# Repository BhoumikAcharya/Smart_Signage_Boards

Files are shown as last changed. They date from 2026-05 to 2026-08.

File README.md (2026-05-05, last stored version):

**Modbus-to-MQTT Bridge for Metro Emergency Signage**

1. Overview Of the Product - 

  This project is a smart EROS, designed for reliable operation in public transit environments like metros and railways. It implements a robust communication bridge on a Raspberry Pi, designed to integrate a central industrial control system (using Modbus) with a distributed network of wireless emergency signs (using MQTT), all through ethernet connectivity. Making the product implemented on a complete local network.
  
  This architecture allows a PLC or a central control room to instantly and reliably activate or change emergency signage across multiple locations in a station or tunnel, using a combination of industrial-grade protocols and modern IoT technology.

2. System Architecture

  The project is built on a decoupled, hub-and-spoke architecture, which is ideal for critical systems:

  Central Control (PLC/Modbus Master): The primary industrial controller, located in a central control room. It initiates commands by sending standard Modbus "Write Multiple Holding Registers (16(0x10))" requests to the Raspberry Pi.
    
  2.1. Raspberry Pi (The Bridge & Broker): This is the core of the system and performs three critical roles simultaneously.
    
  2.2. Modbus TCP Server: A Python script runs continuously, listening for commands from the central controller and updating an internal data model.
    
  2.3. MQTT Broker: The industry-standard Mosquitto broker runs as a service, managing all communication with the wireless signage units.
    
  2.4. Industrial HMI: A 7inch Capacitive touch HMI is connected to the RaspberryPi with manual override.
    
  2.5. Emergency Signs (ESP32 Clients): Each emergency light signage unit is powered by an ESP32.
    
  2.6. The ESP32s connect to the Raspberry Pi over Ethernet with a ETH PHY module called the LAN8720 with MQTT communication.
    
  2.7. They subscribe to specific MQTT topics and wait for commands.
    
  2.8. They are responsible for the final physical action—activating the LEDs via a relay.

3. Features - 
  
  3.1. Protocol Bridging: Seamlessly translates industrial-grade Modbus TCP commands into lightweight MQTT messages suitable for wireless IoT devices.
  
  3.2. Real-Time, Reliable Control: Uses a multi-threaded approach on the Raspberry Pi to ensure low latency between receiving a Modbus command and publishing the corresponding MQTT message.
  
  3.3. Scalable: Easily add or remove signage units across a station without any changes to the central controller or bridge logic. Each sign only needs to know the broker's address and its unique topic.
  
  3.4. Decoupled & Robust: The central controller does not need to know anything about the individual signs, and the signs do not need to know about the controller. This separation makes the system highly reliable and easy to maintain.
  
  3.5. Custom Logic: The bridge script contains specific control logic, allowing complex actions to be easily implemented.
  
  3.6. Diagnostics data: Diagnostics data of the LEDs, ESP32, PSU Failure and the Battery(battery diagnostics still in development) are communicated through MQTT to the RaspberryPi.

4. Hardware Components - 

  This is the list of components that i have used (feel free to experiment on your own as well)
  
    Raspberry Pi 5(8GB RAM with Ethernet)
    
    ESP32 Development Board (DevKit 1)
    
    LAN8720 ETH PHY Module for the ESP32
    
    2x ACS712 5A/20A Current Sensor
    
    5V Dual Channel Relay Modules (to switch power to the LED signage)
    
    2x 12V 12W LEDs
    
    PLC or Modbus Master Simulator (like OpenModscan) for testing
    
    14.5V PSU (Preferrably a battery charger w/o XT60 connectors)
    
    12.8V LFP Battery (For ample battery backup)
    
    7inch Capacitive Touch Display for HMI

5. Software & Libraries - 

  5.1. Raspberry Pi:
  
    Raspberry Pi OS
  
  Python 3
  
    Mosquitto (MQTT Broker)
    
    Pymodbus (Python Modbus Library)
    
    Paho-MQTT (Python MQTT Client Library)
  
  5.2. ESP32:
  
    Arduino IDE or PlatformIO
    
    PubSubClient (Arduino MQTT Library)
  
  5.3. Modbus Master: 
  
    OpenModscan (For testing the control values in the Holding Registers of the PLC)

6. How It Works
  The central control room's PLC sends a Modbus command (e.g., writing a value from 0-3 in a holding regiter(40001-40010)) to the Raspberry Pi's IP address on port 502.

  The Python Modbus server script running on the Pi receives the command and updates its internal datastore.

  A dedicated "bridge" thread in the script detects this state change.

  The script, acting as an MQTT client, connects to the local Mosquitto broker and publishes a message (e.g., payload ON) to a predefined topic (e.g., metro/station1/platformA/emergency_exit/set).

  The Mosquitto broker forwards this message to all signs subscribed to that topic.

  The target ESP32 receives the ON message, and its code executes the physical action—toggling a GPIO pin to activate its connected relay and light up the sign.

7. Setup & Usage (Needs to be updated)
7.1. Raspberry Pi Setup
  Install the necessary software on your Raspberry Pi:

  # Install MQTT Broker
    sudo apt-get update
    sudo apt-get install mosquitto mosquitto-clients -y
    sudo systemctl enable mosquitto.service

    sudo systemctl restart mosquitto.serivce (To restart the mosquitto service)

# Install Python libraries
    pip3 install pymodbus paho-mqtt

  Set the static IP of the RaspberryPi

7.2. ESP32 Setup
  Open the esp32_mqtt_client.ino sketch in the Arduino IDE.

Update the Wi-Fi credentials and the Raspberry Pi's IP address in the configuration section.

Upload the sketch to each of your ESP32 boards. Ensure each sign that needs to be controlled independently is configured to subscribe to a unique MQTT topic.

3. Running the Bridge
Execute the main bridge script on the Raspberry Pi. It requires root privileges to bind to the privileged Modbus port (502).

sudo python3 modbus_mqtt_bridge.py

The system is now live. Commands sent from the PLC will be wirelessly relayed to the emergency signs.

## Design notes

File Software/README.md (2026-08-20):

<div align="center">

# Node Calibration Utility

*Desktop commissioning tool for the I2ST smart-signage system*

**Configure, calibrate and deploy ESP32 edge controllers — over USB serial or the network — and record it only when the device confirms.**

**Version 2.0.0** &nbsp;·&nbsp; Windows Forms (.NET 10) &nbsp;·&nbsp; C# 12 &nbsp;·&nbsp; SQL Server LocalDB







</div>

---

## Table of Contents

1. [Overview](#1-overview)
2. [Architecture & Flow Charts](#2-architecture--flow-charts)
3. [Database Schema](#3-database-schema)
4. [Device Communication](#4-device-communication)
5. [How the Application Works — Module by Module](#5-how-the-application-works--module-by-module)
6. [Core Invariants](#6-core-invariants)
7. [Project Structure](#7-project-structure)
8. [Getting Started](#8-getting-started)
9. [Configuration Reference](#9-configuration-reference)
10. [Engineering Notes](#10-engineering-notes)
11. [Roadmap & Known Limitations](#11-roadmap--known-limitations)
12. [Version History](#12-version-history)

---

## 1. Overview

A metro station's smart-signage system runs on a network of **ESP32-based edge
controllers** — one per signage panel — distributed across **four routes of up to
100 panels each**. Each controller drives relays, monitors two current-sensing
channels and a battery, and publishes its state over MQTT to a Raspberry Pi that
bridges it into Modbus TCP for the station's SCADA system.

Before a controller can join that network it has to be told **who it is**: its
route, its panel location, its panel serial number, the Modbus holding register it
owns, and its static IP address. It also needs per-device **calibration
constants** that convert raw ADC counts into amps and volts.

**Node Calibration Utility** is the tool a technician carries to a panel with a
laptop and a USB cable. It provides:

- a managed record of every panel position and the controller installed at it,
- validated data entry with database-enforced uniqueness,
- configuration deployment over **USB serial** or **Ethernet (OTA)**, recorded as
  done **only after the device acknowledges**,
- administrator-gated calibration with physical range checking,
- role-based access control over a SQL Server database.

The application builds clean — **0 errors, 0 warnings** (down from 80 warnings) —
with nullable reference types enforced on every hand-written line.

---

## 2. Architecture & Flow Charts

### 2.1 High-Level Architecture

```mermaid
flowchart LR
    PRES[Presentation<br/>MainForm shell · 9 UserControl screens<br/>4 dialogs · UserDialog · BusyScope]
    APP[Application<br/>UserSession · AppConfig · AppLogger]
    DATA[Data<br/>Db · AuthRepository · NodeRepository<br/>AreaRepository · PasswordHasher]
    SVC[Services<br/>DeviceConfigurationService<br/>ModbusDiagnosticsService · SettingsService]
    DB[(SQL Server LocalDB<br/>NodeManagementDB)]
    SERIAL[ESP32 · USB serial]
    OTA[ESP32 · HTTP OTA]
    MODBUS[ESP32 · Modbus TCP<br/>via Raspberry Pi gateway]

    PRES --> APP
    APP --> DATA
    APP --> SVC
    DATA --> DB
    SVC --> SERIAL
    SVC --> OTA
    SVC --> MODBUS
```

- **Presentation** — the shell, screens and dialogs; no business logic.
- **Application** — identity and roles (`UserSession`), typed settings
  (`AppConfig`), diagnostic logging (`AppLogger`).
- **Data** — ADO.NET repositories over SQL Server LocalDB, with error
  translation and a start-up health check.
- **Services** — the three transports: serial/OTA deployment, Modbus TCP
  diagnostics, and atomic JSON settings persistence.

### 2.2 Deployment Flow — the path that matters most

```mermaid
flowchart TD
    A[Operator selects an uncalibrated node] --> B{Calibration values supplied?<br/>administrator only}
    B -->|yes| C[Range-checked: sensitivity 0.001–1.0 V/A<br/>battery calibration ±5 V]
    B -->|no| D[Payload carries no calibration keys<br/>device keeps its bench calibration]
    C --> D
    D --> E[Payload built<br/>NodeNumber excluded · calibration keys omitted when absent]
    E --> F[Operator confirms target, transport<br/>and calibration impact]
    F --> G{Transport}
    G -->|USB serial| H[Write JSON · wait for device reply · classify tokens]
    G -->|HTTP OTA| I[POST /config · HTTP status is the acknowledgement]
    H --> J{Device acknowledged<br/>within DeviceAckTimeoutMs?}
    I --> J
    J -->|no| K[Report unconfirmed · database unchanged<br/>device's raw reply echoed to the monitor]
    J -->|yes| L[Store calibration · set Calibration = 1<br/>node leaves the uncalibrated list]
```

### 2.3 Sign-in & Access Control

```mermaid
flowchart TD
    A[Launch] --> B[Database health check<br/>unreachable DB reported immediately]
    B --> C[MainForm shown · protected screens disabled]
    C --> D[Sign in with username and password]
    D --> E{Hash verified?<br/>PBKDF2 · fixed-time comparison}
    E -->|no| F[Rejected · failure logged]
    E -->|yes| G{Legacy SHA-256 hash?}
    G -->|yes| H[Transparently upgraded to PBKDF2<br/>in the same sign-in]
    G -->|no| I[Session established]
    H --> I
    I --> J[Screens unlocked per role<br/>calibration is administrator-only]
```

---

## 3. Database Schema

`NodeManagementDB` on SQL Server LocalDB. The application reads it as it stands —
the schema was not changed by this work.

### 3.1 `Users`

| Column | Type | Constraints |
|---|---|---|
| Id | INT | PK, IDENTITY |
| Username | NVARCHAR(50) | UNIQUE, NOT NULL |
| PasswordHash | NVARCHAR(255) | NOT NULL |
| FullName | NVARCHAR(100) | NOT NULL |
| CreatedAt | DATETIME | DEFAULT GETDATE() |

`PasswordHash` holds either a legacy 64-character SHA-256 hex string or a PBKDF2
record of the form `PBKDF2$<iterations>$<base64 salt>$<base64 hash>`. Both are
accepted; legacy rows are upgraded on their next successful sign-in. The column
is already wide enough for the PBKDF2 format, so **no migration is required**.

### 3.2 `Areas` — 400 pre-seeded rows (4 routes × 100 panels)

| Column | Type | Constraints |
|---|---|---|
| Id | INT | PK, IDENTITY |
| Route | INT | NOT NULL |
| PanelLocation | INT | NOT NULL |
| HoldingRegister | INT | UNIQUE, NOT NULL |
| PanelSerialNumber | INT | UNIQUE, NOT NULL |
| Description | NVARCHAR(255) | NULL |

Plus `UNIQUE(Route, PanelLocation)`.
`HoldingRegister = 40000 + (Route-1)×100 + PanelLocation`, assigned at seed time
and treated as immutable — the firmware and the Modbus bridge both key off it.

### 3.3 `Nodes`

| Column | Type | Default |
|---|---|---|
| Id | INT | PK, IDENTITY |
| NodeNumber | INT | UNIQUE, NOT NULL |
| PanelSerialNumber | INT | UNIQUE, NOT NULL, FK → `Areas` |
| LocalIPAddress | NVARCHAR(15) | UNIQUE, NOT NULL |
| Zerovolt_CS1 / _CS2 | FLOAT | 2.40 |
| Sensitivity_CS1 / _CS2 | FLOAT | 0.105 |
| Threshold_CS1 | FLOAT | 0.100 |
| Threshold_CS2 | FLOAT | 0.120 |
| BatteryCalibration | FLOAT | 0.0 |
| BatterySagCompensation | FLOAT | 0.0 |
| PSUThreshold | INT | 1800 |
| Calibration | BIT | 0 |

Database column names are retained; the C# model uses conventional casing
(`ZeroVoltCs1`, `IsCalibrated`) and maps explicitly in the repository.

`Calibration` is set to **1 only after a controller has confirmed** its
configuration — never on a successful write alone.

---

## 4. Device Communication

### 4.1 Configuration payload

The JSON sent to the ESP32. Two properties are load-bearing:

```json
{
  "Route": 2,
  "PanelLocation": 5,
  "PanelSerialNumber": 40005,
  "HoldingRegister": 40005,
  "Description": "Platform 3, Column B",
  "LocalIP": "192.168.1.105"
}
```

- **`NodeNumber` is deliberately absent.** The controller derives its node
  identity from the holding register; a second source of truth could disagree
  with the first.
- **Calibration keys are omitted entirely unless an administrator supplied
  them.** The firmware overwrites a stored constant only when its key is
  present, so an absent key preserves the bench calibration. Sending nulls or
  zeros would wipe it. This is enforced by
  `[JsonIgnore(JsonIgnoreCondition.WhenWritingNull)]`, not by convention. With
  calibration, three keys appear: `Sensitivity_CS1`, `Sensitivity_CS2`,
  `BatteryCalibration`.

Reset payload: `{"ResetConfig": true}` — clears stored preferences and restarts.

The controller restarts unconditionally after accepting configuration.

### 4.2 Transports

| Transport | Details |
|---|---|
| USB serial | 115200 8-N-1, newline-terminated JSON, configurable acknowledgement timeout |
| HTTP OTA | `POST http://<device-ip>/config`, 5-second timeout, response body reported on failure |
| Modbus TCP | via the Raspberry Pi gateway on port 502, explicit connect timeout |

### 4.3 Diagnostic register map

Zero-based addresses. Node *N* occupies six registers from `5000 + (N-1)×6`:

| Offset | Meaning |
|---|---|
| +0 | Status (1 = ONLINE) |
| +1 | Power (1 = OK) |
| +2 | Current channel 1 (1 = OK) |
| +3 | Current channel 2 (1 = OK) |
| +4 | Battery percentage (0 / 50 / 100) |
| +5 | Relay status (bit 0 = relay 1, bit 1 = relay 2) |

Control ranges: MUX at `3000` (Modbus 43001), manual relays from `1000`
(Modbus 41001), SCADA from `2000` (Modbus 42001).

---

## 5. How the Application Works — Module by Module

### 5.1 Node Management

- Route-filtered grid of every installed controller, joined to its panel
  position.
- Add, edit and delete with full validation: IPv4 format, positive node
  numbers, uniqueness on node number, IP address and panel serial number.
- **Uncalibrated nodes are highlighted** in the grid, so outstanding
  commissioning work is visible at a glance — exactly where the person who has
  to act on it is looking.
- Double-click a row to edit.
- Records are re-read before an edit opens, so a node changed or removed from
  another workstation is detected instead of silently overwritten.

### 5.2 Area (Panel Position) Management

- All 100 panel positions for a selected route, from a table pre-seeded with
  every route/panel combination.
- Panel serial number and description are editable; route, panel location and
  holding register are read-only, because the firmware and the Modbus bridge
  both key off the register mapping.
- Changing a serial number requires explicit confirmation — it re-points the
  node foreign key and must match the number physically stencilled on the panel.

### 5.3 Configuration Deployment

- **Two transports**: USB serial for bench and on-panel work, HTTP OTA for
  controllers already on the network.
- **Acknowledgement required.** A deployment is recorded as successful only
  once the controller confirms it. Writing bytes to a COM port proves nothing
  about the device having received or accepted them, so the tool waits for the
  reply and classifies it — confirmation tokens (`config saved`, `restarting`,
  …) succeed; rejection tokens (`error`, `invalid`, `bad json`, …) fail; no
  reply or an unrecognised reply is reported as **unconfirmed**. On any outcome
  other than success the node is explicitly *not* marked as calibrated and the
  device's raw reply is echoed to the serial monitor so the operator can see
  why.
- Live serial monitor with the device's own output.
- Pre-deployment confirmation stating the target, the transport, and whether
  calibration will be overwritten or preserved — the controller restarts on
  accepting a payload.
- Reset-to-defaults command that clears the controller's stored preferences.

### 5.4 Calibration Control

- **Administrator-only.** Calibration changes the meaning of every reading a
  node publishes, so it is deliberately restricted.
- Current values are pre-loaded from the database, so an operator adjusts from
  what the device is actually running rather than typing into empty boxes.
- **Range-checked before transmission**: sensitivity is bounded to 0.001–1.0
  V/A (the ACS712-class sensors on these panels sit in the tens-to-hundreds of
  mV/A) and battery calibration to ±5 V — so a typo or a wrong unit is caught
  before it silently corrupts every subsequent measurement.
- Calibration keys are **omitted** from the payload unless supplied, because
  the firmware preserves any constant whose key is absent.

### 5.5 Authentication & Access Control

- Sign-in against the SQL Server `Users` table.
- **PBKDF2-HMAC-SHA256** password hashing with a 16-byte random salt and
  600,000 iterations (OWASP's 2023 figure), verified in fixed time.
- **Backward compatible**: legacy unsalted SHA-256 rows still authenticate and
  are transparently upgraded to PBKDF2 on the next successful sign-in — the one
  moment the plaintext is available. No user has to reset anything, and a
  failed upgrade is logged without blocking the sign-in.
- Protected screens are genuinely gated. Access control lives in `UserSession`
  and is applied by `MainForm.ApplySessionState()`; `NavigateProtected()`
  refuses to open a protected screen and explains why. Home remains available
  so there is always somewhere to be.
- Admin status is decided in one place — `UserSession.CanCalibrate` — rather
  than by a string comparison inside a form.

### 5.6 Modbus Diagnostics

- Reads each node's 6-register diagnostic block — status, power, both current
  channels, battery percentage and relay state — through the Raspberry Pi
  gateway.
- Writes to the MUX, manual relay and SCADA register ranges.
- Connect timeout applied explicitly, because `TcpClient` has none of its own
  and an unreachable gateway would otherwise block for the OS default (~20 s).
- Connections are owned and disposed correctly; a reconnect is forced after any
  failure.

### 5.7 Settings & Network Configuration

- Technician contact details and maintenance-notification preferences.
- Ethernet and Wi-Fi parameters, with the Wi-Fi group shown only when enabled
  and the pre-shared key **masked** — a visible PSK on a shared commissioning
  workstation is a real exposure.
- Every populated address field is validated as a genuine dotted-quad IPv4 — a
  controller that comes up on the wrong subnet has to be recovered over USB on
  site.
- Persisted atomically to per-user application data (temp file then replace),
  so an interrupted save cannot leave a file that fails to parse on next
  launch.

### 5.8 Operational Robustness

- **Responsive UI.** Every database and device call is asynchronous with
  `CancellationToken` support; controls cancel in-flight work when torn down,
  so a query that returns after a screen closed cannot touch a disposed
  control. `BusyScope` restores busy state on dispose even if the operation
  throws.
- **Diagnostic logging.** A dated rolling file log under `%LOCALAPPDATA%`
  (pruned to 14 files) records every repository failure, deployment attempt,
  device reply and rejected sign-in.
- **Survivable errors.** `Program` installs handlers for thread, unhandled and
  unobserved-task exceptions — a UI-thread fault is reported and the operator
  keeps their other work.
- **Start-up health check.** An unreachable database or missing tables is
  reported immediately, not as a stack trace on first use.
- **Single instance.** A named mutex prevents two copies competing for the same
  COM port and sending conflicting configuration to one controller.
- **Externalised configuration.** Connection string, gateway address, baud
  rate, timeouts and route counts all live in `appsettings.json`; retargeting a
  deployment needs no rebuild.

---

## 6. Core Invariants

1. **`NodeNumber` is never sent to the controller.**
2. **Calibration keys are omitted unless explicitly supplied.** An absent key
   preserves the device's stored value.
3. **`Calibration = 1` is written only after the device acknowledges.** Never
   on a successful write alone.
4. **`HoldingRegister` is immutable** — the firmware and the Modbus bridge both
   key off it.
5. **`Areas` is update-only.** Never inserted into or deleted from at runtime.
6. **`Nodes.PanelSerialNumber` is not updatable.** Moving a controller is a
   delete-and-re-add.
7. **Node number, IP address and panel serial number are each unique**, enforced
   by the database — pre-checks exist for better error messages, but unique
   constraints are the actual guarantee, with constraint violations returned as
   a normal outcome naming the offending field.
8. **Machine-facing values use `InvariantCulture`.** Node numbers, IP addresses
   and register values must not vary with the operator's regional settings.
9. **Calibration is administrator-only.**
10. **Dialogs validate and collect; callers persist.** A dialog never writes to
    the database itself.

---

## 7. Project Structure

```
CompanyUtilityApp/
├─ CompanyUtilityApp.csproj      metadata, analyser policy, config copying
├─ appsettings.json              all externalised settings
├─ Program.cs                    entry point, global exception handling
│
├─ Configuration/
│  └─ AppConfig.cs               strongly typed settings loader
│
├─ Models/
│  ├─ User.cs · Area.cs · Node.cs
│  ├─ ViewModels.cs              grid projections
│  ├─ DeviceConfigurationPayload.cs   firmware contract + calibration validation
│  └─ Settings.cs                preferences + IPv4 validation
│
├─ Security/
│  └─ PasswordHasher.cs          PBKDF2 with legacy SHA-256 migration
│
├─ Data/
│  ├─ Db.cs                      connection factory, error translation, health check
│  ├─ AuthRepository.cs          authentication, transparent hash upgrade
│  ├─ AreaRepository.cs
│  └─ NodeRepository.cs          node CRUD, calibration status
│
├─ Services/
│  ├─ DeviceConfigurationService.cs   serial + OTA deployment (ack-gated)
│  ├─ ModbusDiagnosticsService.cs     Modbus TCP reads/writes (IDisposable)
│  └─ SettingsService.cs              atomic JSON persistence
│
├─ Infrastructure/
│  ├─ AppLogger.cs               rolling file logger
│  └─ UserSession.cs             session state + role gating
│
├─ UI/
│  └─ UserDialog.cs              dialog helpers + BusyScope
│
├─ Forms/                        MainForm · LoginForm · AddEditNodeForm · EditAreaForm
├─ UserControls/                 Home · Node · Area · PanelSettings · Settings
│                                Network · Tests · IOActivity · Transfer
├─ Properties/ · Resources/      icons and resources
└─ DocumentFiles/                user manual PDF
```

Around **5,400 lines of hand-written C# across 22 files**, plus
designer-generated layout. Namespaces match folders
(`CompanyUtilityApp.Forms`, `.UserControls`, `.Data`, …) — a resource-lookup
bug depended on this, see §10.

---

## 8. Getting Started

### 8.1 Prerequisites

- Windows 10 or 11
- [.NET 10 SDK](https://dotnet.microsoft.com/download)
- SQL Server LocalDB (ships with Visual Studio, or the standalone *SQL Server
  Express LocalDB* installer)
- A USB cable for serial deployment, or network reachability for OTA

### 8.2 Database setup

Create `NodeManagementDB` with the three tables in [§3](#3-database-schema),
then:

1. Seed `Areas` with all 400 route/panel rows.
   `HoldingRegister = 40000 + (Route-1)×100 + PanelLocation`.
2. Insert at least one row into `Users`. Both password formats are accepted, so
   existing credentials work unchanged and are upgraded to PBKDF2 on first
   sign-in.

### 8.3 Build and run

```powershell
git clone <repository-url>
cd CompanyUtilityApp\CompanyUtilityApp

dotnet build     # expect 0 errors, 0 warnings
dotnet run
```

If the database is unreachable or tables are missing, the application says so
at start-up rather than failing later.

### 8.4 Runtime paths

| What | Where |
|---|---|
| Configuration | `appsettings.json`, beside the executable |
| Logs | `%LOCALAPPDATA%\I2ST\NodeCalibration\logs` |
| Settings | `%LOCALAPPDATA%\I2ST\NodeCalibration\settings.json` |

---

## 9. Configuration Reference

All of `appsettings.json` is editable without a rebuild. A malformed file falls
back to built-in defaults and reports why, rather than refusing to start — a
site engineer should not be stranded by a stray comma.

```json
{
  "Database": {
    "ConnectionString": "Server=(localdb)\\MSSQLLocalDB;Database=NodeManagementDB;Integrated Security=true;TrustServerCertificate=true",
    "CommandTimeoutSeconds": 30
  },
  "Modbus": {
    "GatewayHost": "192.168.1.10",
    "Port": 502,
    "SlaveId": 1,
    "ConnectTimeoutMs": 3000,
    "ReadWriteTimeoutMs": 3000
  },
  "Serial": {
    "BaudRate": 115200,
    "DataBits": 8,
    "Parity": "None",
    "StopBits": "One",
    "ReadTimeoutMs": 2000,
    "WriteTimeoutMs": 2000,
    "DeviceAckTimeoutMs": 8000
  },
  "Ota": {
    "RequestTimeoutSeconds": 5,
    "ConfigEndpoint": "/config"
  },
  "Routes": {
    "Count": 4,
    "PanelsPerRoute": 100
  },
  "Logging": {
    "MinimumLevel": "Information",
    "RetainedFileCount": 14
  }
}
```

**`DeviceAckTimeoutMs`** is the one worth knowing about: it is how long the tool
waits for a controller to confirm a serial deployment before reporting it
unconfirmed.

---

## 10. Engineering Notes

A few decisions that are easy to misread as arbitrary:

**A serial write is not a deployment.** `SerialPort.Write` returning without
throwing only means the bytes reached the local UART buffer. An unplugged
cable, a device in bootloader mode, or a rejected payload all produce a
successful write. Since a node marked as calibrated disappears from the
deployment list, trusting the write would make a failed commissioning
invisible. The tool therefore waits for the controller's own reply — classified
against deliberately adjustable token sets — and only then records success.

**Uniqueness is enforced by the database, not by a pre-check.** A
check-then-write leaves a window in which another workstation can take the
value. The pre-checks are kept for their better error messages, but a
constraint violation (SQL 2627/2601) is caught and returned as a normal outcome
with a message naming the offending field, parsed from the index name.

**Settings live in `%LOCALAPPDATA%`, not beside the binary.** A Program Files
directory is not writable by a standard user; saving next to the executable
either fails or silently triggers UAC virtualisation.

**Namespaces must match folders — and a bug proved it.** `MainForm.Designer.cs`
resolved embedded resources with `ComponentResourceManager`, which looks up
`<class namespace>.MainForm.resources` while the embedded resource name is
derived from `RootNamespace` + folder path. The file lived in `WindowForms\`
under namespace `CompanyUtilityApp`, so the lookup silently failed and the
toolbar icon never loaded — except in the one control that happened to declare
the matching namespace. Renaming `WindowForms\` → `Forms\` and aligning
namespaces to folders throughout fixed it. This is why the namespace
normalisation was worth doing.

**Machine-facing values are formatted with `InvariantCulture`.** Node numbers,
IP addresses and register values must not vary with the operator's regional
settings.

**Nullable reference types are enforced, and generated files are excluded.**
Designer fields are assigned inside `InitializeComponent()`, where the analyser
cannot see them, so designer files carry `#nullable disable` — the approach the
WinForms templates themselves use. Hand-written code is fully checked, with the
CS86xx nullable set as `WarningsAsErrors`. The build went from 80 warnings to
clean.

---

## 11. Roadmap & Known Limitations

| Area | Status |
|---|---|
| Node management | Complete |
| Area management | Complete |
| Configuration deployment (serial + OTA) | Complete — **pending hardware validation** |
| Calibration control | Complete |
| Authentication and access control | Complete |
| Settings / network configuration | Complete |
| Modbus transport | Complete — untested against a live gateway |
| Operation and endurance tests | Planned — transport in place, UI outstanding |
| Live I/O activity view | Planned |
| CSV import / export | Planned — export first; import awaits per-row validation and rollback |

**The single most important thing to test before trusting the tool on site** is
the deployment acknowledgement against a real controller: the reply
classification is written against the documented firmware behaviour and has not
been observed against live hardware. If the firmware's actual output does not
contain the expected tokens, deployments will be reported as unconfirmed even
when they succeeded. The token lists are near the top of
`DeviceConfigurationService` and are deliberately easy to adjust.

Other known follow-ups:

- **Migrate from `NModbus4` to `NModbus`.** The former ships .NET Framework
  binaries only and runs on `net10.0` through the compatibility shim (NU1701,
  suppressed with justification in the csproj). The change is contained to
  `ModbusDiagnosticsService` but needs gateway testing.
- **Add a role column to `Users`.** Administrator status is currently inferred
  from the username (documented in `Models\User.cs`).
- **Add a test project.** There is none; two methods containing SQL that
  referenced non-existent columns survived in the codebase precisely because
  nothing exercised them.
- **Consider an audit trail.** Node changes and deployments are logged to file,
  but nothing records who changed what in the database.

---

## 12. Version History

| Version | Date | Highlights |
|---|---|---|
| **2.0.0** | 2026-08-20 | Security and reliability overhaul: PBKDF2 password hashing with legacy migration · acknowledgement-gated deployment (serial write alone no longer marks a node calibrated) · session-based access control (previously commented out) · fully asynchronous data layer · rolling diagnostics log and survivable crash handling · two inert settings screens wired to real persistence · config externalised to `appsettings.json` · 80 warnings eliminated |

This repository begins at **v2.0.0**; the pre-refactor version is not part of
this history.

---

<div align="center">
  <strong>Node Calibration Utility</strong> · I2ST Technologies Pvt. Ltd. © 2026
</div>

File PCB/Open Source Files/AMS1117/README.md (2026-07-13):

📦 Repository Contents
Regulator.kicad_sch – KiCad schematic
Regulator.kicad_pcb – KiCad PCB layout
<br>

## Sponsored by PCBWay
This project sponsored by [PCBWay](https://www.pcbway.com), who supported the prototyping of this board.  
Special thanks to Liam from PCBWay’s marketing team for facilitating the collaboration.

## 🖼️ Previews

### Schematic
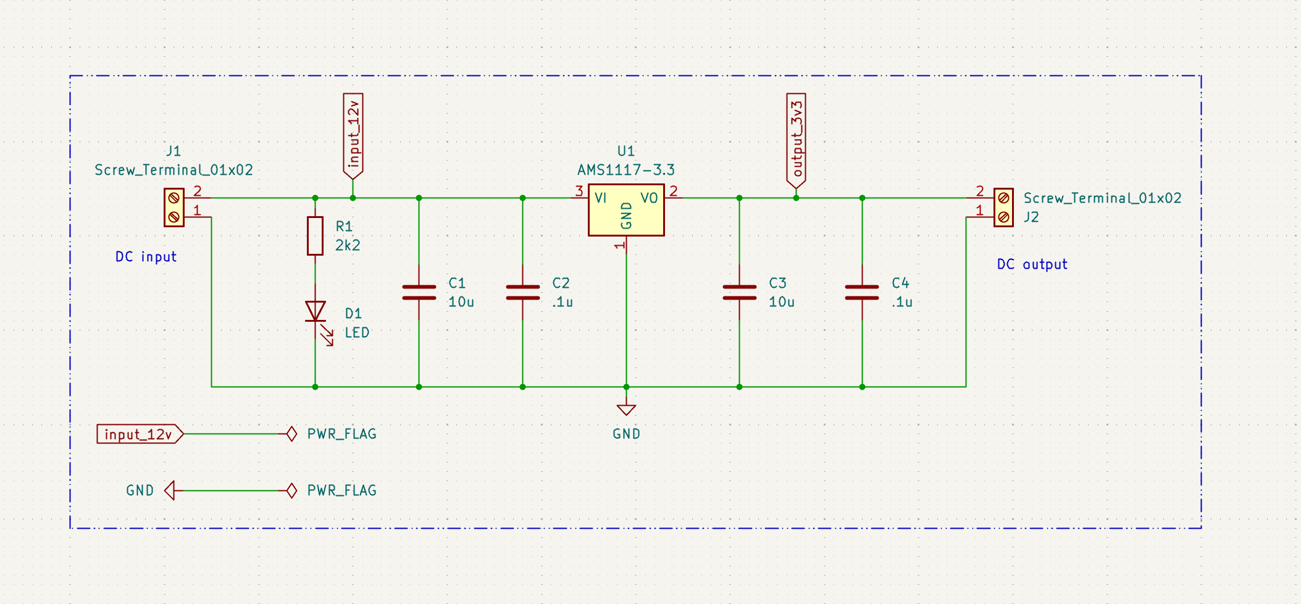
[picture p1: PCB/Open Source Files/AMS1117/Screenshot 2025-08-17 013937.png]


### PCB
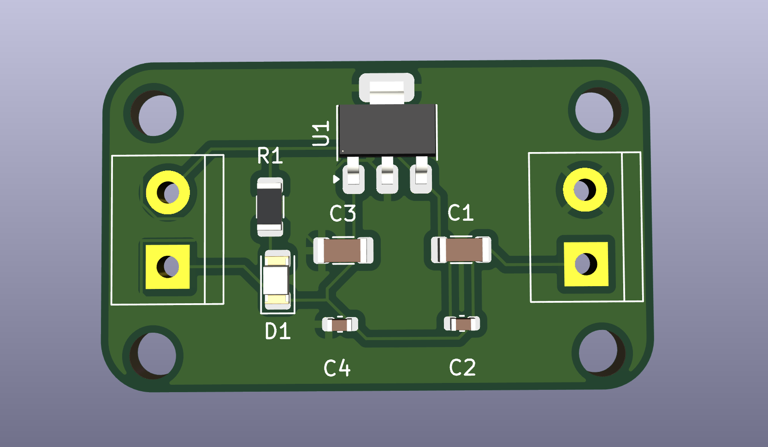
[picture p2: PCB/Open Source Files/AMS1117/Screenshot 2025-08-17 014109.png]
Top
  
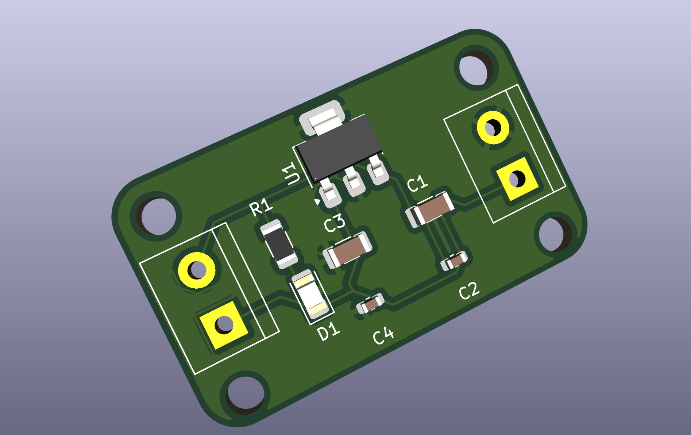
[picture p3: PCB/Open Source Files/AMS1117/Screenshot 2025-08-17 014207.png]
Bottom
  
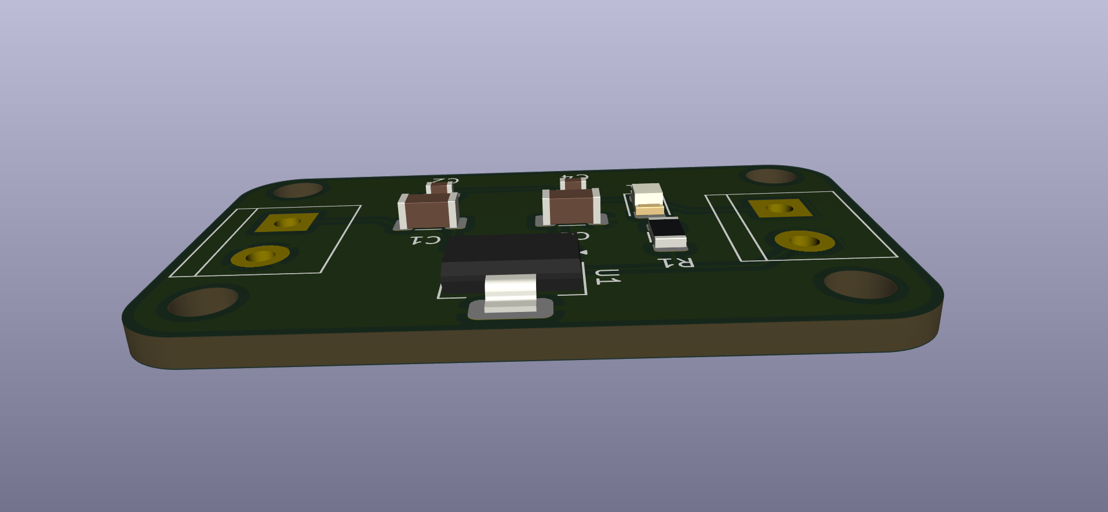
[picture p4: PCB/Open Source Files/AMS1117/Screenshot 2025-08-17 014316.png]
3D View 1
  
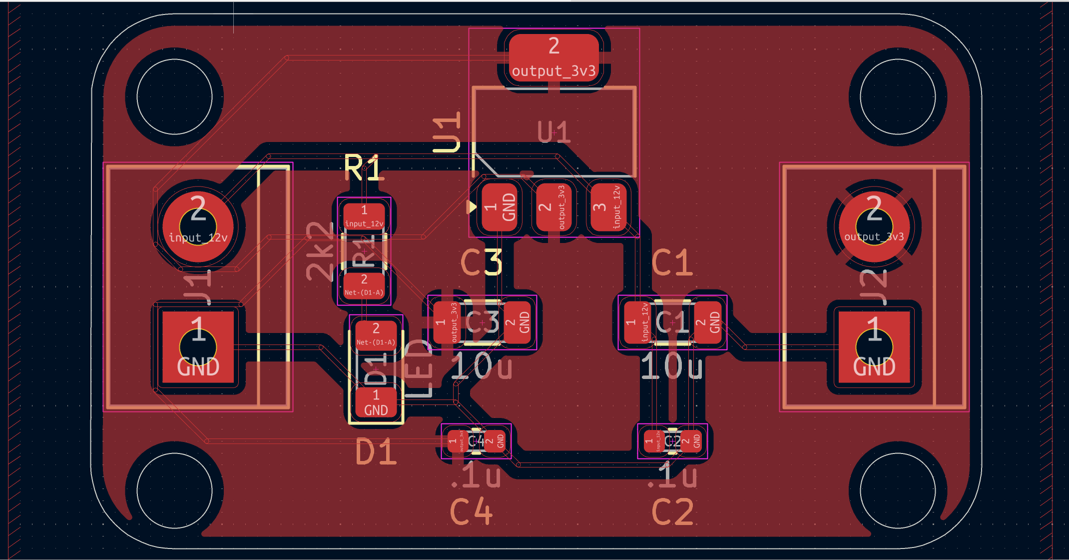
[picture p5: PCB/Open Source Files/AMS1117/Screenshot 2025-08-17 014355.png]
3D View 2


### photos of the bare PCBs
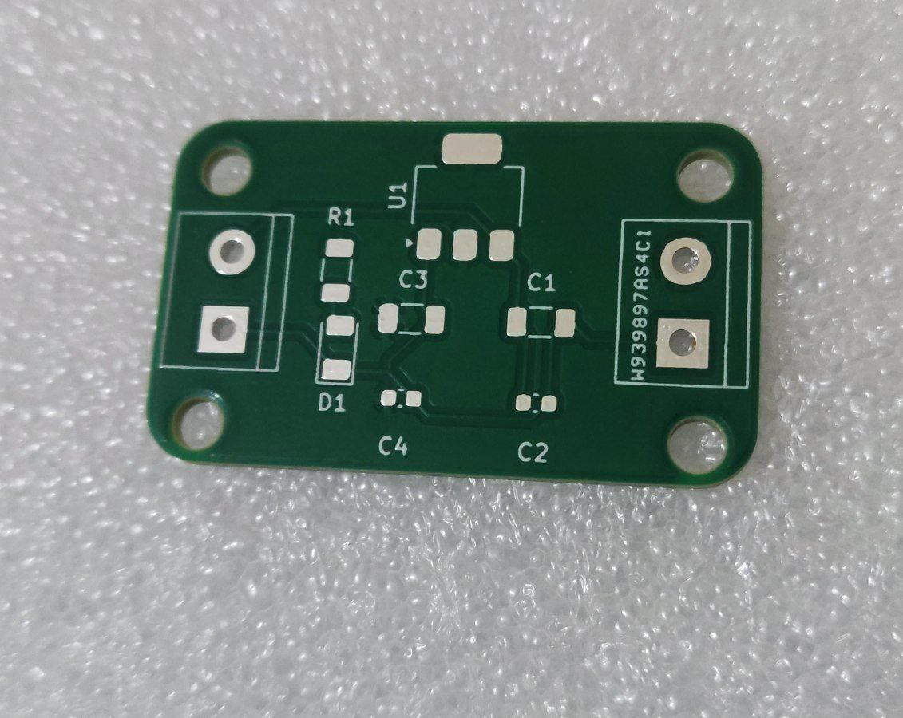
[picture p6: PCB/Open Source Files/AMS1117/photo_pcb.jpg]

### PCBWay Sponsorship & Quality Review

These boards were kindly sponsored by PCBWay

🟢 Quality: The PCBs arrived with sharp silkscreen, smooth edges, and consistent solder mask — even for the fine-pitch pads.

🟢 Service: Communication with the PCBWay team (special thanks to Liam 🙏) was very fast and helpful at every step.

🟢 Delivery: The shipping was reliable and the boards were safely packed.

I haven’t soldered components yet (waiting for my kit to arrive), but I’m already impressed with the build quality. Once assembly and testing are complete, I’ll share performance measurements and final photos.
**⚙️ Typical Specs (AMS1117-3.3 based) :**

Output: 3.3 V fixed

Input: (commonly) ≥ 4.5 V up to around 12 V (observe power dissipation!)

Dropout: ~1.1–1.3 V (load-dependent)

Max current: up to 1 A electrically, but thermally limited by SOT-223 and copper area

Thermal tip: Keep large copper under/around the tab (pin 2) for heat spreading; derate current for higher VIN–VOUT.

<br>
<br>

**🧠 How the Circuit Works :**

Input (J1) receives unregulated DC.

C1/C2 provide input bulk and high-frequency decoupling close to U1.IN.

U1 (AMS1117-3.3) regulates to 3.3 V at U1.OUT.

C3/C4 provide output bulk and HF bypass close to U1.OUT for stability and transient response.

LED D1 + R1 connect to the 3.3 V output as a power-good indicator.

Output (J2) provides the regulated 3.3 V and GND to your load.

<br>
<br>

**✨ Author:**

Awab — @AWABEEE

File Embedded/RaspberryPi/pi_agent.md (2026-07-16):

# Raspberry Pi Gateway Platform — Verified Contract

**Status:** Base platform commissioned and verified 2026-07-14.
**Scope:** Raspberry Pi 5 host running the headless Gateway daemon (`Pi.py`) and the Tkinter HMI (`HMI.py`).
**Audience:** Firmware/coding agent. Everything below is either *verified on the target hardware* or *explicitly flagged as open*. Do not assume anything not stated here.

---

## 1. Platform Baseline (verified)

| Item | Value | How verified |
| --- | --- | --- |
| Board | Raspberry Pi 5 Model B Rev 1.1 | `/proc/device-tree/model` |
| OS | Debian GNU/Linux 13 (trixie) | `/etc/os-release` |
| Python | 3.13.5 | `python3 --version` |
| Network stack | NetworkManager (dhcpcd + systemd-networkd both inactive) | `systemctl is-active` |
| MQTT broker | Mosquitto 2.0.21 | `apt` |
| Venv path | `~/metro-gw/venv` | — |

**PEP 668 is enforced.** The system Python refuses `pip install`. All Python work happens in the venv, which was created with `--system-site-packages` so it can see the apt-installed `python3-tk` (Tkinter cannot be pip-installed; the HMI dies at import without it).

---

## 2. Pinned Dependencies — DO NOT UPGRADE BLINDLY

```
paho-mqtt==2.1.0
pymodbus==3.11.3
```

### Why pymodbus is pinned to 3.11.3 (not latest)

The Gateway's MUX loop reads and writes the Modbus server's datastore from a worker thread:

```python
mux_flag = modbus_context[0].getValues(3, 3000, count=1)[0]
modbus_context[0].setValues(3, 0, hmi_values)
```

This pattern was tested against every 3.x major:

| pymodbus | `ModbusSlaveContext` | `context[0]` | `getValues`/`setValues` | Verdict |
| --- | --- | --- | --- | --- |
| 3.6.9 – 3.9.2 | present | works | works | runs unmodified |
| **3.11.3** | renamed `ModbusDeviceContext` | works | works | **PINNED — 2-line change** |
| 3.14.0 | **gone** | **raises** | **does not exist** | **hard fail** |

In 3.14.0 `ModbusServerContext` is not subscriptable and `ModbusDeviceContext` has **no** `getValues`/`setValues` methods at all. The replacements (`ServerContext.async_getValues/async_setValues`) return `DEVICE_BUSY` for anything that is not a simulator context. The entire datastore-poking design has no supported API path in 3.14.

**Future work (not now):** 3.11.3 emits deprecation warnings — `ModbusDeviceContext`, `ModbusServerContext`, and the data blocks are all removed in pymodbus v4, replaced by `SimData`/`SimDevice`. Migrating is a rewrite of the bridge core, deliberately deferred.

Freeze with `pip freeze > ~/metro-gw/requirements.txt`. A silent `pip install --upgrade` is how a working installation stops working.

---

## 3. VERIFIED: There is no Modbus off-by-one

Tested with a real pymodbus 3.11.3 server and a real client over TCP:

```
setValues(3, 0,    [0xBEEF])  ->  wire address 0     reads 0xBEEF
setValues(3, 3000, [0xCAFE])  ->  wire address 3000  reads 0xCAFE
```

> **Datastore index == Modbus wire address == PLC register number − 40001.**

No `+1` adjustment anywhere, in any direction. `Pi.py`'s existing address arithmetic is correct. Do not "fix" it.

---

## 4. Modbus Register Map (authoritative)

Single Modbus device, `single=True` — one device context answers on **every** unit ID. The Pi is *one* Modbus device presenting 100 nodes as register offsets, **not** 100 Modbus units. The PLC's unit-ID setting is irrelevant.

Node index `i` is 0-based (`i = 0` is node 1 / register 40001).

| Block | PLC registers | Datastore index | Written by | Read by |
| --- | --- | --- | --- | --- |
| Active Execution Zone | `40001–40100` | `0 + i` | Gateway (MUX output) | Gateway → MQTT |
| HMI Manual Buffer | `41001–41100` | `1000 + i` | HMI | Gateway (MUX) |
| **SCADA Auto Buffer** | `42001–42100` | `2000 + i` | **PLC** | Gateway (MUX) |
| MUX Control Flag | `43001` | `3000` | HMI / PLC | Gateway |
| Diagnostic Block | `45001–45700` | `5000 + (i * 7)` | Gateway | PLC / HMI |

`HR_SIZE = 6000` (indices 0–5999). Covers the diag block end at index 5699. Sequential block; the gaps are intentionally unused.

Only `hr` (holding registers) is populated. `di`/`co`/`ir` are left `None`, so a PLC attempting to read coils or input registers gets a Modbus exception rather than a silent zero. This is deliberate — it fails loudly on a misconfigured PLC.

### MUX semantics (register 43001)

| Value | Mode | Gateway behaviour |
| --- | --- | --- |
| `0` | SCADA / Auto | copies `42001+` → `40001+` |
| `1` | HMI / Manual | copies `41001+` → `40001+` |

### Command value encoding (40001/41001/42001 zones)

Per-node relay state, 2 bits:

| Value | Relay 1 (LHS) | Relay 2 (RHS) |
| --- | --- | --- |
| `0` | OFF | OFF |
| `1` | ON | OFF |
| `2` | OFF | ON |
| `3` | ON | ON |

### Diagnostic Block layout — 7 registers per node

Base index for node `i` = `5000 + (i * 7)`.

| Offset | Register (node 1) | Content | Encoding |
| --- | --- | --- | --- |
| +0 | 45001 | Network Status | `1` = Online, `0` = Offline |
| +1 | 45002 | Main Power | `1` = OK, `0` = PSU Fail |
| +2 | 45003 | LHS LED Health | 4-state (below) |
| +3 | 45004 | RHS LED Health | 4-state |
| +4 | 45005 | Battery Percentage | `0`–`100` |
| +5 | 45006 | **Static Zone 1** Health | 4-state |
| +6 | 45007 | **Static Zone 2** Health | 4-state |

Node 1 → `45001–45007`. Node 2 → `45008–45014`. Node 100 → `45694–45700`.

**4-state discrepancy encoding:**

| String (MQTT) | Int (Modbus) | Meaning |
| --- | --- | --- |
| `OFF` | `0` | Intended OFF, no current |
| `ON` | `1` | Intended ON, current flowing |
| `FAIL_OPEN` | `2` | Intended ON, 0 A — broken wire / burnt LED / blown MOSFET |
| `FAIL_SHORT` | `3` | Intended OFF, current flowing — welded MOSFET / short to power |
| *(unknown / `---`)* | `99` | Unparseable or node offline |

---

## 5. MQTT Topic Contract (authoritative)

Broker: Mosquitto 2.0.21. Gateway and HMI connect to `127.0.0.1:1883`. ESP32 nodes connect to `192.168.1.10:1883`.

### Address format — CRITICAL

> `<address>` in every topic is the **holding-register number** (`40001 + i`), **NOT** the node index.

Node 1 is `metro/signage/register/40001/power`. It is **not** `register/1/power`.

If firmware and gateway disagree on this, **nothing matches, every node reads OFFLINE, and no error is logged anywhere in the system.** It simply, silently, does not work. This is the single most dangerous mismatch in the project.

### Telemetry — ESP32 publishes, Gateway + HMI subscribe

`metro/signage/register/<40001+i>/<metric>`

| Metric | Payload | Notes |
| --- | --- | --- |
| `status` | `ONLINE:<ip>` or `OFFLINE` | Gateway parses the IP out of the `ONLINE:` prefix |
| `power` | `OK` \| `FAIL` | |
| `current1` | 4-state string | LHS arrows (ACS712 on GPIO 34) |
| `current2` | 4-state string | RHS arrows (ACS712 on GPIO 35) |
| `current3` | 4-state string | **Static Zone 1** (ACS712 on GPIO 32) |
| `current4` | 4-state string | **Static Zone 2** (ACS712 on GPIO 33) — **NEW** |
| `battery_pct` | integer `0`–`100` | |

**Naming rationale:** wire-level metric names stay *sensor-indexed* (`current1`…`current4`) because `current1/2/3` are already deployed — `current4` is an addition, not a rename. `Static Zone 1 / 2` are the *display* labels used in the HMI and documentation only.

### Commands — Gateway publishes, ESP32 subscribes

| Topic | Payload | Retain | Notes |
| --- | --- | --- | --- |
| `metro/signage/register/<40001+i>/value` | integer `0`–`3` | **`retain=True`** | Node's target relay state |
| `metro/signage/scan` | `PING` | `retain=False` | Broadcast, every 60 s |

`retain=True` on commands is **required**: it is what lets an ESP32 receive its target state immediately on boot/reconnect instead of coming up blank.

### Retained-message deletion

An empty payload with the retain flag deletes a retained message. `perform_startup_cleanup()` depends on retained-message semantics heavily — understand this before touching it.

---

## 6. pymodbus 3.11.3 API Contract

```python
from pymodbus.datastore import (
    ModbusSequentialDataBlock,
    ModbusDeviceContext,      # was ModbusSlaveContext  (renamed)
    ModbusServerContext,
)
from pymodbus.server import StartTcpServer

HR_SIZE = 6000

store   = ModbusDeviceContext(hr=ModbusSequentialDataBlock(0, [0] * HR_SIZE))
context = ModbusServerContext(devices=store, single=True)   # was slaves=

# Bind wildcard, NOT a specific IP. See note below.
StartTcpServer(context, address=("0.0.0.0", 502))           # blocking; run in a thread
```

- `ModbusDeviceContext` takes keyword-only block args — `hr=` must be a keyword.
- Datastore access from a worker thread: `context[0].getValues(3, addr, count=n)` / `context[0].setValues(3, addr, values)`. Function code `3` = holding registers.

**Bind `0.0.0.0`, not `10.45.2.50`.** The listener then does not care what the interface address is, so changing the SCADA-side IP requires no daemon restart and drops no PLC session. Binding to a specific address forces a restart on every IP change.

---

## 7. paho-mqtt 2.1.0 API Contract — VERSION2

The project targets **`CallbackAPIVersion.VERSION2`**. Gateway and HMI must both use it. Do not mix conventions.

```python
import paho.mqtt.client as mqtt
from paho.mqtt.client import CallbackAPIVersion

def on_connect(client, userdata, flags, reason_code, properties):
    if reason_code == 0:
        client.subscribe("metro/signage/register/+/+")
    else:
        log.error("MQTT connect failed: %s", reason_code)

def on_disconnect(client, userdata, flags, reason_code, properties):
    log.warning("MQTT disconnected: %s", reason_code)

def on_message(client, userdata, msg):      # unchanged from v1
    ...

client = mqtt.Client(CallbackAPIVersion.VERSION2)
client.on_connect    = on_connect
client.on_disconnect = on_disconnect
client.on_message    = on_message
client.connect("127.0.0.1", 1883, 60)
client.loop_start()
```

Three traps:

1. **`mqtt.Client("SomeClientId")` no longer works.** The first positional arg is now `CallbackAPIVersion`. Passing a client-ID string there fails immediately. Use `client_id=` as a keyword if you need one.
2. **`reason_code` is a `ReasonCode` object, not an int.** `reason_code == 0` works, but `if reason_code:` is *inverted* from intuition — success is `0`, which is falsy. Compare explicitly.
3. **`on_disconnect` gained BOTH `flags` and `properties`.** A v1-style 3-arg handler throws *at disconnect time* — i.e. only when the network drops, which is exactly when you need it.

---

## 8. Known Bugs in `Pi.py` v1.0.1 — fix before deployment

### CRITICAL — the SCADA diagnostic block is never written under systemd

`Pi.py` line 148 opens `if sys.stdout.isatty():`. Line 203 — the `setValues` that populates the **entire** `45001+` diagnostic block — sits inside it:

```python
if sys.stdout.isatty():                                    # line 148
    ...
    for i in range(REGISTERS_TO_BRIDGE):
        ...
        modbus_context[0].setValues(3, diag_base, [...])   # line 203  <-- SIDE EFFECT
```

Run by hand in a terminal: works perfectly. Run headless under systemd: `isatty()` is `False`, the branch is skipped, and **the PLC reads zeros from every diagnostic register, forever.** No error, no log line. The 4-state discrepancy translation — the system's entire reason for existing — silently does nothing in production.

**Fix:** hoist the Modbus translation and `setValues` out of the rendering branch. Compute and write unconditionally; only the `frame +=` string-building belongs under `isatty()`.

> **Standing rule for this codebase: no side effect may live inside a presentation conditional.**

### Also fix

| Bug | Location | Impact |
| --- | --- | --- |
| `mqtt.Client("ModbusBridgeClient")` | `__main__` | Fails on paho 2.x. First positional is now `CallbackAPIVersion`. |
| `on_connect(client, userdata, flags, rc)` | callback | Needs 5 params in VERSION2. |
| No `on_disconnect` handler | — | Broker drops are invisible. |
| `ModbusSlaveContext` / `slaves=` | `__main__` | Renamed in 3.11.3 → `ModbusDeviceContext` / `devices=`. |
| `except Exception: break` | bridge loop, ~line 243 | **One transient error kills the bridge permanently.** Log and continue instead. |
| `except Exception: pass` | `on_message` | Silently swallows real bugs alongside malformed packets. Log at minimum. |
| `int("---") → ValueError → 0` | battery translation | An **offline** node reports **0 % battery** to SCADA — indistinguishable from a genuinely flat battery. Use a sentinel (e.g. `65535`). |
| `MQTT_BROKER_HOST = "0.0.0.0"` used as the **Modbus** bind address | config | Misnomer. Functionally correct, but rename it (`MODBUS_BIND_HOST`) before it misleads someone. |
| Diagnostic block hardcoded to 6 regs/node (`i * 6`) | ~line 202 | **Now 7.** Must become `5000 + (i * 7)` with the `current4` value appended. |

---

## 9. Network Configuration (committed)

Single `eth0` NIC carrying two addresses — the "air gap" is **logical**, not physical.

| Link | Initiator | Target | Port |
| --- | --- | --- | --- |
| SCADA → Gateway | PLC (Modbus **master**) | `10.45.2.50` | 502 |
| ESP32 → Gateway | ESP32 (MQTT client) | `192.168.1.10` | 1883 |
| HMI → Gateway | HMI (both clients) | `127.0.0.1` | 502 + 1883 |

NetworkManager profile `metro-gw`:

```
ipv4.method:        manual
ipv4.addresses:     10.45.2.50/24, 192.168.1.10/24
ipv4.gateway:       -- (none)
ipv4.never-default: yes
ipv6.method:        disabled
```

`ipv4.never-default yes` is load-bearing: without it, `eth0` fights `wlan0` for the default route and internet access dies the moment the field switch is plugged in.

**The air gap is enforced by `net.ipv4.ip_forward = 0`** (Debian default). If it is ever `1`, a packet arriving on `10.45.2.50` can be relayed to `192.168.1.10` and the isolation is fiction. Assert this in the deployment checklist.

Both PLC and ESP32s must be **inside their respective /24s** — there is no gateway on either side, so anything off-subnet is unreachable.

---

## 10. Mosquitto Configuration

Config lives in `/etc/mosquitto/conf.d/metro.conf` (a drop-in — never edit `mosquitto.conf`, apt upgrades will clobber it).

```
listener 1883 127.0.0.1
listener 1883 192.168.1.10     # ESP32 segment — bind fails if eth0 has no carrier
allow_anonymous true
persistence true
persistence_location /var/lib/mosquitto/
```

**The broker is deliberately NOT bound to `0.0.0.0`.** Explicit per-address listeners mean the broker is *never* reachable from `10.45.2.50` — the SCADA side. Even if someone later bridges the two switches, the PLC network cannot reach MQTT. Defence in depth, enforced at the socket rather than by trusting the topology.

Verify with `ss -tlnp | grep 1883` — you must **not** see `0.0.0.0:1883`.

**Startup-order hazard:** the `192.168.1.10` listener cannot bind before `eth0` has carrier and an address. Mosquitto will fail to start. The service needs an ordering dependency on the network being online, or the daemon must be resilient to the broker being briefly absent.

`allow_anonymous true` is acceptable on an air-gapped segment but is a **decision, not a default**. Per-node credentials are the eventual target for a public-transit deployment.

---

## 11. Deployment Notes

**Port 502 is privileged.** A pymodbus server run as user `pi` gets `PermissionError` on bind. Preferred fix — keep the daemon unprivileged and grant only the one capability:

```
# in the systemd unit
AmbientCapabilities=CAP_NET_BIND_SERVICE
```

(The alternative — bind high and NAT-redirect 502 → 5020 — works but leaks a port change into the SCADA integrator's config. Avoid.)

**Restart policy:** `Restart=always`. But note this masks the `except: break` bug above — the bridge would crash-loop rather than handle errors. Fix the error handling; do not rely on the restart.

**HMI:** separate systemd unit. The decoupled architecture exists so that an HMI crash cannot take down the SCADA-facing Modbus server. Keep them as two units; never merge them.

---

## 12. Open Items / Required Knowledge-Base Updates

These are **conflicts between the shipped code and the project docs**. Left unresolved, they will cause silent field failures.

| # | Item | Doc(s) affected |
| --- | --- | --- |
| 1 | **Register `42001` (SCADA Auto Buffer) is entirely missing from `hmi-specification.md` §4.2.** This is the block the PLC actually writes to. It is documented in `Gateway_doc.md` and used in `Pi.py`, but absent from the project's source of truth. | `hmi-specification.md` |
| 2 | **Diagnostic block is now 7 registers/node (`45001–45700`), not 6.** All docs still say 6 / `45001–45600`. | `hmi-specification.md`, `architecture-overview.md`, `Gateway_doc.md` |
| 3 | **HMI ingests only `current1`/`current2`.** It is blind to Static Zone 1 and 2. Node Detail telemetry needs two more rows. | `hmi-specification.md` §3.2, §4.1 |
| 4 | **`pin-map.md` nomenclature:** Load 3 → **Static Zone 1**, Load 4 → **Static Zone 2**. | `pin-map.md` |
| 5 | **The BROADCAST PING's documented purpose is stale.** `Gateway_doc.md`, `HMI_doc.md` ("5-minute hardware fail-safes") and `hmi-specification.md` §3.3 all claim the ping resets ESP32 fail-safe/dead-man timers. The firmware decision on record is that **animation holds last command on network loss, with no fail-safe timer.** Either the timer exists or it doesn't — three documents currently assert a mechanism that may not. **Resolve with the firmware chat.** | all three |
| 6 | **Library versions are unpinned in the spec.** Must state `paho-mqtt 2.1.0`, `pymodbus 3.11.3`, `mosquitto 2.0.21`, and that the codebase targets paho `CallbackAPIVersion.VERSION2`. | `hmi-specification.md` §1 |
| 7 | **The IPs in `architecture-overview.md` are prefixed "e.g."** — they are now committed values (`10.45.2.50`, `192.168.1.10`). Drop the hedge, or the PLC integrator is working from a suggestion rather than a spec. | `architecture-overview.md` §2 |
| 8 | **Display is 7" (1024x600) in the spec, but a Waveshare 10.1" DSI LCD is being brought up.** Pagination/coordinate math is marked TBD for 10.1". | `hmi-specification.md` §1, §5 |
| 9 | **HMI-configurable SCADA IP** (discussed, not built). Would be the first HMI action reaching the **OS** rather than the gateway's register space — a genuinely new class of action, absent from the §4.3 action-mapping table. Requires a root-owned, zero-argument helper script behind a narrow sudoers rule; the HMI must never get blanket `sudo`. | `hmi-specification.md` §3.3, §4.3 |

---

## 13. Bench Testing Without Hardware

MQTT round-trip is proven on loopback. You can exercise the full gateway and HMI with **zero ESP32 hardware** by faking a node:

```bash
mosquitto_pub -h 127.0.0.1 -t 'metro/signage/register/40001/status'      -m 'ONLINE:192.168.1.101' -r
mosquitto_pub -h 127.0.0.1 -t 'metro/signage/register/40001/power'       -m 'OK'         -r
mosquitto_pub -h 127.0.0.1 -t 'metro/signage/register/40001/current1'    -m 'ON'         -r
mosquitto_pub -h 127.0.0.1 -t 'metro/signage/register/40001/current2'    -m 'FAIL_OPEN'  -r
mosquitto_pub -h 127.0.0.1 -t 'metro/signage/register/40001/current3'    -m 'ON'         -r
mosquitto_pub -h 127.0.0.1 -t 'metro/signage/register/40001/current4'    -m 'FAIL_SHORT' -r
mosquitto_pub -h 127.0.0.1 -t 'metro/signage/register/40001/battery_pct' -m '87'         -r

# watch everything
mosquitto_sub -h 127.0.0.1 -t 'metro/#' -v
```

Clear a retained message with an empty payload:

```bash
mosquitto_pub -h 127.0.0.1 -t 'metro/signage/register/40001/power' -n -r
```

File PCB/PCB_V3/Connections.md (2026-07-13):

### 1. Power Tree Connections
* **Main Input:** 14.5V DC entering via terminal block. Connect the positive terminal to the anode of a reverse-polarity protection/isolation diode.
* **Battery:** Connect the backup battery positive terminal in parallel to the cathode of the isolation diode (the 14.5V system bus).
* **Buck Converters (5x MP1584):**
    * **IN (All 5 units):** Connect to the 14.5V system bus.
    * **Buck 1 OUT (12V):** Connect to the positive terminals for the LHS and RHS LEDs.
    * **Buck 2 OUT (12V):** Connect to the positive terminals for the Static LEDs (Zone A).
    * **Buck 3 OUT (12V):** Connect to the positive terminals for the Static LEDs (Zone B).
    * **Buck 4 OUT (12V):** Float/No Connection (Expansion buffer).
    * **Buck 5 OUT (5.0V):** Connect to the VCC pins of the 4x ACS712 sensors and the IN pin of the AMS1117-3.3 linear regulator.
* **Linear Regulator (AMS1117-3.3):**
    * **OUT (3.3V Rail):** Connect to the ESP32 (3V3 pin), LAN8720 VCC, MCP23017 VCC, and the I2C Pull-up resistors.

### 2. Common Ground Net
* **GND:** Tie the ground of the 14.5V input, the battery, all 5x MP1584 converters, the AMS1117, the ESP32, the LAN8720, the MCP23017, all ACS712 sensors, and all MOSFET Sources to a single continuous Common GND net.

### 3. ESP32 & Ethernet Connections
* **Power:** 3V3 pin to 3.3V Rail. GND to Common GND.
* **Ethernet PHY (LAN8720):**
    * GPIO 17 ➔ ETH_CLK
    * GPIO 18 ➔ ETH_MDIO
    * GPIO 23 ➔ ETH_MDC
    * GPIO 0, 19, 21, 22, 25, 26, 27 ➔ Ethernet MAC Pins

### 4. Sensor Connections (ADC1)
* **Power Supply Monitor (GPIO 36 / VP):** Connect to the center point of a voltage divider stepping down the 14.5V system bus to a maximum of 3.0V.
* **Battery Monitor (GPIO 39 / VN):** Connect to the center point of a voltage divider stepping down the Battery positive terminal to a maximum of 3.0V.
* **Current Sensors (ACS712):**
    * GPIO 34 ➔ ACS712 VOUT (LHS Load)
    * GPIO 35 ➔ ACS712 VOUT (RHS Load)
    * GPIO 32 ➔ ACS712 VOUT (Static Load)

### 5. I2C Expansion Connections (MCP23017)
* **VCC:** Connect to 3.3V Rail.
* **A0, A1, A2:** Connect all three directly to Common GND.
* **RESET:** Connect directly to 3.3V Rail.
* **SDA:** Connect to ESP32 GPIO 4. Connect a 4.7kΩ pull-up resistor from this net to the 3.3V Rail.
* **SCL:** Connect to ESP32 GPIO 13. Connect a 4.7kΩ pull-up resistor from this net to the 3.3V Rail.

### 6. MOSFET Output Connections (10x Logic-Level N-Channel)
* **LHS LEDs (5x MOSFETs):**
    * **Gate:** Connect to MCP23017 pins A0 through A4. Insert a 100Ω series resistor between the MCP23017 pin and the Gate. Connect a 10kΩ pull-down resistor from the Gate to Common GND.
* **RHS LEDs (5x MOSFETs):**
    * **Gate:** Connect to MCP23017 pins B0 through B4. Insert a 100Ω series resistor between the MCP23017 pin and the Gate. Connect a 10kΩ pull-down resistor from the Gate to Common GND.
* **Sources (All 10x MOSFETs):** Connect directly to Common GND.
* **Drains (All 10x MOSFETs):** Connect to the respective Negative (-) output terminals for the LED strips.

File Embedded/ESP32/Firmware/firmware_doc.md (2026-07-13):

# ESP32 Enterprise Signage Controller (Firmware v2.0)

**Architecture:** Dual-Core FreeRTOS, MCP23017 I2C Expander, 4x ACS712  
**Role:** Hardware Edge Controller & Network Node

---

## 1. Architectural Overview

This firmware utilizes FreeRTOS to strictly decouple network operations from high-speed hardware control via a Dual-Core architecture.

* **Core 1 (Application & Networking):** Handles the main `loop()`, Ethernet events, MQTT payload parsing, and executes the high-speed, non-blocking LED animation state machine.
* **Core 0 (Hardware DSP):** Runs a dedicated `SensorTask`. It obsessively handles ADC reads, applies median filtering to ignore EMI noise, and calculates the 4-State discrepancy logic.
* **Inter-Process Communication (IPC):** The cores share data seamlessly using a FreeRTOS `QueueHandle_t` (Mailbox pattern), eliminating race conditions between the network and the sensors.

---

## 2. Hardware Pin Mapping

### Ethernet PHY (LAN8720) - Hardwired
* **GPIO 0, 18, 19, 21, 22, 23, 25, 26, 27** 
### I2C Bus (MCP23017 Expander)
* **GPIO 16:** I2C SDA
* **GPIO 17:** I2C SCL

### Analog Sensors (ADC1 Only)
* **GPIO 36:** PSU Voltage Monitor
* **GPIO 39:** Battery Voltage Monitor
* **GPIO 34:** ACS712 #1 (Left Arrows Current)
* **GPIO 35:** ACS712 #2 (Right Arrows Current)
* **GPIO 32:** ACS712 #3 (Always ON Current)

---

## 3. MQTT Topic Structure

The firmware subscribes and publishes to the following topics, uniquely identified by its `ASSIGNED_REGISTER` (e.g., `40001`):

* **RX (Receive):**
  * `metro/signage/register/[ID]/value`: Accepts integer commands for animations.
  * `metro/signage/scan`: Accepts `PING` to reset fail-safe watchdog.

* **TX (Publish):**
  * `metro/signage/register/[ID]/status`: Network status (`ONLINE:<IP>` or `OFFLINE`).
  * `metro/signage/register/[ID]/power`: PSU health (`OK` or `FAIL`).
  * `metro/signage/register/[ID]/current1`: Left Load State (4-State String).
  * `metro/signage/register/[ID]/current2`: Right Load State (4-State String).
  * `metro/signage/register/[ID]/current3`: Always ON Load State (4-State String).
  * `metro/signage/register/[ID]/battery_pct`: Battery percentage (0-100).

---

## 4. Control Logic & Animation Modes

The system controls 10 MOSFETs via the MCP23017. The commands received via MQTT are split into two distinct operational modes using a "Modbus Offset" strategy:

### Mode A: Macro Animations (Payloads `0` to `4`)
Standard commands trigger pre-programmed bitmask animation sequences that update every 300ms using a non-blocking `millis()` state machine.
* `0`: All OFF
* `1`: Left Chase (3-LED sequential movement)
* `2`: Right Chase
* `3`: Both Chase
* `4`: Solid ON (Fail-Safe State)

### Mode B: Raw Bitmask Override (Payloads `10000` to `11023`)
Advanced control mode. The firmware subtracts the `10000` offset, leaving a 10-bit integer (0-1023). It slices this integer into two 5-bit chunks and pushes them directly to Port A (Left) and Port B (Right) of the MCP23017, allowing exact control of individual LED strips.

---

## 5. Hardware DSP & 4-State Discrepancy Logic

Instead of a binary `OK/FAIL`, Core 0 compares the **Intended State** (set by Core 1's animations) against the **Actual Current** (measured by the ACS712s) to produce 4 highly accurate diagnostic strings:

1. **`ON`**: Microcontroller intended for the LED to be ON, and current is successfully flowing.
2. **`OFF`**: Microcontroller intended for the LED to be OFF, and no current is flowing.
3. **`FAIL_OPEN`**: Intended ON, but 0 Amps flowing (Broken wiring, burnt LED, or blown MOSFET).
4. **`FAIL_SHORT`**: Intended OFF, but current is still flowing (Welded MOSFET or short to main power).

### Dynamic Thresholding
To prevent false `FAIL_OPEN` alarms during Mode B (where a user might only turn on 1 LED strip instead of 3), Core 1 mathematically counts the number of active `1`s in the bitmask (`countActiveStrips()`). It dynamically scales the expected amperage threshold so Core 0 knows exactly how much current to expect for that specific frame of animation.

---

## 🚨 HIGHLIGHT: Changes from Previous Version (v1 -> v2)

If you are migrating from the old relay-based architecture, here are the major changes implemented in this version:

1. **Relays Removed, I2C Added:** Dropped physical relays on GPIO 4/13. Integrated the `Adafruit_MCP23X17` library to drive 10 independent solid-state MOSFET channels over I2C (GPIO 16/17).
2. **Non-Blocking Animations:** Added `runAnimationStateMachine()` on Core 1 to create visual "Chase" effects using bitmask arrays without using `delay()`, keeping the network fully responsive.
3. **Modbus Offset Feature:** Added the 10,000+ integer block logic to allow granular, individual control of all 10 MOSFETs alongside the standard macro animations.
4. **Added 3rd Load Tracking:** Integrated `PIN_CURR_ALWY` (GPIO 32) and `current3` MQTT topic to track the "Always ON" LED strips.
5. **4-State Discrepancy Logic:** Completely replaced the old binary `OK/FAIL` current monitoring. The system now cross-references expected software states with physical hardware reality to output `ON`, `OFF`, `FAIL_OPEN`, or `FAIL_SHORT`.
6. **Dynamic Thresholds:** Fixed a bug where turning on a single LED strip triggered a failure. Thresholds now scale dynamically (`dynamicThreshLeft`, `dynamicThreshRight`) based on the exact number of active pins.
7. **Individual Sensor Calibration:** Replaced global `SENSITIVITY` and `ZERO_VOLT` variables with dedicated baseline variables for all three ACS712 sensors to account for manufacturing tolerances.

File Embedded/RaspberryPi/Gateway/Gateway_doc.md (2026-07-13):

# Metro Signage IoT: Raspberry Pi Bridge

**Version:** 1.0.1

**Role:** Master Translation Gateway (Modbus TCP ↔ MQTT)

## 📌 Overview

This Python application is the central nervous system of the Metro Signage IoT network. It serves as an industrial protocol bridge, translating commands from a legacy SCADA/PLC system (via Modbus TCP) into lightweight IoT messages (via MQTT) for up to 100 ESP32 edge nodes.

It runs a fully local Modbus TCP server, maintains thread-safe state dictionaries, handles Hand/Off/Auto (MUX) switching, and presents a flicker-free CLI dashboard for real-time monitoring.

## 🏗️ System Architecture

The application utilizes a robust multi-threaded design to prevent network blocking and ensure zero-latency translation:

1. **Main Thread (Logic & UI):** Handles the Modbus memory translation, MUX routing, array comparisons, and renders the ANSI-escaped terminal UI.

2. **Modbus Thread (SCADA Facing):** A daemon thread running `pymodbus.server` listening on port `502`.

3. **MQTT Thread (Edge Facing):** A background thread managed by Paho-MQTT's `loop_start()` handling asynchronous inbound telemetry from the ESP32 nodes.

## ✨ Key Features

### 1. Air-Gapped Network Support

The Modbus server binds to `0.0.0.0`, allowing the Raspberry Pi to operate with dual IP addresses. The internal `eth0` interface can host the isolated ESP32 MQTT network, while an alias IP or USB-Ethernet adapter handles the external Modbus SCADA traffic.

### 2. Thread-Safe State Management

To prevent data tearing when the background MQTT thread receives data at the exact microsecond the Main thread is reading it, a `threading.Lock()` (`data_lock`) isolates all global telemetry dictionaries.

### 3. HMI / SCADA MUX Logic (Hand/Off/Auto)

The bridge supports seamless switching between Automated SCADA control and Manual HMI control without losing state tracking:

* Modbus Register `43001` acts as the MUX flag.

* If `0` (Auto): The bridge copies commands from the SCADA buffer (`42001+`) to the active execution zone (`40001+`).

* If `1` (Manual): The bridge locks out SCADA and copies commands from the HMI buffer (`41001+`) to the execution zone.

### 4. 4-State Discrepancy Translation

The ESP32 nodes send intelligent diagnostic strings instead of binary OK/FAIL states. The bridge intercepts these strings and translates them into integers for SCADA diagnostics:

* `"OFF"` ➔ `0` (Intended OFF, no current)

* `"ON"` ➔ `1` (Intended ON, current flowing)

* `"FAIL_OPEN"` ➔ `2` (Intended ON, but 0 Amps flowing — e.g., burnt LED)

* `"FAIL_SHORT"` ➔ `3` (Intended OFF, but current flowing — e.g., welded relay)

### 5. Ghost Message Purging & Retained States

On startup, the bridge executes `perform_startup_cleanup()`. It publishes `"OFFLINE"` and `"---"` to all 100 nodes with `retain=True`. This purges the Mosquitto broker's database of any stale data from previous unexpected shutdowns, ensuring the UI and SCADA always start with a clean slate.

### 6. Hardware Watchdog Pinging

The Main thread broadcasts a `"PING"` payload to the `metro/signage/scan` topic every 60 seconds. This resets the hardware fail-safe timers (Dead-Man Switch) programmed into the ESP32 microcontrollers.

## 🗺️ Modbus Memory Map

The system uses a highly structured memory map allowing the PLC to control and diagnose 100 unique nodes seamlessly.

| Memory Block | Range | Description | 
| ----- | ----- | ----- |
| **Active Execution Zone** | `40001 - 40100` | The actual commands (0-3 or 10000+ Modbus offset) sent to the ESP32s. | 
| **HMI Manual Buffer** | `41001 - 41100` | Commands queued by the local Graphical HMI. | 
| **SCADA Auto Buffer** | `42001 - 42100` | Commands queued by the central PLC. | 
| **MUX Control Flag** | `43001` | `0` = Read from SCADA Buffer, `1` = Read from HMI Buffer. | 
| **Diagnostic Block** | `45001 - 45600` | 6 continuous telemetry registers per node (See below). | 

### Diagnostic Register Layout (Per Node)

Each node occupies exactly 6 registers in the `45001+` diagnostic block. For example, Node 1 (40001) occupies `45001 - 45006`. Node 2 (40002) occupies `45007 - 45012`.

1. **Network Status:** `1` = Online, `0` = Offline

2. **Main Power:** `1` = OK, `0` = PSU Failure

3. **LHS LED Health:** `0`, `1`, `2`, or `3` (via 4-State logic)

4. **RHS LED Health:** `0`, `1`, `2`, or `3` (via 4-State logic)

5. **Battery Percentage:** `0` to `100` (%)

6. **Static LED Health:** `0`, `1`, `2`, or `3` (via 4-State logic)

## 🚀 Installation & Usage

### 1. Prerequisites

Ensure you have Python 3 installed along with a running instance of Eclipse Mosquitto on the Raspberry Pi.

```bash
sudo apt update
sudo apt install mosquitto mosquitto-clients python3-venv
```

### 2. Install Dependencies

It is highly recommended to use a virtual environment to satisfy PEP-668 requirements.

```bash
python3 -m venv bridge_env
source bridge_env/bin/activate
pip install paho-mqtt pymodbus
```

### 3. Run the Bridge

```bash
python3 rpi_v1.py
```

You will see the screen clear, the startup cleanup execute, and the double-buffered terminal dashboard appear tracking all nodes in real-time.

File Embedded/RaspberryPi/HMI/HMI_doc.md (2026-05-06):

## Metro Signage SCADA HMI - Technical & Design Specifications

Document Version: 1.0 (Baseline)
Project Phase: V1 Decoupled Architecture

| Version | Date | Author | Description |
| --- | ---- | --- | --- |
| 1.0 | May 2026 | Core Engineering | Initial V1 Baseline creation. |

### Revision History:
#### Name: Bhoumik Acharya

#### Version: 1.0

#### Last Edited Date: 05/05/2026

#### Description: This is the baseline, created the UI, interlinked pages and cimmunication with the nodes and the gateway

### 1. System Overview & Architectural Paradigm

#### 1.1 Objective

    The Metro Signage HMI is a Python/Tkinter-based graphical interface designed to run on a Raspberry Pi with a 1024x600 Waveshare capacitive touch display. It provides real-time monitoring and manual override capabilities for up to 100 ESP32-based edge nodes.

#### 1.2 The "Decoupled Viewer" Architecture (The Why)

    Initially, the HMI was conceptualized as a monolith (hosting the UI, Modbus Server, and MQTT Logic in one script). However, for V1, a strict Decoupled Architecture was adopted.

    The Reason: If the HMI UI crashes, freezes, or is restarted by an operator, the physical SCADA network must not go down.

    The Implementation: The Modbus Server and MUX bridging logic run in a separate, headless, 24/7 background service. The Tkinter HMI script acts purely as a "Dumb Terminal/Client." It connects to 127.0.0.1:502 (Modbus) and 127.0.0.1:1883 (MQTT) simply to view and push commands to the true master service.

### 2. Design System & UI/UX Constraints

#### 2.1 The "Industrial Precision" Theme

    The UI was built to be highly visible in varying, potentially low-light industrial environments.

    Backgrounds: Deep charcoal and obsidian (#131313, #1c1b1b) to reduce eye strain.

    Active States: High-luminance Cyan (#00daf3) for immediate recognition of active relays/selected elements.

    Status Colors: Standardized semantic colors: Lime Green (#6cec00) for OK, Safety Orange (#ff8a00) for degraded/overrides, Red (#ffb4ab) for critical faults.

#### 2.2 Touch Ergonomics (The Why)

    Operating on a 7-inch touchscreen, often with gloved hands, necessitates specific UI choices:

    No OS Keyboards: Standard Linux virtual keyboards break fullscreen Kiosk applications. A custom VirtualKeyboard class was built from scratch directly into Tkinter to ensure modal, safe data entry.

    Large Touch Targets: Buttons do not use internal padding (ipadx). Instead, they use explicit character width/height definitions (e.g., width=14, height=2) to guarantee a massive bounding box that will not clip text on Linux window managers.

### 3. State Management & Threading Model

    Tkinter is strictly single-threaded. If it waits for a network packet, the screen freezes. To solve this, V1 uses a three-pillar asynchronous approach.

#### 3.1 The NODE_DATA Dictionary

    A global dictionary acts as the central source of truth. It is guarded by a threading.Lock() to prevent race conditions between reading and writing.

#### 3.2 The MQTT Background Thread (The Writer)

    The paho-mqtt library runs a background loop_start(). When it receives a payload from an ESP32 (e.g., a battery update), it briefly grabs the thread lock, updates the specific node in the NODE_DATA dictionary, and releases the lock.

#### 3.3 The sync_loop Heartbeat (The Reader)

    The Tkinter main thread runs a .after(500, self.sync_loop) function. Twice a second, the UI grabs the thread lock, takes a snapshot of NODE_DATA, and updates text labels/canvas colors on the currently active screen.

    The Reason: This guarantees a buttery-smooth 60FPS user interface, as the UI never waits on a network socket; it only ever reads from local memory.

### 4. Protocol & Register Mapping

#### 4.1 MQTT Integration (ESP32 to HMI)

    The HMI subscribes to metro/signage/register/+/+.

    Incoming: Parses status, power, current1, current2, and battery_pct to update telemetry.

    Outgoing: The BROADCAST PING button publishes "PING" to metro/signage/scan to reset the 5-minute hardware fail-safes on all ESP32s.

#### 4.2 Modbus TCP Integration (HMI to SCADA/Gateway)

    The HMI acts as a Modbus Client to the local Gateway daemon.

    MUX Toggle (Register 43001 / Address 3000): Writing 1 engages HMI Manual Mode. Writing 0 reverts to SCADA Auto Mode.

    Relay Overrides (Registers 41001+ / Address 1000+): When in Manual mode, the HMI calculates a binary state (0 to 3) based on the Relay 1 and Relay 2 buttons and writes it to the specific node's offset in the 41000 memory block.

    Live Polling: The UI actively polls the Modbus registers every 500ms to visually reflect the physical state of the relays, ensuring the UI accurately represents what the PLC is doing even when the HMI is locked in SCADA mode.

### 5. Deployment Considerations (Kiosk Mode)

    For physical deployment, the V1 application is designed to be hardened:

    self.attributes('-fullscreen', True) must be enabled in production to hide the Linux taskbar.

    The Raspberry Pi OS must have screen-blanking (xset s noblank) disabled.

    The hmi_app.py script should be triggered via a systemd service upon boot to guarantee auto-recovery in the event of a station power loss.

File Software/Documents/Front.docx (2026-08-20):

NODE CALIBRATION

SMART SIGNAGE SYSTEM

Department of Software Development, I2ST.

Abstract

The management of distributed hardware nodes in modern smart signage systems demands a unified, efficient, and secure configuration platform. This project presents a comprehensive Windows Desktop Application, developed in C# using the .NET framework, designed to centrally manage and calibrate ESP32-based controller units deployed across multiple signage panels. The application integrates a local SQL Server database for persistent storage of node records, user credentials, and panel location descriptions, combined with a JSON-based settings file for application-level preferences.

The system provides a role-based authentication mechanism, ensuring that only authorized personnel can access critical functions. A dynamic user interface allows operators to define network nodes with unique parameters including IP addresses, panel serial numbers, and physical locations. Two distinct communication channels—direct USB serial and Over-the-Air HTTP—enable the deployment of configuration payloads to remote devices without the need for physical access. The application enforces data integrity through strict validation rules, preventing duplicate IP assignments and ensuring each hardware unit is calibrated only once. An integrated serial monitor and OTA management panel offer real-time feedback on device status and configuration success.

The ESP32 firmware, implemented in the Arduino framework, incorporates Ethernet connectivity, an HTTP server, MQTT telemetry, and persistent storage via the Preferences library. On receipt of a configuration, the device dynamically updates its network settings, sensor calibration constants, and operational parameters, then automatically restarts to apply changes. A factory reset capability allows remote recovery of misconfigured devices.

This solution significantly reduces the time and complexity involved in provisioning and maintaining a large network of signage controllers. It eliminates manual data entry through planned Excel import/export functionality and lays the groundwork for future integration of Modbus TCP-based diagnostic testing. The project demonstrates a robust, scalable, and practical approach to industrial device management, blending desktop application engineering with embedded systems communication.

CONTENTS

Chapter No. | Title | Page No.
Chapter 1 | Introduction.
1.1 | Background.
1.2 | Proposed System.
1.3 | Scope and Objectives.
Chapter 2 | Requirement specification.
Chapter 3 | System Design.
3.1 | System Architecture.
3.2 | Flow Diagrams.
3.3 | Database Schema.
Chapter 4 | System Implementation.
4.1 | Main Window Interface.
4.1.1 | Menu Strip (Top Navigation Bar).
4.1.2 | Left Navigation Panel.
4.2 | Authentication Module.
4.3 | Node Management Module.
4.4 | Area Management Module.
4.5 | Panel Settings Module.
4.6 | Settings Module.
4.7 | Network Configuration Module.
4.8 | I/O Activity Module.
4.9 | Upload/Download Module.
4.10 | Tests Module.

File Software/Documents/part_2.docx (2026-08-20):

Chapter 1

INTRODUCTION

  1.1 BACKGROUND

Modern metro rail networks rely heavily on digital signage systems to convey real-time passenger information, safety instructions, and operational status across platforms and concourses. These signage systems are typically driven by embedded controllers installed at numerous physical locations, often numbering in the hundreds across a single line. Each controller must be individually configured with network parameters, calibrated to its specific sensors and power supply, and continuously monitored for faults. Traditionally, this provisioning and maintenance work has been carried out manually by field engineers who connect a laptop directly to each device via USB, a process that is time-consuming, error-prone, and difficult to audit.

As metro systems expand and demand higher reliability, there is a clear need for a centralized tool that can manage these edge nodes remotely, enforce consistent configuration, and integrate seamlessly with existing industrial control infrastructure. The project described in this document addresses that need by providing a Windows Desktop Application purpose-built for the calibration and management of smart signage controllers in an operational metro environment.

  1.2 PROPOSED SYSTEM

The proposed system is a full‑featured Windows Forms application that consolidates all node management functions into a single interface. It provides role‑based authentication, ensuring that only authorised personnel can modify safety‑critical parameters. The left panel of the main window contains navigation buttons for dedicated modules: Home, Node, Area, Tests, Settings, Network, I/O Activity, Upload/Download, and Panel Settings. Each module is implemented as a self‑contained User Control that is dynamically loaded into the central content area, preserving a clean separation of concerns.

The application stores user credentials, node definitions, and panel location descriptions in a Microsoft SQL Server Local DB database. A JSON file retains technician contact details and maintenance preferences. Communication with the ESP32‑based edge nodes occurs over two channels managed by the Panel Settings module: a USB serial interface for bench provisioning and an Over‑the‑Air HTTP endpoint for remote configuration. A consistent JSON payload carries the node's route, panel location, IP address, description, panel serial number, and optional calibration constants. If calibration fields are not supplied, they are omitted from the payload, preserving the existing device calibration. A factory‑reset function, triggered by a dedicated JSON flag, clears all stored settings and returns the device to its default state.

By abstracting the hardware complexity behind a straightforward user interface, the system reduces commissioning time, eliminates transcription errors, and provides an auditable workflow suitable for twenty‑four‑hour, seven‑day‑a‑week metro operations.

  1.3 SCOPE AND OBJECTIVES

The scope of this project is to design, implement, and document a Windows Desktop Application that accomplishes the following objectives:

- Provide a secure, role-based authentication mechanism that distinguishes between administrators and standard operators.
- Enable full Create, Read, Update, and Delete operations on node records, where each node is uniquely identified by a panel serial number and assigned to a specific route and panel location.
- Allow field engineers to attach human-readable physical descriptions to each of the four hundred possible panel slots (four routes of one hundred panels each).
- Deploy configuration payloads to ESP32 controllers over USB serial or over-the-Air HTTP, with an integrated serial monitor for real-time feedback and a factory-reset capability.
- Enforce data integrity through validation rules that prevent duplicate IP addresses, duplicate panel serial numbers, and conflicting panel location assignments within a route.
- Restrict the deployment of sensor calibration values to administrative users, protecting operational safety.
- Document the hardware communication protocol in a clear, reusable appendix.
- Lay the groundwork for future expansion, including a Modbus TCP test module and an Excel-based bulk data import/export facility.

The successful completion of these objectives yields a centralised, maintainable, and scalable configuration platform that bridges the gap between field hardware and SCADA-level management, ultimately contributing to the reliable operation of passenger information systems in metro rail networks.

Chapter 2

REQUIREMENT SPECIFICATION

  2.1 SOFTWARE REQUIREMENTS
- Operating System – Windows 10 version 1809 or later (64-bit).
- Runtime – .NET 10.0 Desktop Runtime.
- Database – SQL Server Local DB 2022 (or SQL Server Express).
- Development Tools – Visual Studio 2022, NuGet package manager.
- Libraries – Microsoft.Data.SqlClient, System.IO.Ports, System.Net.Http, System.Text.Json, System.Security. Cryptography.
- Arduino Environment – Arduino IDE with ESP32 board package, Arduino Json, Preferences, and Webserver libraries for firmware development.
- Network – Ping and HTTP connectivity to the target ESP32 devices on port 80.
  2.2 FUNTIONAL REQUIREMENTS

Main Window Interface

- MenuStrip control for the top navigation bar
- Panel controls with Dock and Anchor properties for left navigation and central content areas
- Dynamic UserControl loading into the central Panel

Authentication Module

- Modal Login Form with TextBox controls (password masked)
- SHA‑256 hashing via System.Security.Cryptography
- AuthRepository class with parameterised SQL queries (Microsoft.Data.SqlClient)

Node Management Module

- ComboBox for route selection
- Button controls for Add, Edit, and Delete actions
- DataGridView for tabular node display
- Modal AddEditNodeForm with TextBox and ComboBox controls
- NodeRepository class for CRUD operations (Microsoft.Data.SqlClient)

Area Management Module

- ComboBox for route selection
- DataGridView populated via LEFT JOIN query (Microsoft.Data.SqlClient)
- Modal EditAreaForm with read‑only and editable TextBox controls
- AreaRepository class for description updates

Panel Settings Module

- Synchronised ComboBox controls for panel location and IP address selection (mutual update guard)
- TextBox controls for read‑only description and panel serial number
- CheckBox for OTA mode toggle
- SerialPort class (System.IO.Ports) for USB communication
- HttpClient class (System.Net.Http) for OTA communication
- Manual Calibrate Panel (hidden, admin‑only) with three TextBox controls
- JSON serialisation via System.Text.Json

Settings Module

- TextBox controls for technician details
- CheckBox and ComboBox for maintenance notification
- JSON file storage via System.Text.Json

Network Configuration Module

- TextBox controls for Ethernet and Wi‑Fi parameters
- CheckBox to toggle Wi‑Fi fields
- JSON file storage via System.Text.Json

Placeholder Modules (I/O Activity, Upload/Download, Tests)

- Empty UserControl design with label text for future development

Chapter 3

SYSTEM DESIGN

  3.1 System Architecture

The User Interface is a Windows Forms application with one main window. The window contains a menu bar at the top, a panel of buttons on the left, and a central area where the current module is shown. Every feature – logging in, managing nodes, describing areas, deploying settings, changing application preferences – is kept in its own separate UserControl. This keeps the main form clean and each module focused on its task. When a user clicks a button in the left panel, the corresponding UserControl is loaded into the central area, replacing the previous one

Behind the user interface, the Application Logic enforces the rules of the system. A set of repository classes (NodeRepository, AreaRepository, AuthRepository) handle all database operations and data validation. They check that IP addresses are unique, that panel serial numbers are not duplicated, and that a panel location is only used once on a given route. The authentication logic hashes passwords with SHA‑256 and compares them against stored hashes. The logic also manages the Calibration flag – a node’s status changes from “not calibrated” to “calibrated” only after a successful deployment. The Panel Settings module uses the application logic to synchronize two dropdown lists and to enable the manual calibration panel only for administrators

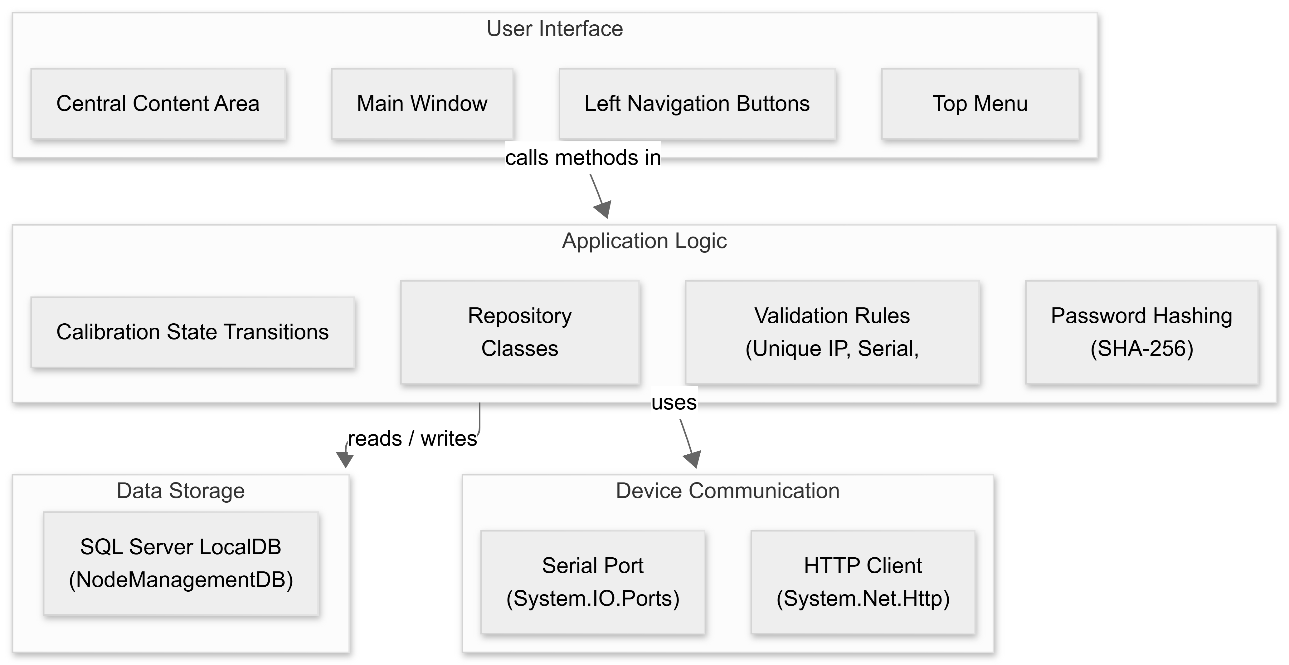
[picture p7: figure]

Figure 3.1: System Architecture

The Data Storage part uses SQL Server LocalDB for structured data and a JSON file for simple settings. All database queries use parameterised SQL to prevent injection attacks. A single DatabaseHelper class provides the connection string, making it easy to change the database location later if needed. The JSON file (settings.json) stores technician contact details and maintenance reminders, using the .NET System.Text.Json library for fast, clean serialization.

Finally, the Device Communication part handles talking to external hardware. This is kept entirely inside the Panel Settings module. Two communication methods are available: serial over USB and HTTP over the network. For serial, the .NET System.IO.Ports library opens a COM port, sends a JSON string, and listens for incoming text, which is shown in a live monitor box. For network communication, System.Net.Http.HttpClient sends the same JSON to the device’s IP address. Both methods share the same logic for building the JSON payload, and the rest of the application doesn’t need to know which method is being used.

  3.2 FLOW DIAGRAMS

Application Startup and Login Flow

When the program starts, it shows the main window with almost everything greyed out. The only things a user can click are the Login menu, the Help menu, and the About box. Choosing Login opens a small window asking for a username and password. The program checks these against the database. If they match, the main window comes alive – the buttons on the left side work, the File and Data Transfer menus appear, and the user’s name is shown at the top right. If the login fails, an error message appears and the user can try again. Later, clicking Logout will return the window to its locked state after a confirmation.

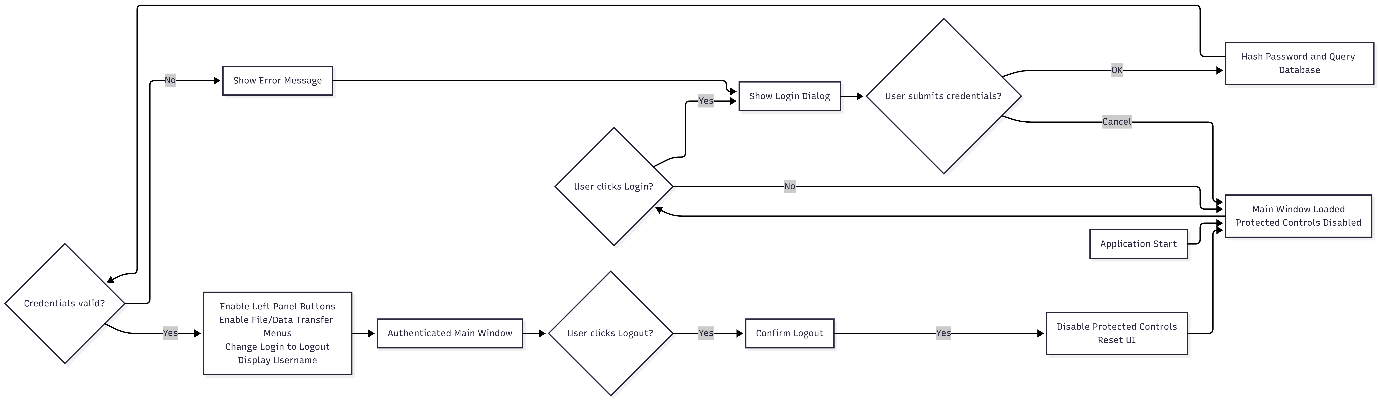
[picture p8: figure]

Figure 3.2: Application Startup and Login Flow

Node Configuration and Deployment Flow

This diagram follows the life of a node record from creation to final configuration. It starts in the Node Management module, where a user adds a new node with a unique serial number, IP address, route, panel location, and an optional description. The program checks that all the information is valid and doesn’t conflict with existing records. Once saved, the node appears in a grid with a “not calibrated” flag. The user then moves to the Panel Settings module, where only uncalibrated nodes are shown. After selecting a node, an administrator can optionally enter calibration values (like sensitivity and battery settings). The user then picks how to send the configuration – either by USB serial or over the network – and clicks Deploy. The application builds a JSON message, leaving out any calibration fields that were left empty. If the deployment succeeds, the node is marked as calibrated and disappears from the deployment list, though it still lives in the Node Management grid.

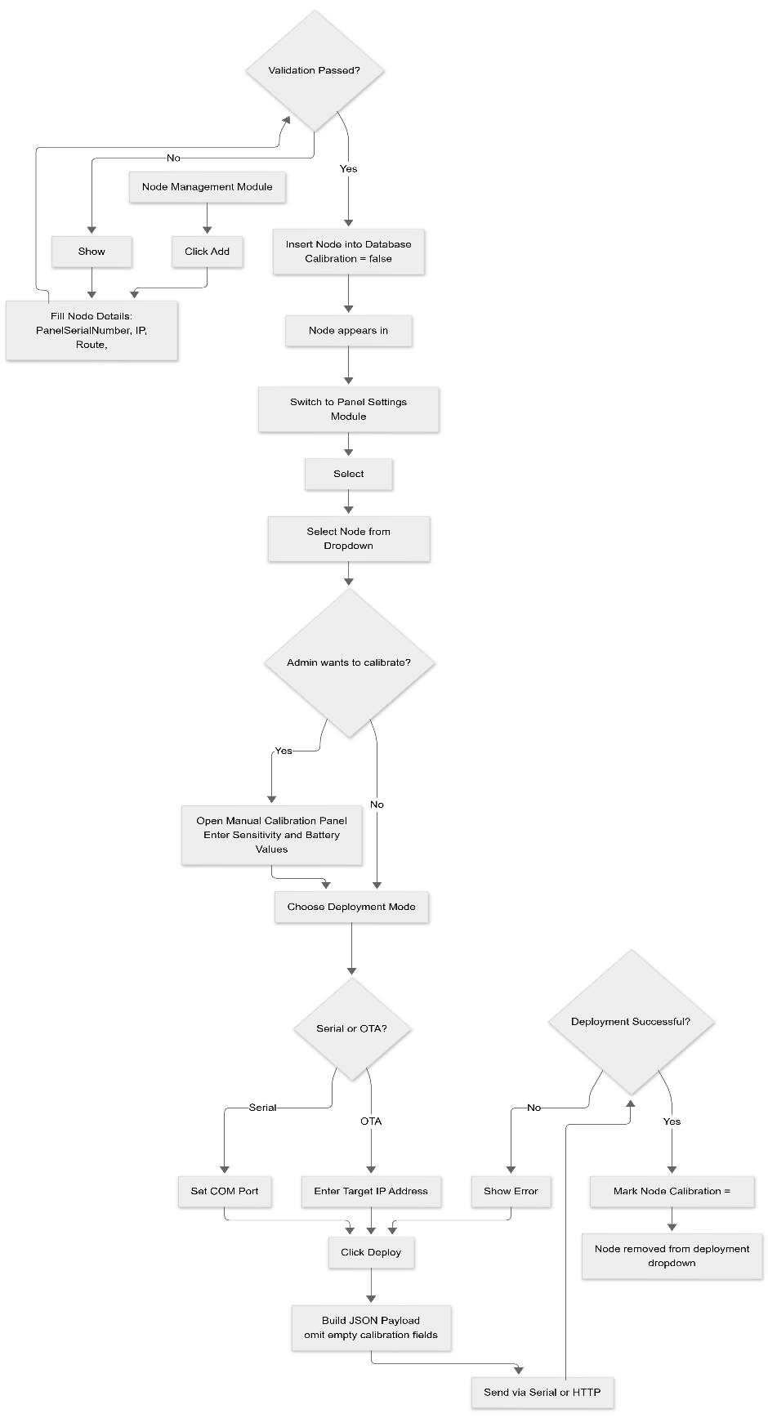
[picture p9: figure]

Figure 3.3: Node Configuration and Deployment Flow

Device Communication Sequence

This diagram zooms in on the actual data exchange during a deployment. In serial mode, the application opens a COM port, sends the JSON text, and waits for a reply, which is then shown in the built-in serial monitor. In network (OTA) mode, the application does an HTTP POST to the device’s address and waits for a success or error response. In both cases, the device receives the JSON, updates its internal values, saves them permanently, and may restart if the IP address was changed. The same pattern is used for a factory reset, except the JSON contains only a single flag telling the device to clear everything and restart.

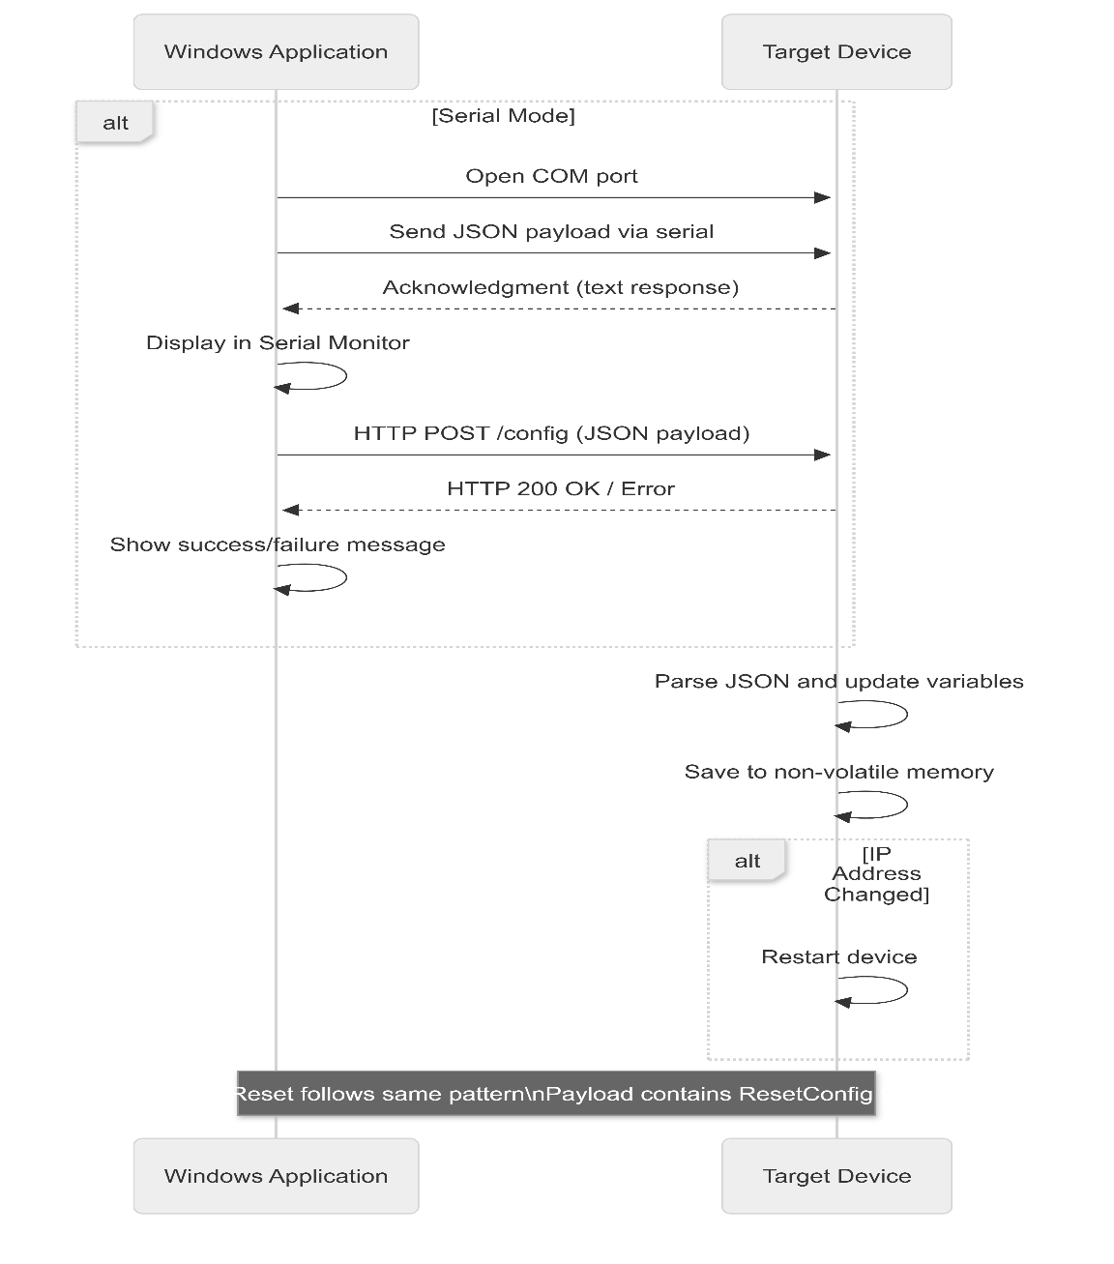
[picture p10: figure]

Figure 3.4: Device Communication Sequence

  3.3 DATABASE SCHEMA

The application stores its data in a local SQL Server database named NodeManagementDB. Inside this database there are three tables: Users, Areas, and Nodes.

The Users table contains the login information for the people who can open the application. It stores a unique username, a full name that is displayed after login, and a password that has been scrambled using a one‑way mathematical function so the original password is never saved. Two accounts are created automatically when the database is first set up: one for an administrator and one for a regular operator.

The Areas table describes every physical panel slot in the system. There are four routes, and each route has one hundred panel locations, making four hundred slots in total. The table is filled with these four hundred rows right from the start. Each row contains a route number, a panel location number, a holding register number that follows the pattern 40001, 40002 and so on, and a unique panel serial number that matches the number engraved on the hardware. A description field is also available, initially empty, where a technician can write the actual location of the panel, such as “Platform 3, Column B”. The serial number and the holding register are guaranteed to be unique across the whole table, and the combination of route and panel location is also guaranteed to be unique.

The Nodes table holds all the detailed settings for a device that has been installed at a particular panel slot. Each row in Nodes is linked to a row in Areas by the panel serial number. Besides the serial number, the table stores a user‑friendly node number, the IP address assigned to the device, and many calibration values. These calibration values include the zero‑voltage offsets for two current sensors, the sensitivity of each sensor, the current thresholds that decide whether a sensor reading is good or bad, the battery calibration factor, a compensation value for battery voltage drops, and the power supply threshold. All these calibration numbers start with sensible default values, so a node can be added without entering everything straight away.

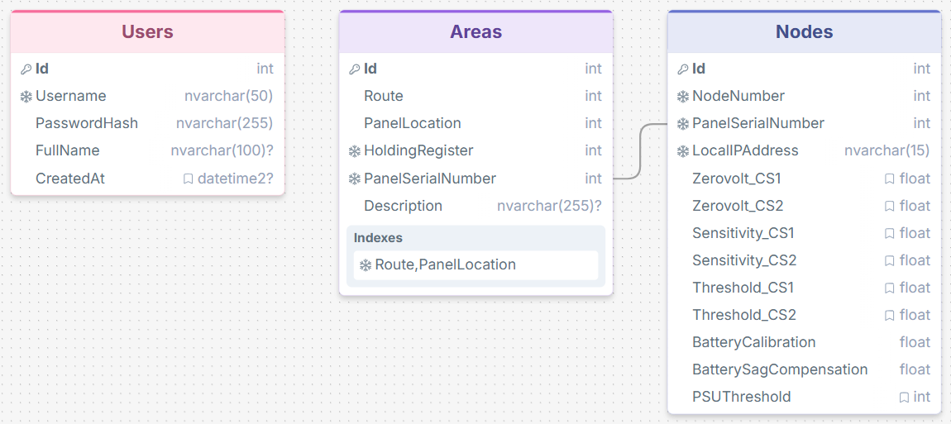
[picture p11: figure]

Figure 3.5: Database Schema

Chapter 4

SYSTEM IMPLEMENTATION

  4.1 MAIN WINDOW INTERFACE

The main application window uses a familiar three-area layout. At the top sits a menu strip, on the left a vertical stack of buttons, and the centre is a large panel where the active module appears. When the program starts, the central area shows the company logo. All navigation buttons are greyed out until the user logs in, keeping the protected features inaccessible to unauthorised persons. The window can be resized, and the layout adapts because the panels use docking and anchoring properties.

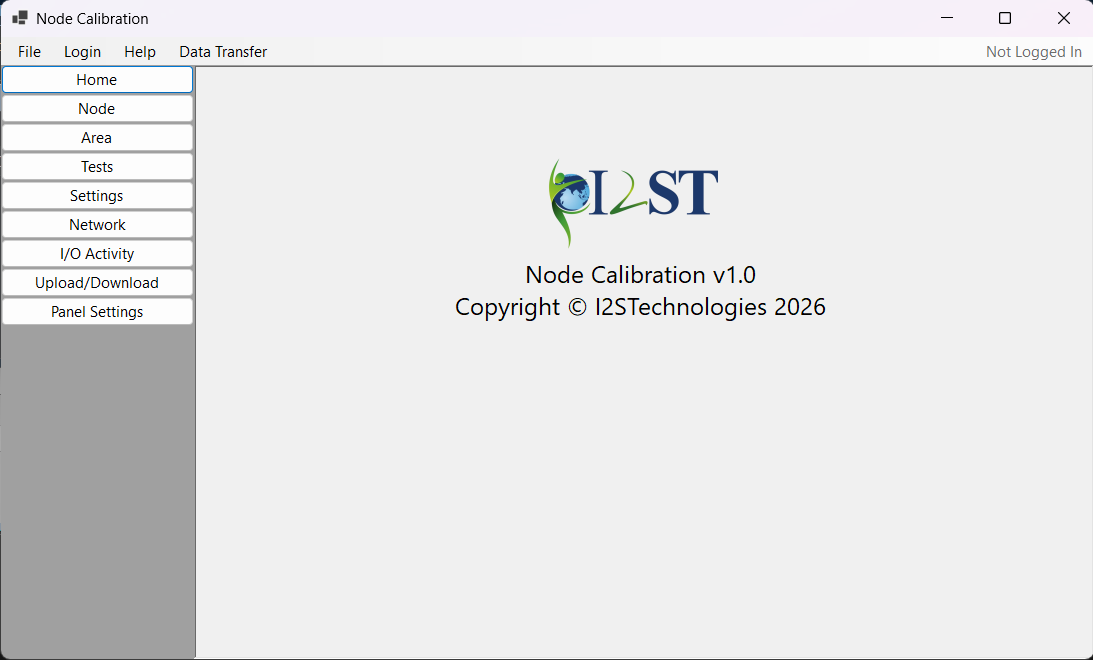
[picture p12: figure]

Figure 4.1: Main Windows Form.

    4.1.1 Menu Strip (Top Navigation Bar)

The menu strip at the top provides quick access to global commands. It contains four main menus: File, Login, Help, and Data Transfer. The File menu lets the user create a new specification file, open an existing PDF, save, or print. The Login menu changes its text depending on the login state – it reads “Login” when nobody is signed in, and “Logout” when a user is already authenticated. The Help menu offers a User Manual that opens a PDF file and an About box that shows the program’s version. The Data Transfer menu is reserved for future upload and download features. At the far right of the menu strip, a small icon and a label display the current user’s name once logged in, otherwise it shows “Not Logged In”.

    4.1.2 Left Navigation Panel

The left panel is a vertical strip of buttons, each labelled after a main function. The buttons are: Home, Node, Area, Tests, Settings, Network, I/O Activity, Upload/Download, and Panel Settings. Clicking a button changes the centre panel to the matching module. The Home button returns the central area to the company logo. All buttons are disabled until a successful login, ensuring that nobody can access the modules without permission. This panel remains visible at all times, giving constant quick access to every part of the program.

  4.2 AUTHENTICATION MODULE

The login dialog appears when the user clicks the Login menu item. It is a small, fixed-size window with two text fields (username and password), a Login button, and a Cancel button. The password is hidden as asterisks while typing. When the user presses Login, the program scrambles the password with a one-way hash and compares it against the database. If the credentials match, the dialog closes, the main window becomes fully active, the left panel buttons light up, the Login menu changes to Logout, and the user’s full name appears at the top right. If the login fails, an error message is shown and the dialog stays open. Two accounts exist by default: an administrator (“admin”) and a standard operator (“Rakesh S”). The administrator can access extra features, such as calibration controls, that remain hidden from other users.

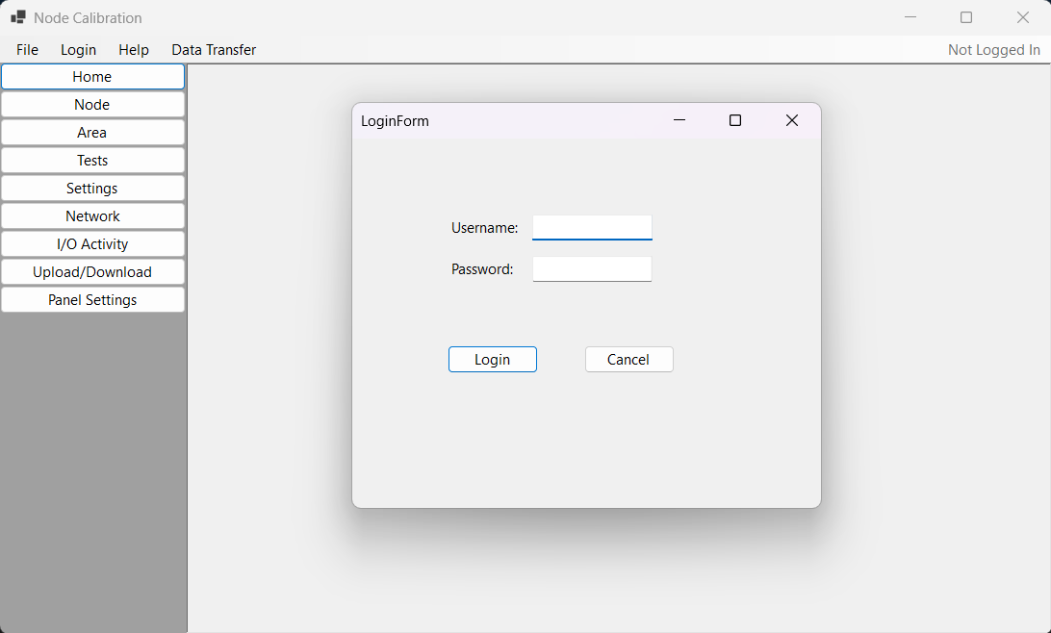
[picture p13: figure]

Figure 4.2: Login Form.

  4.3 NODE MANAGEMENT MODULE

The Node module is the place for managing device records. It contains a dropdown at the top for selecting a route (1 to 4), three buttons (Add, Edit, Delete), and a data grid that fills the rest of the area. The grid displays every node belonging to the selected route, showing the route number, IP address, panel location, description, a checkbox for calibration status, and the panel serial number. Clicking Add opens a new dialog where the user must enter a unique panel serial number, an IP address, and a panel location number, plus an optional description and calibration flag. The program checks that the IP address is valid, that it is not already used, that the panel location is free on the same route, and that the serial number is unique. If any check fails, an error message appears and the dialog remains open. Edit works the same way but pre-fills the fields with the selected node’s current data. Delete asks for a confirmation before permanently removing the selected record. All data operations use safe, parameterised database queries.

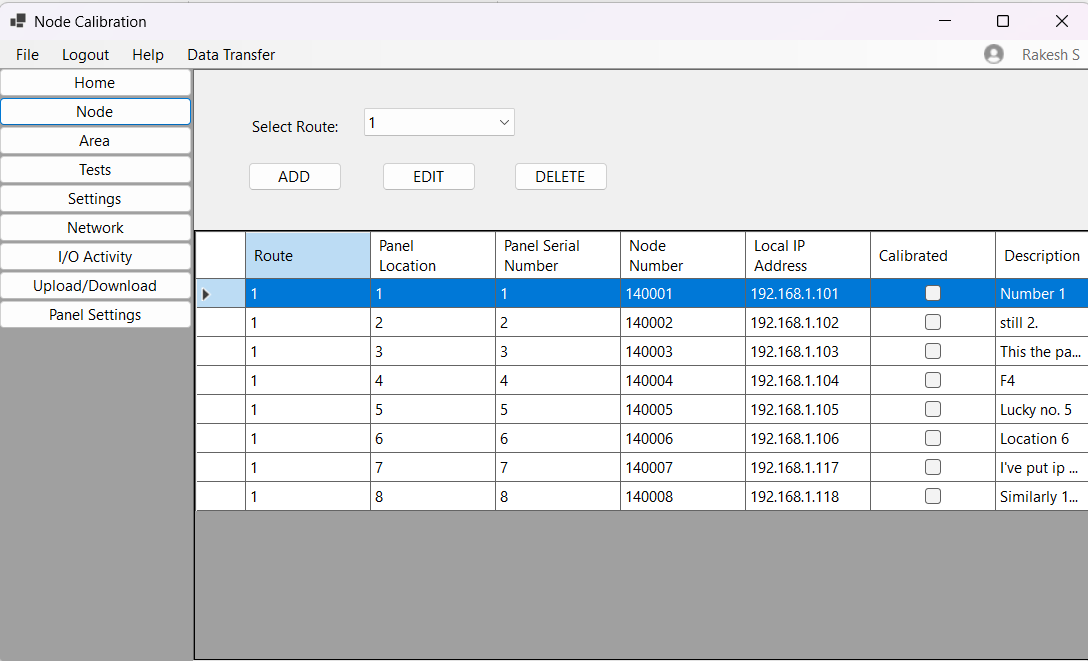
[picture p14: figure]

Figure 4.3: Node User Control.

  4.4 AREA MANAGEMENT MODULE

The Area module helps technicians label the physical location of every panel slot. It displays a route dropdown and a data grid. When a route is picked, the grid shows all one hundred panel locations for that route, each with its panel number, the IP address of any node assigned there (or “Not Assigned” if vacant), and a description field. The description is initially empty. To add or change a description, the user selects a row and clicks the Edit button. A small dialog opens showing the panel location number (which cannot be changed) and a text box for the description. Saving updates the database. The grid itself cannot be directly edited; all changes go through the Edit dialog. The data is retrieved by combining the Areas table (which holds the descriptions) with the Nodes table (which holds the IP addresses) through a left-join query.

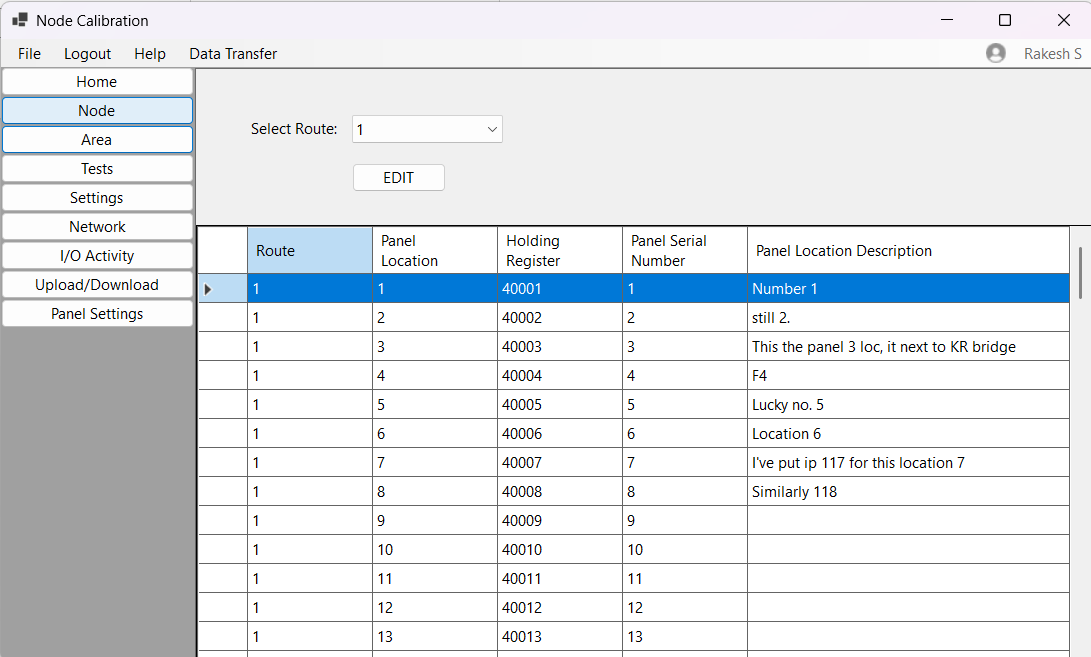
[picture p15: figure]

Figure 4.4: Area User Control.

  4.5 PANEL SETTINGS MODULE

This module is used to send configuration to a hardware device. It only shows nodes that have not yet been calibrated. The top part has a route selector, a panel location dropdown, and an IP address dropdown that stay linked together. Two read-only fields show the panel description and the panel serial number. There is a checkbox labelled “OTA Deployment” that switches between two modes: USB serial and over-the-air via HTTP. In serial mode, the user sees a COM port selector, Connect/Disconnect buttons, and a large serial monitor area that shows live text from the device. The Deploy button is disabled while the serial port is open; the user must disconnect before deploying. In OTA mode, the serial controls are replaced with a text field for the device’s IP address, and Deploy sends an HTTP request instead. A Manual Calibrate button, visible only to the administrator, opens a hidden panel with three calibration fields: ACS Sensitivity 1, ACS Sensitivity 2, and Battery Calibration. If these fields are filled, the values are included in the JSON payload; if left empty, they are omitted. After a successful deploy, the node is marked as calibrated and disappears from the dropdown. A Reset Config button sends a special JSON command that wipes all stored settings on the device and restarts it to factory defaults.

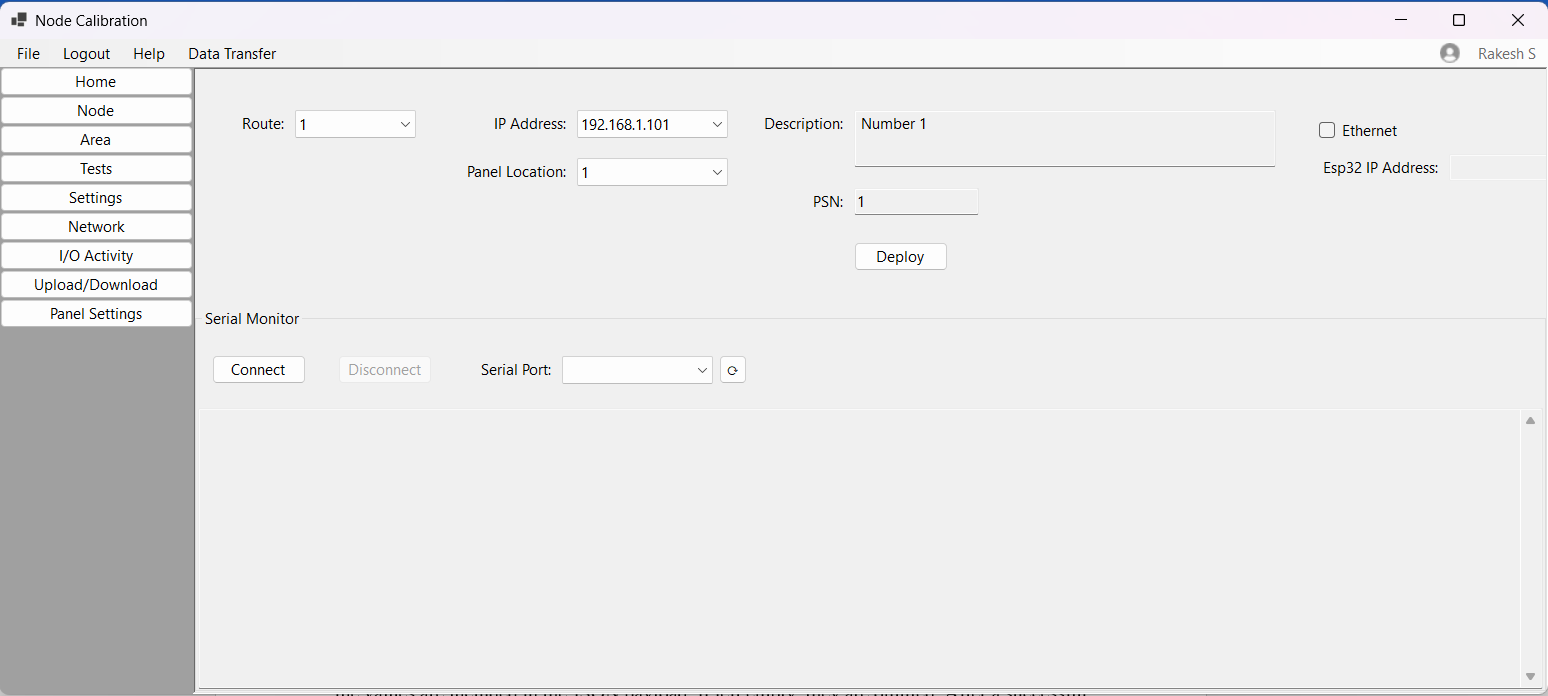
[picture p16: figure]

Figure 4.5: Panel Settings User Control.

  4.6 SETTINGS MODULE

The Settings module stores general application preferences. It shows four text boxes for the technician’s name, phone number, email, and address. Below these, a checkbox enables maintenance notifications. When the checkbox is ticked, a dropdown becomes available that lets the user pick a reminder frequency: one month, three months, six months, or twelve months. All values are saved to a JSON file on the computer, and they are loaded again each time the module is opened. This module does not use the database; it works entirely with the local file.

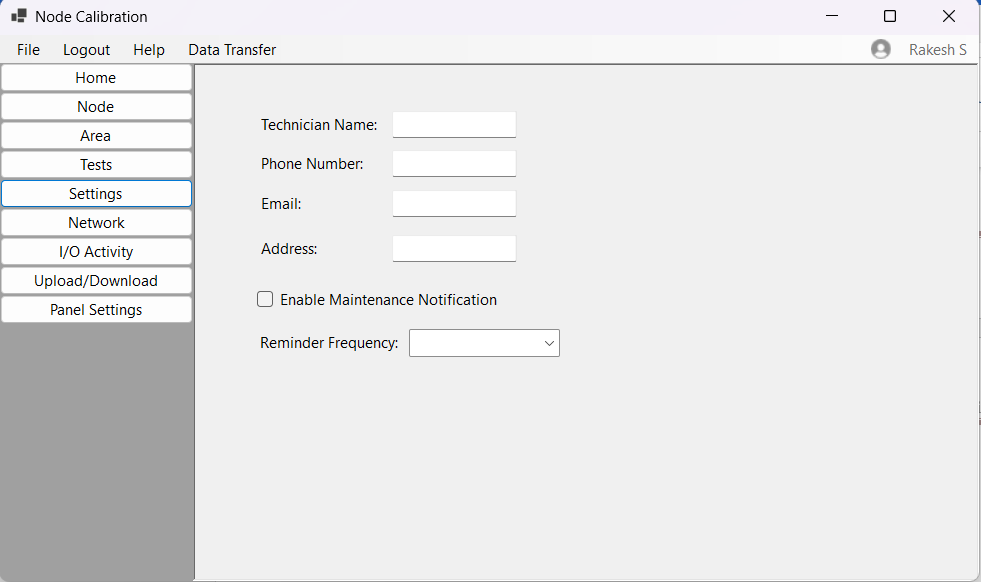
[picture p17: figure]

Figure 4.6: Settings User Control.

  4.7 NETWORK CONFIGURATION MODULE

The Network module displays and allows editing of the host computer’s network settings. It shows Ethernet parameters (IP address, subnet mask, and default gateway) as three labelled text boxes. A checkbox labelled “Wi-Fi Enabled” opens an extra panel with fields for the Wi-Fi SSID, password (masked), IP address, subnet mask, and default gateway. All these values are saved to the same JSON file used by the Settings module. The information is for reference and documentation; it does not automatically change the computer’s real network configuration.

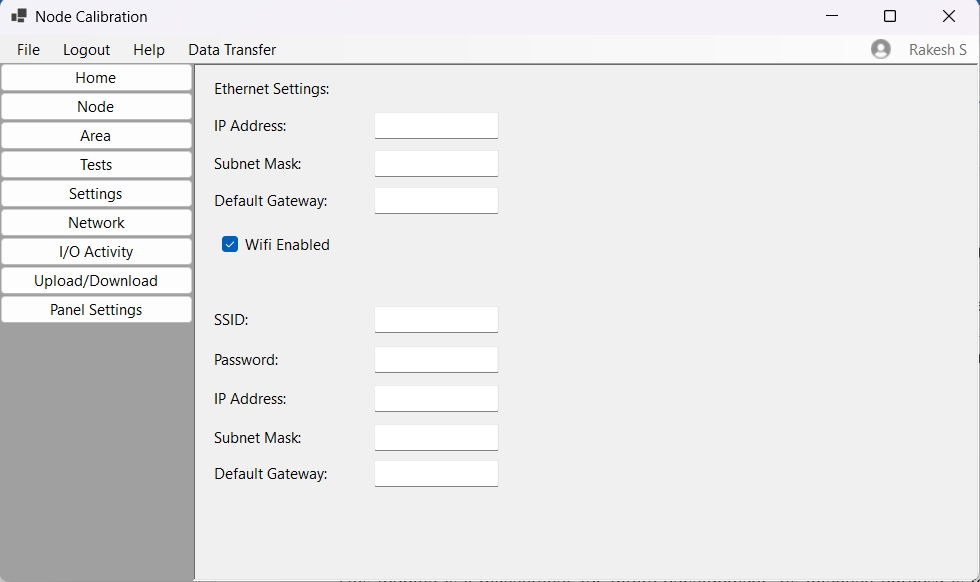
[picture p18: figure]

Figure 4.7: Network Settings User Control.

  4.8 I/O ACTIVITY MODULE

This module is a placeholder for future development. Its intended purpose is to display live input/output data, such as sensor readings and relay states, from connected devices. In the current version of the application, it loads a blank page with its name displayed, ready for later implementation when the monitoring feature is added.

  4.9 UPLOAD/DOWNLOAD MODULE

The Upload/Download module is also a placeholder. It will eventually allow users to import node and area data from an Excel spreadsheet, which is useful when setting up a large number of devices at once. It will also provide an export function to download the current database contents into an Excel template for offline editing. For now, the module shows only a label indicating that the feature is under development.

  4.10 TESTS MODULE

The Tests module is planned for performing diagnostic checks on devices using the Modbus TCP protocol. It will let an operator select one or more nodes and run test sequences, such as toggling relays or reading sensor values, and see the results in real time. Like the I/O Activity and Upload/Download modules, it currently appears as a placeholder with its name, waiting for future coding.

I2ST, Dept. of Software Development Page 3

Node Calibration Smart Signage System

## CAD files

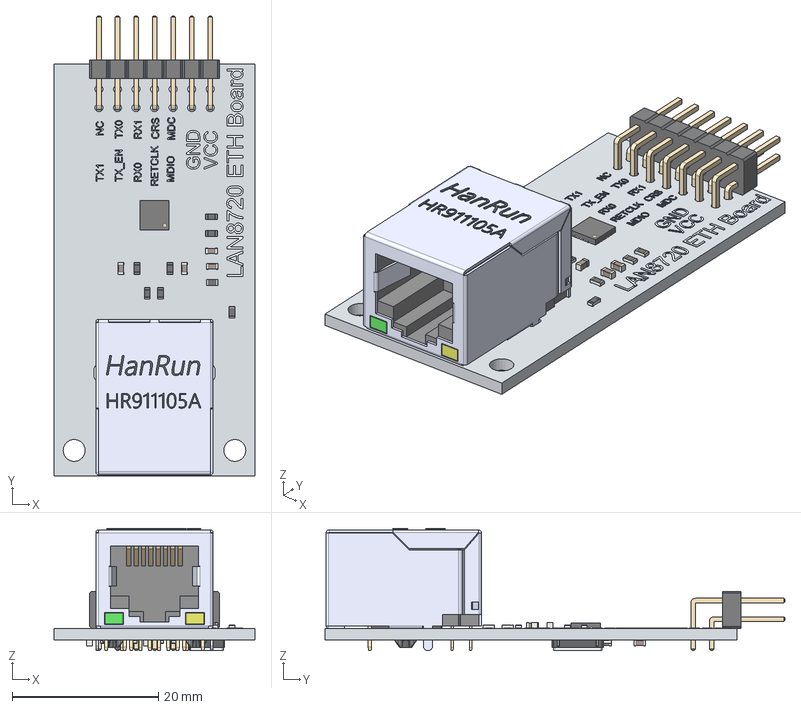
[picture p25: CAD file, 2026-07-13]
PCB/PCB_V1_Plug_and_Play_Board/GPB2/3D_Models/LAN8720_Eth_Board.step
27.5 x 63.0 x 16.8 mm
PCB
HR911105A_yellow_led
HR911105A_pin_001
HR911105A_pin_002
HR911105A_pin_003
HR911105A_pin_004
HR911105A_pin_005
HR911105A_pin_006
HR911105A_pin_007
HR911105A_pin_008
HR911105A_pin_009
HR911105A_pin_010
HR911105A_contact_004
HR911105A_contact_003
HR911105A_contact_002
HR911105A_contact_001
HR911105A_red_led
HR911105A_pin_011
HR911105A_pin_012
HR911105A_contact_005
HR911105A_contact_006
HR911105A_contact_007
HR911105A_contact_008
HR911105A_outer_shield
HR911105A_inner_023
Text_HR911105A
Text_HR911105A001
Text_HR911105A002
Text_HR911105A003
Text_HR911105A004
Text_HR911105A005
Text_HR911105A006
Text_HR911105A007
Text_HR911105A008
Text_HanRun
Text_HanRun001
Text_HanRun002
Text_HanRun003
Text_HanRun004
Text_HanRun005
PinHeader_2x07_P254mm_Horizontal
QFN-24_4x4mm_Pitch0.5mm
R_0603_1608Metric007
Text_LAN8720
R_0603_1608Metric
R_0603_1608Metric001
R_0603_1608Metric002
R_0603_1608Metric003
C_0603_1608Metric
C_0603_1608Metric001
R_0603_1608Metric004
C_0603_1608Metric002
C_0603_1608Metric003
R_0603_1608Metric005
R_0603_1608Metric006
R_0603_1608Metric008
C_0603_1608Metric004
R_0603_1608Metric009
R_0603_1608Metric010
R_0603_1608Metric011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

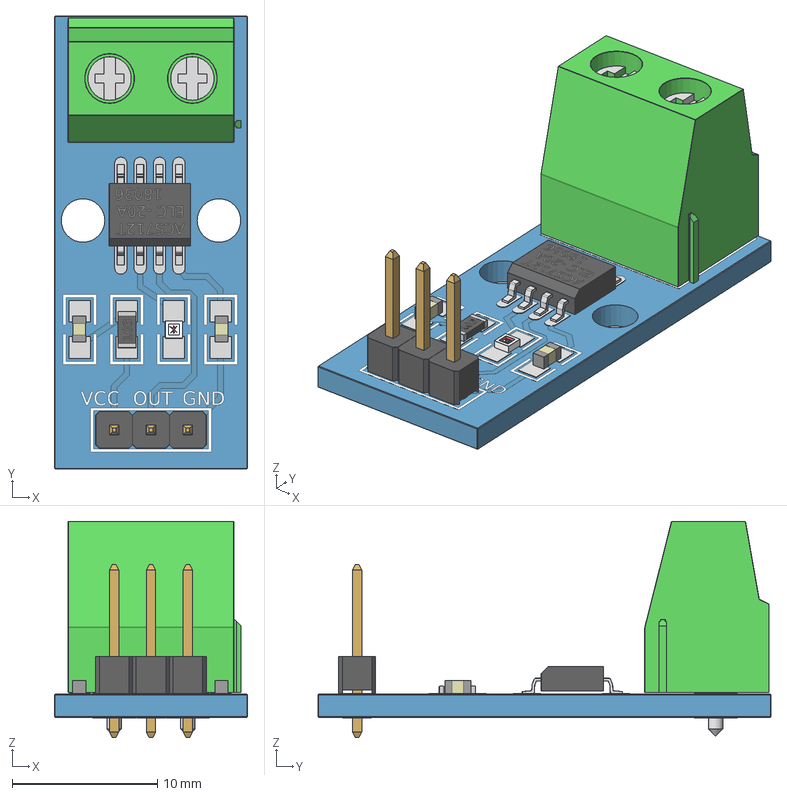
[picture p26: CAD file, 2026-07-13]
PCB/PCB_V3/3D Models/acs712-arduino-shield-1.snapshot.3/acs712.STEP
13.3 x 31.2 x 14.9 mm
ACS712_platine_001
IC_ACS712_001
SMD_LED_rot_001
SMD_R_001
SMD_DIODE_0.9mm_002
Pins_3fach_001
SMD_DIODE_0.9mm_001
Velleman_145848_001

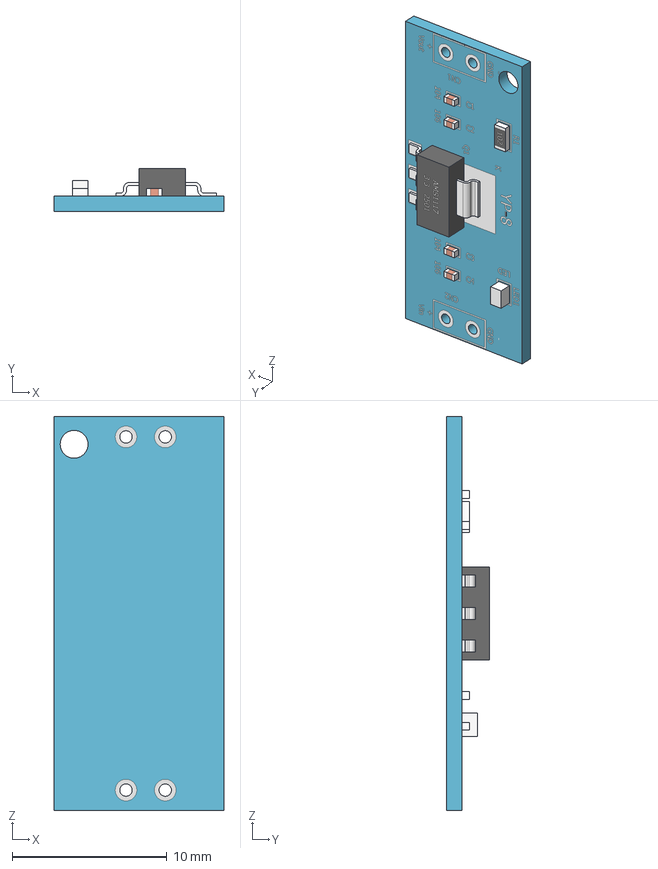
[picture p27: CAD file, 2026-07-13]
PCB/PCB_V3/3D Models/ams1117-3-3v-2.snapshot.1/AMS1117.stp
11.0 x 2.80 x 25.5 mm

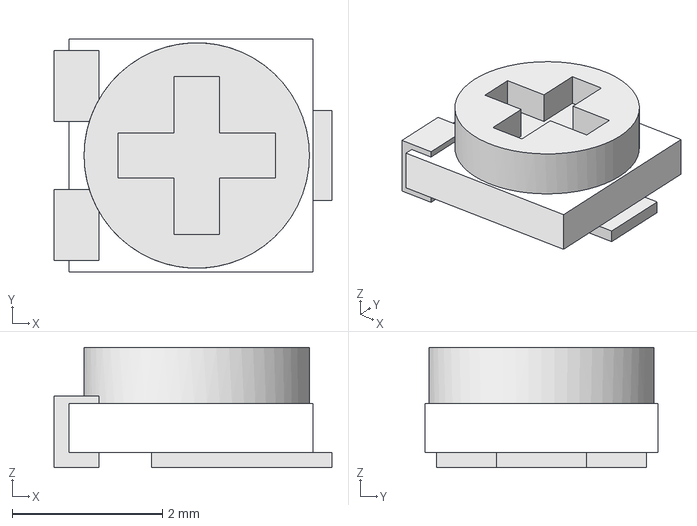
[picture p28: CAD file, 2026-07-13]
PCB/PCB_V3/3D Models/d-sun-dc-dc-step-down-voltage-regulator-simple-version-1.snapshot.4/components/EVM-3E_simple.step
3.70 x 3.10 x 1.60 mm

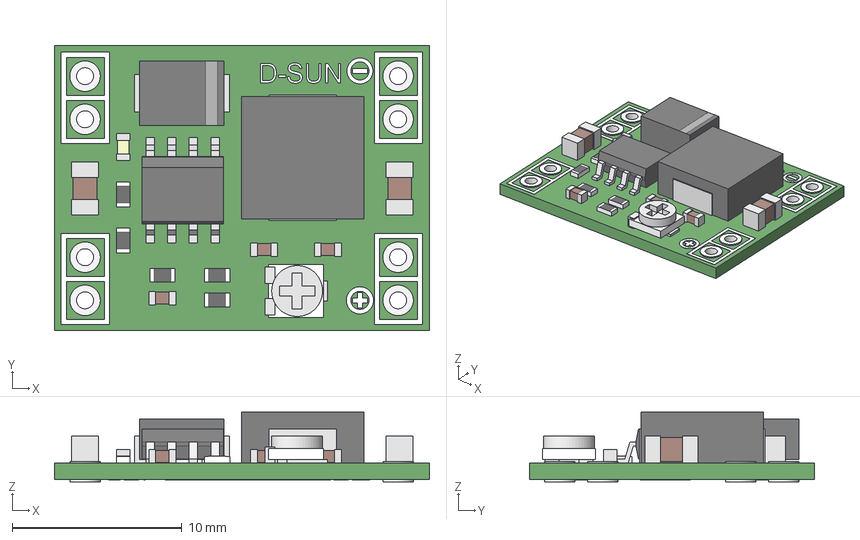
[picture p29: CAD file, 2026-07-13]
PCB/PCB_V3/3D Models/d-sun-dc-dc-step-down-voltage-regulator-simple-version-1.snapshot.4/D-SUN_dcdc_step_down_SIMPLE.step
22.1 x 16.8 x 4.10 mm
main001
silk-TOP
pins
silk-bot
comp-top

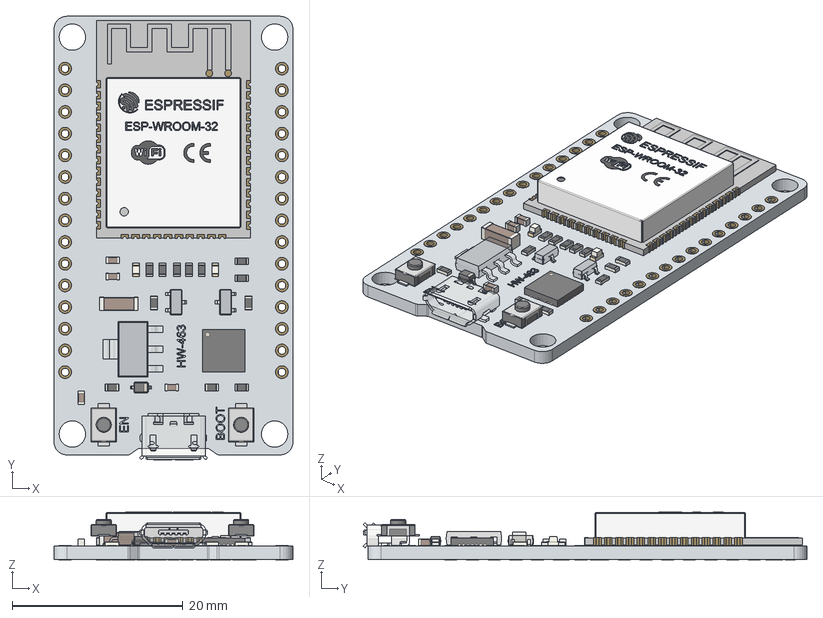
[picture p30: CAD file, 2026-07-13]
PCB/PCB_V3/3D Models/esp32-wroom-cp2102-30pins-1.snapshot.3/esp32_Wroom_CP2102_USMmicro.step
28.0 x 52.0 x 5.60 mm
PCB
PCB_mince
Text_ESP32
Text_ESP033
Text_ESP034
Text_ESP035
Text_ESP036
Text_ESP037
Text_ESP038
Text_ESP039
Text_ESP040
Text_ESP041
Text_ESP042
Text_ESP043
Text_Espressif
Text_Espressif001
Text_Espressif002
Text_Espressif003
Text_Espressif004
Text_Espressif005
Text_Espressif006
Text_Espressif007
Text_Espressif008
pin_001
pin_002
pin_003
pin_004
pin_005
pin_006
pin_007
pin_008
pin_009
pin_010
pin_011
pin_012
pin_013
pin_014
pin_015
pin_016
pin_017
pin_018
pin_019
pin_020
pin_021
pin_022
pin_023
pin_024
pin_025
pin_026
pin_027
pin_028
pin_029
pin_030
pin_031
pin_032
pin_033
pin_034
pin_035
pin_036
pin_037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

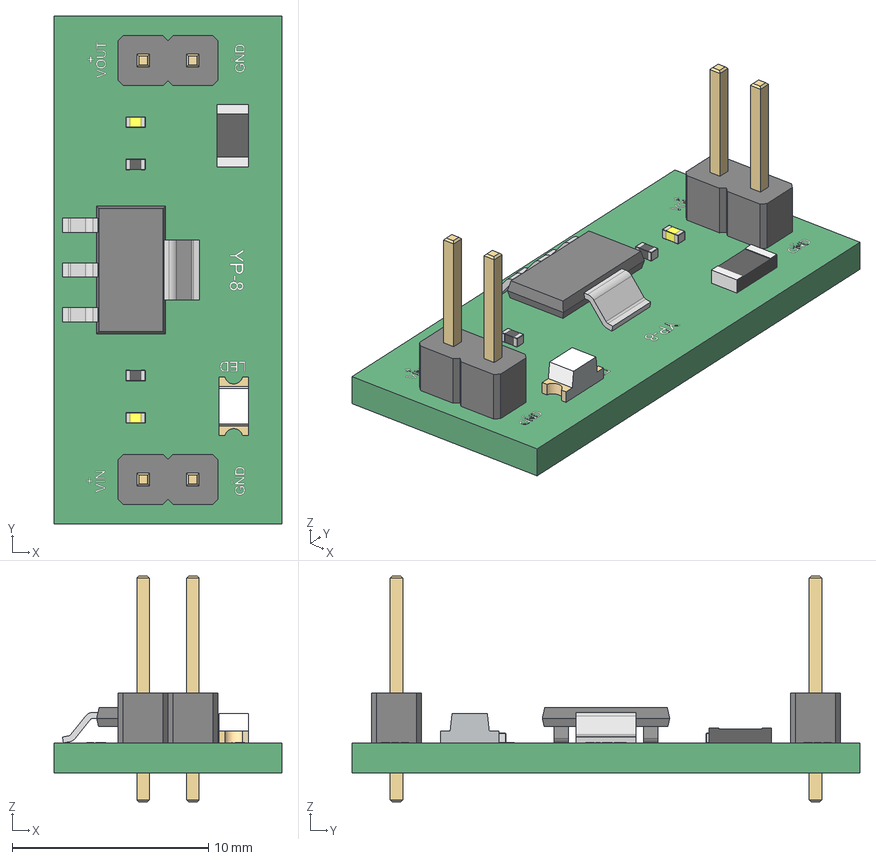
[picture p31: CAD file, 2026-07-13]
PCB/PCB_V1_Plug_and_Play_Board/GPB2/3D_Models/YP-8_L9110S_Module.stp
11.6 x 25.9 x 11.5 mm
YP-8_PCB
1X2_Pin_Holder x 2
Straight_Pin_M x 4
LED_Package_3216
Resistor_Package_3216
Package_1005_Capacitor
Package_1005_Resistor
Package_1005_Resistor_mir
Package_1005_Capacitor_mir
SOT-223 CAD

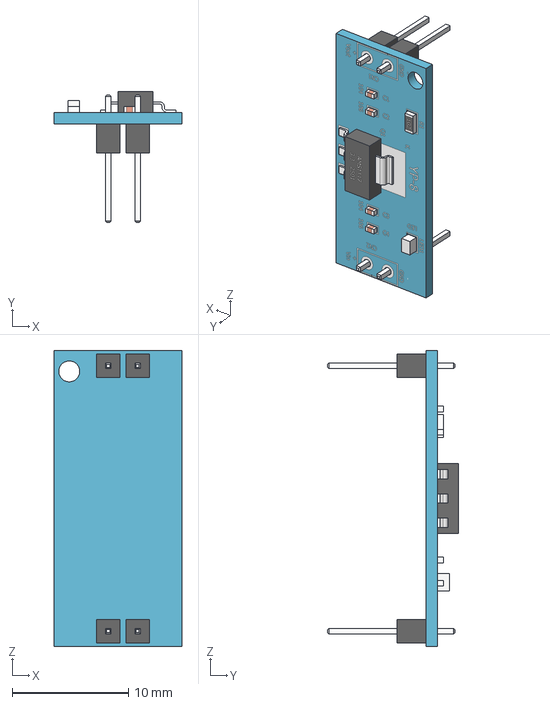
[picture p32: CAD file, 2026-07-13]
PCB/PCB_V3/3D Models/ams1117-3-3v-2.snapshot.1/AMS1117_pin.stp
11.0 x 11.3 x 25.5 mm

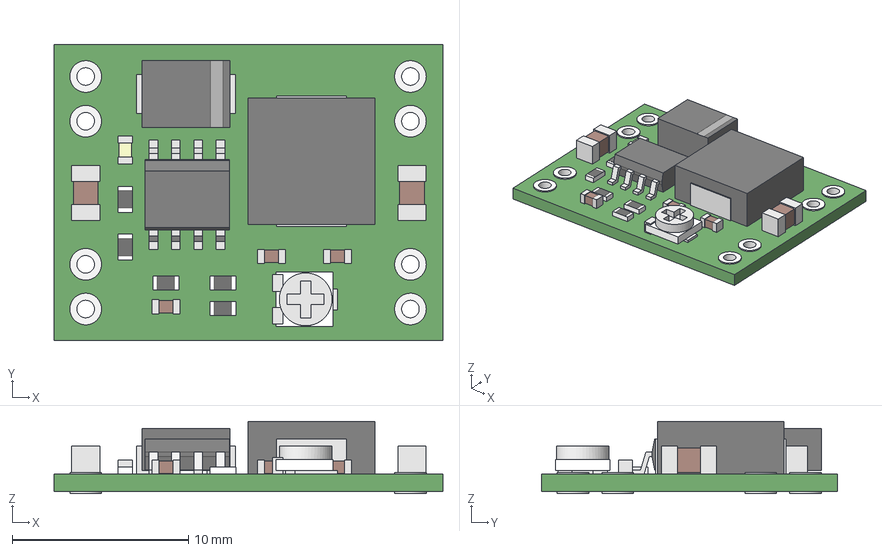
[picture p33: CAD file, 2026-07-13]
PCB/PCB_V3/3D Models/d-sun-dc-dc-step-down-voltage-regulator-simple-version-1.snapshot.4/D-SUN_dcdc_step_down_Simple_NoSilk_.step
22.1 x 16.8 x 4.10 mm
main001
pins
comp-top

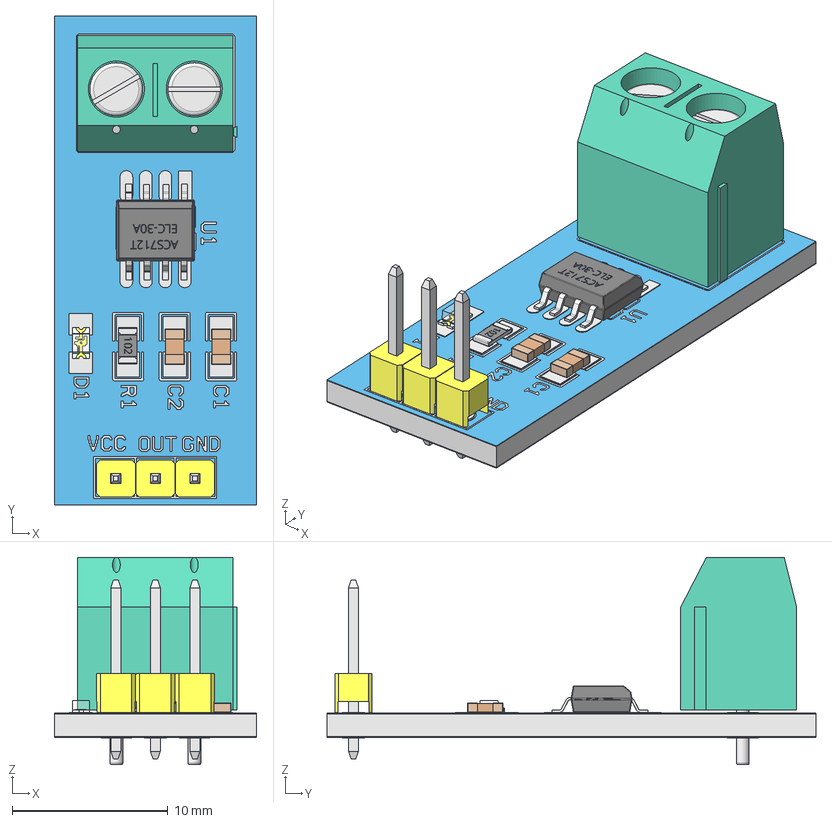
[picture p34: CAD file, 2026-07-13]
PCB/PCB_V1_Plug_and_Play_Board/GPB2/3D_Models/ACS712_module.step
13.0 x 31.4 x 13.3 mm
Case
Pin001
Pin002
Pin003
Pin004
Pin005
Pin006
Pin007
Pin008
ASC712T
ELC-30A
Frame
Screw001
Screw002
Plate001
Plate002
Contact001
Contact002
Frame001
Pin01
Pin009
Pin010
contact003
contact007
contact006
label001
contact010
contact008
contact009
Glass
Cathode
Anode
AlGa
Wire
Line
Board_padstack
Mask_upper
Mask_bottom
border002
cap_silk_up
cap_silk_up007
OUT
VCC
GND
C1
C2
R1
D1
U1
cap_silk_up008
cap_silk_up009
cap_silk_up010
cap_silk_up011
clamp_silk006
u1_silk
ACS713
LC Electronics

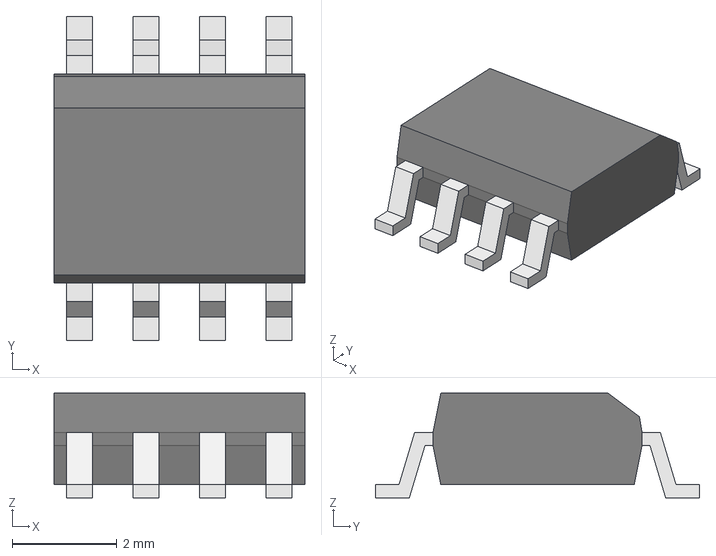
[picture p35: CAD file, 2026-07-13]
PCB/PCB_V3/3D Models/d-sun-dc-dc-step-down-voltage-regulator-simple-version-1.snapshot.4/components/SO-8_narrow_simple.step
4.80 x 6.20 x 2.00 mm

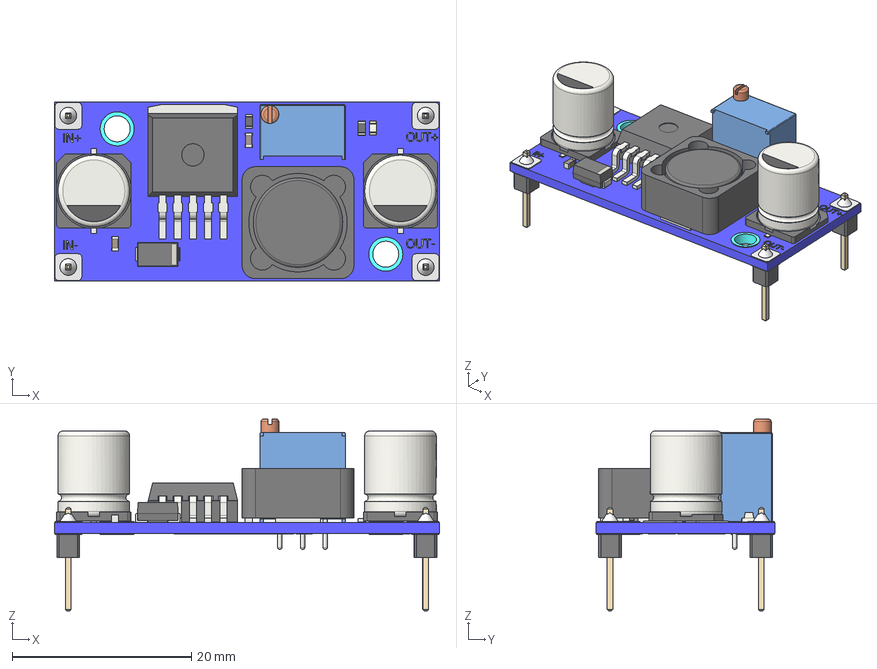
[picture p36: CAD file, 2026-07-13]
PCB/PCB_V1_Plug_and_Play_Board/GPB2/3D_Models/LM2596.step
43.0 x 20.0 x 21.4 mm
C_Elec_8x102
C_Elec_8x103
C_Elec_8x106
C_Elec_8x107
C_0603_1608Metric
C_0603_1608Metric001
D_SMA
a648ce37-9c39-11ed-93f0-dde97e994e83_part
a648ce38-9c39-11ed-93f0-dde97e994e83_part
a648ce39-9c39-11ed-93f0-dde97e994e83_part
a648ce39-9c39-11ed-93f0-dde97e994e83_part001
a648ce39-9c39-11ed-93f0-dde97e994e83_part002
a648ce39-9c39-11ed-93f0-dde97e994e83_part003
a648ce39-9c39-11ed-93f0-dde97e994e83_part004
R_0603_1608Metric
SRR1260
Bourns_3299W
R_0603_1608Metric001
LED_0603_1608Metric
PinHeader_1x01_P254mm_Vertical
PinHeader_1x01_P254mm_Vertical001
PinHeader_1x01_P254mm_Vertical002
PinHeader_1x01_P254mm_Vertical003

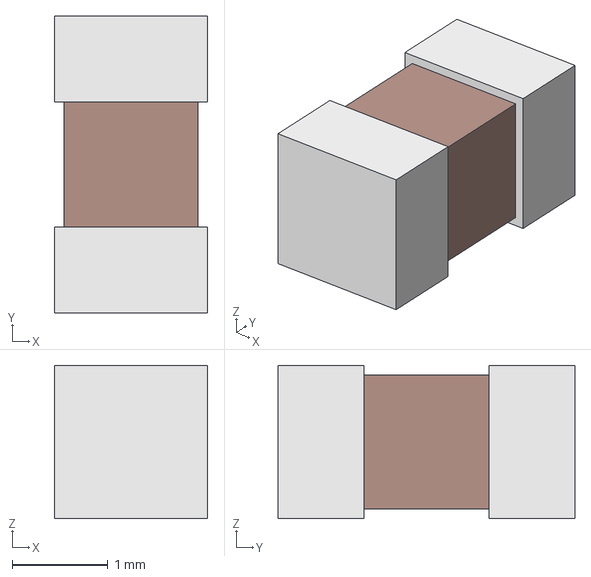
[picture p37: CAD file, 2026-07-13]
PCB/PCB_V3/3D Models/d-sun-dc-dc-step-down-voltage-regulator-simple-version-1.snapshot.4/components/C0805_H1.6_simple.step
1.60 x 3.10 x 1.60 mm

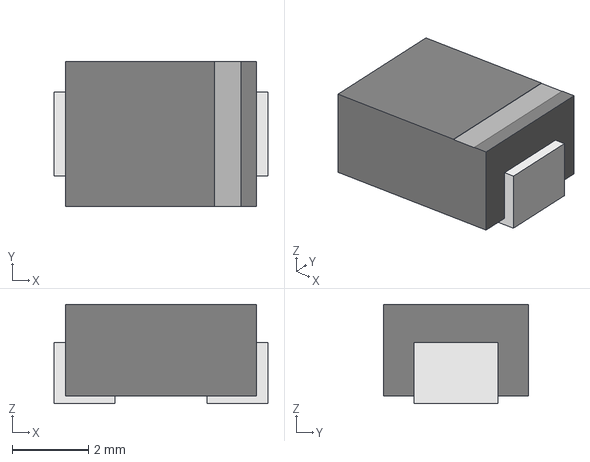
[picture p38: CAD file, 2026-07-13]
PCB/PCB_V3/3D Models/d-sun-dc-dc-step-down-voltage-regulator-simple-version-1.snapshot.4/components/DO-214AA_simple.step
5.60 x 3.80 x 2.60 mm

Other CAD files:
PCB/PCB_V3/3D Models/d-sun-dc-dc-step-down-voltage-regulator-simple-version-1.snapshot.4/components/R_EVM-3E_simple.FCStd
PCB/PCB_V3/3D Models/d-sun-dc-dc-step-down-voltage-regulator-simple-version-1.snapshot.4/components/Induct_7.2x7.2x3.0mm_simple.step
PCB/PCB_V3/3D Models/d-sun-dc-dc-step-down-voltage-regulator-simple-version-1.snapshot.4/components/C0603_simple.step
PCB/PCB_V3/3D Models/acs712-arduino-shield-1.snapshot.3/ACS712.FCStd
PCB/PCB_V3/3D Models/acs712-arduino-shield-1.snapshot.3/acs712.obj
PCB/PCB_V3/3D Models/acs712-arduino-shield-1.snapshot.3/acs712.stl
PCB/PCB_V3/3D Models/d-sun-dc-dc-step-down-voltage-regulator-simple-version-1.snapshot.4/D-SUN_dcdc_step_down_SIMPLE.FCStd
PCB/PCB_V3/3D Models/d-sun-dc-dc-step-down-voltage-regulator-simple-version-1.snapshot.4/components/C0603_simple.FCStd
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

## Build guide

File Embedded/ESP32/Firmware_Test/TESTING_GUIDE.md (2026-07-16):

# Hardware Bring-Up Testing Guide — `Firmware_Test.ino`

> **Read this first.** This guide explains *what* the testing sketch does, *why*, and gives a
> *step-by-step* procedure to validate a freshly assembled V3 board. For the full system/hardware
> reference see [`README.md`](./README.md).

---

## 1. What is this and what are we testing?

`Firmware_Test.ino` is a **standalone bench tool**. It is **not** the real product firmware — it
does **no networking at all** (no Ethernet, no MQTT, no Modbus, no Raspberry Pi). It talks to you
only over the **USB serial monitor**.

Its single job: **prove the physical hardware works before we trust it with the network stack.**
We are isolating and confirming, one subsystem at a time:

| # | Subsystem | What we confirm |
|---|---|---|
| 1 | **I2C bus + MCP23017** | The expander is found at `0x20` on the **finalized pins SDA=GPIO4 / SCL=GPIO13**. If this fails, nothing else can be driven. |
| 2 | **10x MOSFET channels** | Each Port A0–A4 (LHS) and B0–B4 (RHS) gate switches its LED strip on/off individually. Catches dead MOSFETs, swapped wiring, cold solder joints. |
| 3 | **4x ACS712 current sensors** | LHS, RHS, Static 1, Static 2 each report sane current when their load is on, ~0 A when off. Catches miswired/backwards sensors and validates calibration. |
| 4 | **PSU + Battery voltage dividers** | GPIO36 (PSU) and GPIO39 (Battery) read voltages in the expected range. Catches wrong divider ratios or open dividers. |

> **Why no network here?** If we test everything at once and something is wrong, we can't tell if
> it's the LED wiring, the sensor, or the MQTT config. This sketch removes every variable except the
> board itself. Once the hardware passes here, we move to the production firmware in `../Firmware/`.

**What this sketch does NOT test:** Ethernet/LAN8720, MQTT to the Pi, Modbus, the 4-state
discrepancy logic, the watchdog, and the hold-last-state failsafe. All of that lives in the
production firmware and is validated separately.

---

## 2. What you need

- Assembled V3 board (or breadboard equivalent) powered per `README.md` §1.
- USB connection from your PC to the ESP32 (for flashing + serial monitor).
- **Arduino IDE / arduino-cli** with the **ESP32 board core** installed.
- Library: **Adafruit MCP23017** (`Adafruit_MCP23X17`) — install via Library Manager.
- A **multimeter** (to verify divider voltages and, ideally, cross-check ACS712 current).
- The LED strips + loads connected (so currents are real).

---

## 3. Serial command reference

Open the Serial Monitor at **115200 baud**. The menu prints on boot (press `h` to reprint).

| Key | Action |
|-----|---|
| `0`–`4` | Toggle one **LHS** MOSFET (Port A0–A4) |
| `5`–`9` | Toggle one **RHS** MOSFET (Port B0–B4) |
| `a` | Turn **all** MOSFETs ON |
| `x` | Turn **all** MOSFETs OFF |
| `c` | Run the **chase** animation self-test (5 cycles), then restore previous state |
| `r` | Read **all 4 current sensors** once |
| `s` | Toggle **continuous 1 Hz current stream** on/off |
| `v` | Read **PSU + Battery** divider voltages once |
| `h` | Reprint the menu |

After each MOSFET toggle it prints the live port bitmask, e.g. `Port A[00100] Port B[00000]`.

---

## 4. Step-by-step test procedure

Do these **in order**. Do not proceed past a failing step — fix it first.

### Step 0 — Flash and connect
1. Open `Firmware_Test.ino` in the Arduino IDE, select your ESP32 board + port.
2. Upload.
3. Open Serial Monitor @ **115200 baud**.

### Step 1 — I2C / MCP23017 detection (gate to everything)
1. On boot, watch for:
   `Probing MCP23017 @0x20 on SDA=4/SCL=13 ... OK`
2. **If it says `NOT FOUND!`** the sketch halts. Check, in order:
   - SDA on **GPIO4**, SCL on **GPIO13** (not the old 16/17).
   - **4.7 kΩ pull-ups** on both SDA and SCL to the 3.3 V rail.
   - MCP23017 **RESET → 3.3 V** and **A0/A1/A2 → GND** (address `0x20`).
   - 3.3 V present on the MCP23017 VCC.
3. Only continue once you see `OK` and the menu.

### Step 2 — MOSFET channels (one at a time)
1. Press `x` to ensure all off.
2. Press `0`. The **first LHS strip (A0)** should light. Confirm the bitmask shows `Port A[00001]`.
3. Press `0` again to turn it off. Repeat for keys `1`,`2`,`3`,`4` (LHS A1–A4).
4. Repeat for keys `5`–`9` (RHS B0–B4).
5. **Record any channel that does not light** (dead MOSFET, wiring, or solder). A strip lighting on
   the *wrong* key = swapped gate wiring.
6. Press `a` (all on) then `x` (all off) to confirm bulk control.
7. Press `c` to watch the chase animation sweep across both sides smoothly.

### Step 3 — Current sensors (correlate with MOSFETs)
1. Press `x` (all off), then `r`. All four currents should read **≈ 0 A** for the switched loads.
   - **Static1 / Static2 are always-on**, so they should already show a **non-zero** current here
     (their zones are permanently powered). That's expected, not a fault.
2. Press `s` to start the 1 Hz stream.
3. Turn on the **LHS** strips (`0`–`4`). **LHS current should rise**; RHS should stay ~0.
4. Turn on the **RHS** strips (`5`–`9`). **RHS current should rise**.
5. Confirm **Static1** and **Static2** hold steady non-zero readings throughout.
6. Press `s` again to stop the stream.
7. **Sanity vs multimeter:** if a sensor reads negative-looking or wildly off values, it may be
   wired backwards or be the wrong ACS712 variant — note it for calibration (see §5).

### Step 4 — Voltage dividers
1. Press `v`. You'll see raw ADC + estimated volts for **PSU** and **Battery**.
2. Compare the estimated volts against a **multimeter** on the 14.5 V bus and the battery.
3. If the numbers are off, the `PSU_DIV_RATIO` / `BATT_DIV_RATIO` placeholders need correcting
   (see §5). The raw ADC should be **stable** and **below 4095** (never railing).

### Step 5 — Record results
Note, for the next phase:
- Any dead/miswired MOSFET channels.
- Any misbehaving current sensor.
- The **ACS712 variant** you actually fitted (5 A / 20 A / 30 A).
- The **measured divider ratios** from the multimeter.

---

## 5. Calibration notes (expected during testing)

The sketch ships with **placeholder** calibration that WILL need correcting on the bench:

- **ACS712 `SENS` / `ZERO`** (currently `0.146` / `2.400`): `SENS` is Volts-per-Amp for your
  sensor. Standard parts are ~`0.185` (5 A), `0.100` (20 A), `0.066` (30 A) — `0.146` matches none,
  so confirm the variant and update `SENS_LEFT/RGHT/STA1/STA2`. `ZERO` is the sensor's output
  voltage at 0 A (nominally VCC/2 ≈ 2.5 V) — read it with all loads off and set it.
- **Divider ratios** `PSU_DIV_RATIO` / `BATT_DIV_RATIO` (currently `5.30`): set these to
  `(measured bus voltage) / (voltage at the ADC pin)` from your multimeter.

These placeholders don't block the pass/fail checks above — they only affect the *accuracy* of the
numbers. Get the wiring proven first, then dial in calibration.

---

## 6. Pass criteria

The board passes hardware bring-up when:

- [ ] MCP23017 detected `OK` on SDA=4 / SCL=13.
- [ ] All 10 MOSFET channels switch their correct strip individually (`0`–`9`), plus `a`/`x`/`c`.
- [ ] Switched-load currents track their MOSFETs (LHS/RHS rise when on, ~0 when off).
- [ ] Static1 + Static2 show steady non-zero current.
- [ ] PSU + Battery dividers read plausible, stable, non-railing values.

Once all boxes are ticked, we proceed to the **production firmware** (`../Firmware/`) to add
Ethernet, MQTT to the Pi, the 4-state discrepancy logic, the watchdog, and the hold-last-state
failsafe.

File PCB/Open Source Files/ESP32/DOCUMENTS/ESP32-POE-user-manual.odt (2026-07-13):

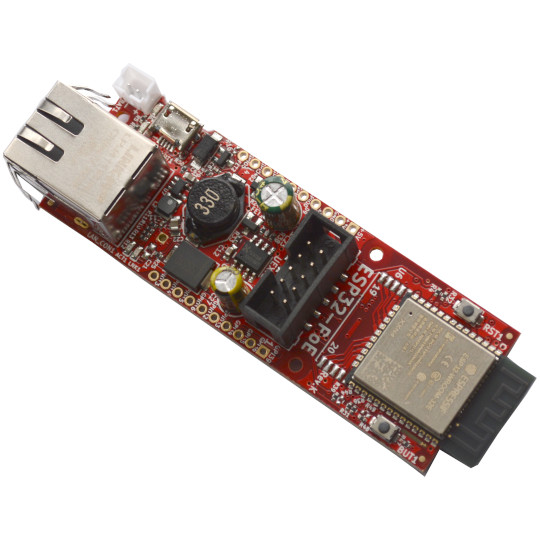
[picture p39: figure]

ES32-POE

ESP32-POE-ISO

User Manual

Document revision 2.6.

September 2025

www.olimex.com

# 1. Introduction to ESP32-POE and ESP32-POE-ISO

ESP32-PoE (https://www.olimex.com/Products/IoT/ESP32/ESP32-POE/open-source-hardware) and ESP32-PoE-ISO (https://www.olimex.com/Products/IoT/ESP32/ESP32-POE-ISO/open-source-hardware) are ESP32-powered Wi-Fi/Bluetooth/Ethernet development boards with Power-Over-Ethernet feature. The boards are the perfect addition to any project that requires extra connectivity.

The PoE is currently handled by TPS2375/6 chip (Si3402-B in older revisions) that is IEEE 802.3af-compliant, including pre-standard (legacy) PoE support.

The PoE powering requires at least 37V DC to operate successfully. The board can takes power from the Ethernet cable and can be expanded with sensors and more. Perfect solution for Internet-of-Things projects.

Both ESP32-POE and ESP32-POE-ISO are mature, popular, and well-known products, with wide software support.

+ Important notice: ESP32-PoE (https://www.olimex.com/Products/IoT/ESP32/ESP32-POE/open-source-hardware) has no galvano isolation of Ethernet's power supply, when you program the board via the micro USB connector the Ethernet cable should be disconnected (if you have power over the Ethernet enabled)! Consider using Olimex USB-ISO (https://www.olimex.com/Products/USB-Modules/USB-ISO/) to protect your computer and board from accidental short circuits. Also consider using Olimex ESP32-PoE-ISO (https://www.olimex.com/Products/IoT/ESP32/ESP32-POE-ISO/open-source-hardware) board instead since it is insulated.

## 1.1. ESP32-POE features

- ESP32-WROOM-32E module WiFi + Bluetooth ® + Bluetooth LE module from Espressif Inc (ESP32-WROOM-32UE or ESP32-WROVER-E/IE depending on variant)
- ESP32-WROOM-32E/UE have 4MB flash and 520 KB SRAM
- ESP32-WROVER-E/IE have 4MB Flash 520KB SRAM and 8MB PSRAM
- High reliable industrial grade (-40+85C) variant available (-IND)
- CE-RED and LVD certification
- Original design by OLIMEX Ltd
- Power Over Ethernet negotiation circuit, 802.3-compliant, with minimum operating voltage of 37VDC
- DC-DC converter with 3A at 5V output
- Li-Po battery charger and connector
- Battery level monitor pin on ADC
- External power supply detection pin on ADC
- UEXT connector (https://www.olimex.com/Products/Modules/UEXT/)
- User button
- Reset button
- Micro USB with programmer for ESP32 programming
- MicroSD card
- Two extension connectors 0.1" step spaced at 1"
- PCB dimensions: (80 x 28)mm ~ (3.15 x 1.1)"

## 1.2. ESP32-POE-ISO features

- ESP32-WROOM-32E (https://www.espressif.com/sites/default/files/documentation/esp32-wroom-32e_esp32-wroom-32ue_datasheet_en.pdf) WiFi + Bluetooth ® + Bluetooth LE module by Espressif Inc (ESP32-WROOM-32UE or ESP32-WROVER-E/IE depending on variant)
- ESP32-WROOM-32E and ESP32-WROOM-32UE have 4MB/16MB flash and 520 KB SRAM
- ESP32-WROVER-E/IE (https://www.espressif.com/sites/default/files/documentation/esp32-wrover-e_esp32-wrover-ie_datasheet_en.pdf) have 4MB Flash 520KB SRAM and 8MB PSRAM
- Power Over Ethernet negotiation circuit 802.3 compliant, with minimum operating voltage of 35VDC
- High reliable industrial grade -40+85C available (-IND)
- CE-RED and LVD certification
- Original design by OLIMEX Ltd
- Low power design – 200uA consumption in deep sleep
- Ethernet 100Mb interface with IEEE 802.3 PoE support
- 3000VDC galvanic insulation between the PoE Ethernet part and board's power supply circuit Micro USB connector for ESP32 programming
- MicroSD card working in 1 bit mode
- LiPo battery charger with LiPo battery connector
- Battery level monitor pin on ADC
- External power supply detection pin on ADC
- DC-DC 2W 5V/400mA
- UEXT connector (https://www.olimex.com/Products/Modules/UEXT/)
- User button
- Reset button
- Two extension connectors, 0.1" step spaced at 1"
- PCB dimensions: (98x28)mm ~ (3.8x1)"

## 1.3. PoE standard

ESP32-POE and ESP32-POE-ISO are compliant with the IEEE 802.3af PoE standard and provide up to 15.4 W of DC power (minimum 37V DC and 350 mA). Only 12.95 W are assured to be available at the powered device as some power dissipates in the cable. The PoE boards have LAN connectors suitable for both modes of PoE operation (mode A and mode B) – the LAN connector is visible in the schematic.

ESP32-POE-ISO has 2W DC-DC 5V-5V insulation converter which prevents electrical influence between different sources of power but limits the power usage to 2W only!

## 1.4. The difference between ESP32-POE and ESP32-POE-ISO

ESP32-POE is not galvanically isolated which means that it’s not safe to connect it to other devices which use non isolated power supply while it is powered. It should have only one power supply and one ground attached to it at a time.

+ This means YOU SHOULD NOT CONNECT ESP32-POE to computer’s USB port while it is powered by Ethernet POE!!! If you connect USB while ESP32-POE is powered by Ethernet you will damage the board or your computer or both. This will also void the warranty!

ESP32-POE-ISO, on the other hand comes with 3000VDC galvanic insulation between the Ethernet POE part and ESP32 power supply, so there is no problem to connect to USB and program or debug while the board is also powered from a PoE source.

## 1.5. The differences between different variants of ESP32-POE and ESP32-POE-ISO

ESP32-POE (https://www.olimex.com/Products/IoT/ESP32/ESP32-POE/open-source-hardware) and ESP32-POE-ISO (https://www.olimex.com/Products/IoT/ESP32/ESP32-POE-ISO/open-source-hardware) are the base versions with ESP32-WROOM module with 4MB flash memory and nothing extra.

ESP32-POE-EA (https://www.olimex.com/Products/IoT/ESP32/ESP32-POE-EA/open-source-hardware) and ESP32-POE-ISO-EA (https://www.olimex.com/Products/IoT/ESP32/ESP32-POE-ISO-EA/open-source-hardware) have ESP32-WROOM-32UE module with U.FL connector and external antenna attached.

ESP32-POE-IND (https://www.olimex.com/Products/IoT/ESP32/ESP32-POE-IND/open-source-hardware) and ESP32-POE-EA-IND (https://www.olimex.com/Products/IoT/ESP32/ESP32-POE-EA-IND/open-source-hardware) and ESP32-POE-ISO-IND (https://www.olimex.com/Products/IoT/ESP32/ESP32-POE-ISO-IND) and ESP32-POE-ISO-EA-IND (https://www.olimex.com/Products/IoT/ESP32/ESP32-POE-ISO-EA-IND) use industrial grade components suitable for -40+85C operating temperature.

ESP32-POE-WROVER (https://www.olimex.com/Products/IoT/ESP32/ESP32-POE-WROVER/open-source-hardware) and ESP32-POE-ISO-WROVER (https://www.olimex.com/Products/IoT/ESP32/ESP32-POE-ISO-WROVER) comes with ESP32-WROVER-E chip with 4MB flash and 8MB PSRAM, while ESP32-POE-WROVER-EA (https://www.olimex.com/Products/IoT/ESP32/ESP32-POE-WROVER-EA/open-source-hardware) and ESP32-POE-ISO-WROVER-EA (https://www.olimex.com/Products/IoT/ESP32/ESP32-POE-ISO-WROVER-EA) have a WROVER module with extra U.FL connector and external antenna attached.

ESP32-POE-16MB (https://www.olimex.com/Products/IoT/ESP32/ESP32-POE-16MB/open-source-hardware), ESP32-POE-EA-16MB (https://www.olimex.com/Products/IoT/ESP32/ESP32-POE-EA-16MB/open-source-hardware), ESP32-POE-ISO-16MB (https://www.olimex.com/Products/IoT/ESP32/ESP32-POE-ISO-16MB/open-source-hardware) and ESP32-POE-ISO-EA-16MB (https://www.olimex.com/Products/IoT/ESP32/ESP32-POE-ISO-EA-16MB/open-source-hardware) feature ESP32-WROOM with 16MB flash memory (as opposed to 4MB).

Features table:

Name/Features | ESP32 module | Flash size, MB | External antenna | Industrial range | PSRAM, MB | Isolated POE
ESP32-POE | ESP32-WROOM-32E-N4 | 4 | - | - | - | -
ESP32-POE-16MB | ESP32-WROOM-32E-N16 | 16 | - | - | - | -
ESP32-POE-EA | ESP32-WROOM-32UE | 4 | Y | - | - | -
ESP32-POE-EA-16MB | ESP32-WROOM-32E-N16 | 16 | Y | - | - | -
ESP32-POE-EA-IND | ESP32-WROOM-32UE | 4 | Y | Y | - | -
ESP32-POE-IND | ESP32-WROOM-32E-N4 | 4 | - | Y | - | -
ESP32-POE-WROVER | ESP32-WROVER-E | 4 | - | - | 8 | -
ESP32-POE-WROVER-EA | ESP32-WROVER-IE | 4 | Y | - | 8 | -
ESP32-POE-ISO | ESP32-WROOM-32E-N4 | 4 | - | - | - | Y
ESP32-POE-ISO-16MB | ESP32-WROOM-32E-N16 | 16 | - | - | - | Y
ESP32-POE-ISO-16MB-IND | ESP32-WROOM-32E-N16 | 16 | - | Y | - | Y
ESP32-POE-ISO-EA | ESP32-WROOM-32UE | 4 | Y | - | - | Y
ESP32-POE-ISO-EA-16MB | ESP32-WROOM-32UE-N16 | 16 | Y | - | - | Y
ESP32-POE-ISO-EA-IND | ESP32-WROOM-32UE | 4 | Y | Y | - | Y
ESP32-POE-ISO-IND | ESP32-WROOM-32E-N4 | 4 | - | Y | - | Y
ESP32-POE-ISO-WROVER | ESP32-WROVER-E | 4 | - | - | 8 | Y
ESP32-POE-ISO-WROVER-EA | ESP32-WROVER-IE | 4 | Y | - | 8 | Y

+ WROVER module uses two extra ESP32 pins for the PSRAM and these pins can’t be used for other purposes. This is important especially if you switch from regular version to WROVER version. This is easily noticeable in the middle of the schematic. GPIO16 and GPIO17 are used by the PSRAM, so GPIO17 that was used for Ethernet clock was replaced by GPIO0 and GPIO16 was replaced by GPIO33. You should do the requires software changes in your code if you switch from ESP32-POE to WROVER version.

## 1.6. Order codes for ESP32-POE and accessories

ESP32-POE (https://www.olimex.com/Products/IoT/ESP32/ESP32-POE/open-source-hardware) commercial grade 0-70C board with internal antenna

ESP32-POE-16MB (https://www.olimex.com/Products/IoT/ESP32/ESP32-POE-16MB/open-source-hardware) commercial grade 0-70C board with internal antenna and 16MB flash

ESP32-POE-EA (https://www.olimex.com/Products/IoT/ESP32/ESP32-POE-EA/open-source-hardware) commercial grade 0-70C board with external antenna

ESP32-POE-EA-16MB (https://www.olimex.com/Products/IoT/ESP32/ESP32-POE-EA-16MB/open-source-hardware) commercial grade 0-70C board with external antenna and 16MB flash

ESP32-POE-IND (https://www.olimex.com/Products/IoT/ESP32/ESP32-POE-IND/open-source-hardware) industrial grade -40+85C board with internal antenna

ESP32-POE-EA-IND (https://www.olimex.com/Products/IoT/ESP32/ESP32-POE-EA-IND/open-source-hardware) industrial grade -40+85C board with external antenna

ESP32-POE-WROVER (https://www.olimex.com/Products/IoT/ESP32/ESP32-POE-WROVER/open-source-hardware) commercial grade 0-70C board with 8MB PSRAM and internal antenna

ESP32-POE-WROVER-EA (https://www.olimex.com/Products/IoT/ESP32/ESP32-POE-WROVER-EA/open-source-hardware) commercial grade 0-70C board with 8MB PSRAM and external antenna

(https://www.olimex.com/Products/Power/Lipo-battery/BATTERY-LIPO1400mAh/)

BATTERY-LIPO1400mAh (https://www.olimex.com/Products/Power/Lipo-battery/BATTERY-LIPO1400mAh/) Lipo battery 3.7V 1400mAh – note these batteries can be shipped only by ground so we can deliver only to EU destinations.

UEXT modules (https://www.olimex.com/Products/Modules/) Different sensors, relays, LCDs, RTC, GSM, GPS, accessories which can be connected to UEXT connector

## 1.7. Order codes for ESP32-POE-ISO and accessories

ESP32-POE-ISO (https://www.olimex.com/Products/IoT/ESP32/ESP32-POE-ISO/open-source-hardware) commercial grade 0-70C board with internal antenna

ESP32-POE-ISO-16MB (https://www.olimex.com/Products/IoT/ESP32/ESP32-POE-ISO-16MB/open-source-hardware) commercial grade 0-70C board with internal antenna and 16MB flash

ESP32-POE-ISO-16MB-IND (https://www.olimex.com/Products/IoT/ESP32/ESP32-POE-ISO-16MB-IND/open-source-hardware) industrial grade -40+85C board with internal antenna and 16MB flash

ESP32-POE-ISO-EA (https://www.olimex.com/Products/IoT/ESP32/ESP32-POE-ISO-EA/open-source-hardware) commercial grade 0-70C board with external antenna

ESP32-POE-ISO-EA-16MB (https://www.olimex.com/Products/IoT/ESP32/ESP32-POE-ISO-EA-16MB/open-source-hardware) commercial grade 0-70C board with external antenna and 16MB flash

ESP32-POE-ISO-IND (https://www.olimex.com/Products/IoT/ESP32/ESP32-POE-ISO-IND/open-source-hardware) industrial grade -40+85C board with internal antenna

ESP32-POE-ISO-EA-IND (https://www.olimex.com/Products/IoT/ESP32/ESP32-POE-ISO-EA-IND/open-source-hardware) industrial grade -40+85C board with external antenna

ESP32-POE-ISO-WROVER (https://www.olimex.com/Products/IoT/ESP32/ESP32-POE-ISO-WROVER/open-source-hardware) commercial grade 0-70C board with 8MB PSRAM, internal antenna

ESP32-POE-ISO-WROVER-EA (https://www.olimex.com/Products/IoT/ESP32/ESP32-POE-ISO-WROVER-EA/open-source-hardware) commercial grade 0-70C board with 8MB PSRAM, external antenna

(https://www.olimex.com/Products/Power/Lipo-battery/BATTERY-LIPO1400mAh/)

BATTERY-LIPO1400mAh (https://www.olimex.com/Products/Power/Lipo-battery/BATTERY-LIPO1400mAh/) Lipo battery 3.7V 1400mAh – note these batteries can be shipped only by ground so we can deliver only to EU destinations.

UEXT modules (https://www.olimex.com/Products/Modules/) different sensors, relays, LCDs, RTC, GSM, GPS, accessories which can be connected to UEXT connector

# 2. HARDWARE

## 2.1. ESP32-POE layout

Ethernet connector

User button

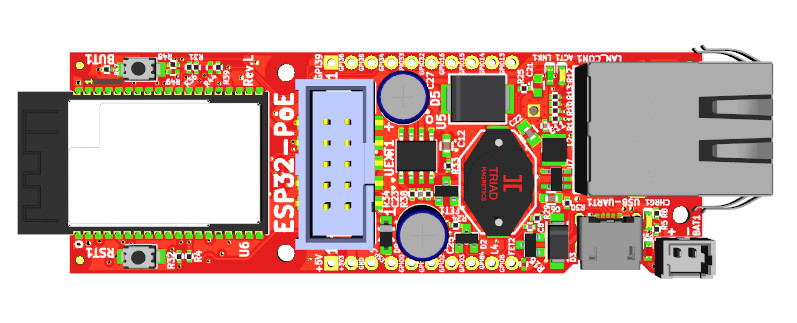
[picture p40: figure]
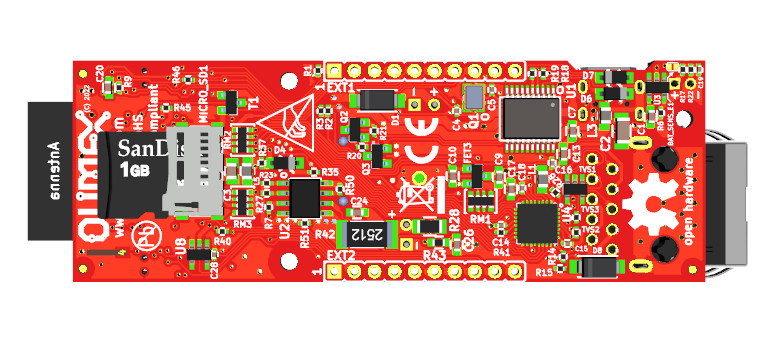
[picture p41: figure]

Micro SD card connector

mout hole

LiPo battery connector

USB connector

GPIOs

GPIOs

mout hole

reset button

ESP32 module

mout hole

## 2.2. ESP32-POE GPIOs

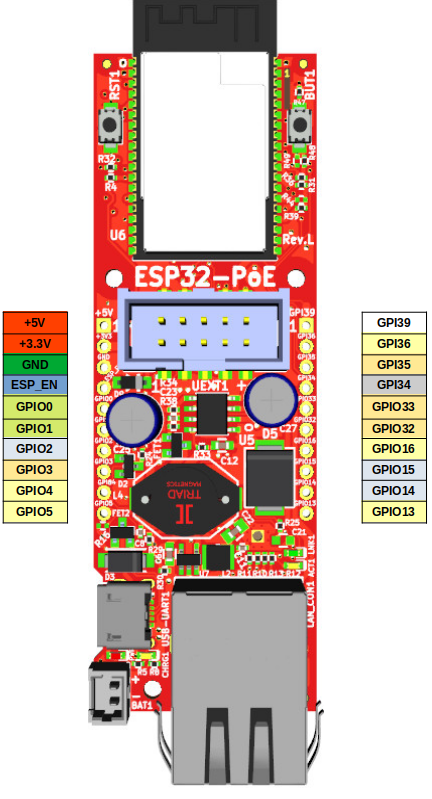
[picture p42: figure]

POWER SUPPLY pads:

+5V 1. Can be input and output; if you use it as input make sure no other 5V sourcesa re applied to the board (having Li-Po battery is OK);

2. When the board is attached to USB or to Ethernet PoE this line can be used ONLY as output to power attached peripherals;

3. If you want to use as input i.e. to feed power from external 5V to this line make sure that board is not connected to USB!

4. When you use the 5V line as output to power external devices it can provide up to 0.8A @ 5V (i.e. 4W) maximum. This includes the 3.3V power output. The combined power draw of +5V output and +3.3V output must not exceed 4W!

+3.3V output which can source up to 0.5A @ 3.3V i.e. (1.65W) Make sure the combined power sourced from +3.3V and +5V does not exceed 4W!

GND Ground, the board has common ground.

GPIO pads:

ESP_EN resets the ESP32 module

GPIO0, GPIO2 are boot mode bootstrap pins make sure they are properly configured during power up

GPIO1, GPIO3 are used for USB programming, they can be freed up if you won’t further program the board via USB

GPIO2, GPIO14, GPIO15 are used for the SD-card, if no SD card is preset they are free to use

GPIO2, GPIO4, GPIO5, GPIO13, GPIO14, GPIO15, GPIO16, GPIO36 are shared on both UEXT and EXT headers so if you use them on the one connector do not use them at the other

GPI39 is connected to measure external power supply voltage

GPI34 is connected to user button and has 10K pullup

GPI35 is free to use by default but may be connected to measure the LiPo battery voltage if you close BAT_SENS_E1 jumper

+ESP32-POE-WROVER and ESP32-POE-WROVER-EA have no GPIO16 or GPIO17 led out, since they are used for the PSRAM. These are replaced by GPIO33 and GPIO0. GPIO17 being replaced by GPIO0 is crucial for the Ethernet connectivity, since GPIO17/GPIO0 is Ethernet clock out. Make sure to use new assignments in your software if your board variant comes with the WROVER chip.

The ESP32 chip has very advanced multiplexing and you can define any free GPIO pin for I2C, UART, SPI operation as long as you are within the maximum supported (some penalties to SPI's maximum frequency apply, when not using the dedicated pins). Notice that some ESP32 pins can only be inputs. Defining pins for another function is purely software effort.

For further analysis of pins it is highly recommended to check on the schematic and also check the ESP32-WROOM/ESP32-WROVER documentation.

## 2.3. ESP32-POE-ISO GPIOs

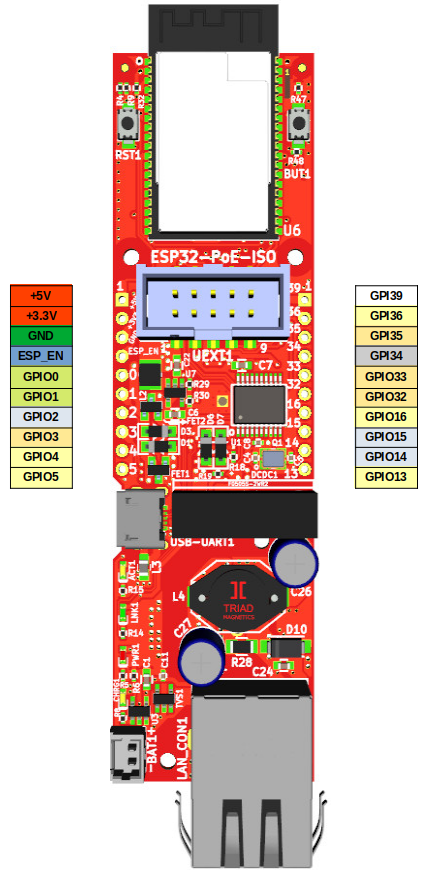
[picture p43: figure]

POWER SUPPLY pads:

+5V 1. Can be used as either input and output. f you use it as input make sure no other 5V source is applied to the board (Li-Po battery is OK);

2. When the board is connected to USB or to Ethernet PoE this line can be used as output and power supplement electronic

3. if you want to use as input i.e. to feed power from external 5V to this line make sure board is not connected to USB!

4. when you use as output i.e. you feed external electronics from it up to 0.2A @ 5V (i.e. 1W) can be sourced maximum. This includes the 3.3V power output. The combined power must not exceed 1W.

+3.3V output which can source up to 0.33A @ 3.3V i.e. (1W) - make sure the combined power sourced from +3.3V and +5V does not exceed 1W

GPIO pads:

ESP_EN resets ESP32 module

GPIO0, GPIO1 are used only during programming, after that are free to use

GPIO2, GPIO14, GPIO15 are used for the SD-card, if no SD card they are free to use

GPIO2, GPIO4, GPIO5, GPIO13, GPIO14, GPIO15, GPIO16, GPIO36 are shared on both UEXT and EXT headers so if you use them on the one connector do not use on the other

GPI39 is connected to measure external power supply voltage;

GPI35 is used for battery measurement of the LiPo battery;

GPI34 is connected to used button and has a 10K pullup resistor.

+ESP32-POE-ISO-WROVER and ESP32-POE-ISO-WROVER-EA have no GPIO16 and GPIO17 led out, since they are used for the PSRAM. GPIO16 is replaced by GPIO33. GPIO17 is replaced by GPIO0, this is important for the Ethernet connectivity, since GPIO17/GPIO0 is Ethernet clock out. Make sure to use new assignments if your board variant comes with the WROVER chip.

The ESP32 chip has very advanced multiplexing and you can define any free GPIO pin for I2C, UART, SPI operation as long as you are within the maximum supported (some penalties to SPI's maximum freqncy apply, when not using the dedicated pins). Notice that some ESP32 pins can only be inputs. Defining pins for another function is purely software effort.

For further analysis of pins it is highly recommended to check on the schematic and also check the ESP32-WROOM/ESP32-WROVER documentation.

## 2.4. ESP32-POE(-ISO) schematics

This is an open hardware design made with KiCAD. All design files and exports can be found at our GitHub.

ESP32-POE schematic hardware revision M1 is at GitHub (https://github.com/OLIMEX/ESP32-POE/blob/master/HARDWARE/ESP32-PoE-hardware-revision-M1/ESP32-PoE_Rev_M1.pdf)

ESP32-POE board revision changes are at GitHub (https://github.com/OLIMEX/ESP32-POE/blob/master/HARDWARE/Revision-changes.txt)

ESP32-POE-ISO schematic revision M is at GitHub (https://github.com/OLIMEX/ESP32-POE-ISO/blob/master/HARDWARE/ESP32-PoE-ISO-Rev.M/ESP32-PoE-ISO_Rev_M.pdf)

ESP32-POE-ISO board revision changes are at GitHub (https://github.com/OLIMEX/ESP32-POE-ISO/blob/master/HARDWARE/Hardware-changes-log.txt)

## 2.5. ESP32-POE(-ISO) power supply

ESP32-POE(-ISO) can be powered by 4 sources:

- Ethernet PoE
- USB-micro connector
- Li-Po battery
- EXT1 pin 1 (+5V) but note that this signal is connected to USB 5V signal so when you power via this EXT1 pin you should not connect the board to the USB!

- The standard power consumption of ESP32-POE(-ISO) is between 50mA and 200mA depending on the operation mode. When using power-down modes and Li-Po battery power it can go down to micro amperes.

- Li-Po battery gets automatically charged with about 100mA when external power supply is present.

When the LiPo battery is attached and external power supply is missing internal DCDC step-up converter and switching circuit automatically powers ESP32-POE from the battery. 1400mAh battery will provide about 8 hours of stand alone operation.

+The LiPo battery connector is JST 2.0 mm connector and with Olimex’s battery polarity. If you use batteries from other manufacturers please make PLUS and MINUS are connected properly as you may damage the board!

+ Is it safe to have USB and PoE connected and enabled at the same time? If you are using ESP32-POE or any of its variants – no, it is not safe and should be avoided at all costs. If you are using ESP32-POE-ISO or any of its variants – yes, it is safe to have them both attached and enabled.

### 2.5.1. External power sense feature

This allows to detect when the board has external powering. This is helpful if you want to switch between different power modes depending on whether the board is powered from a battery or external power source. By default the external power sense is enabled and it is available on GPI39!

Refer to this Arduino IDE example to see how you can check for the presence external power and check the battery measurement:

https://github.com/OLIMEX/ESP32-POE/blob/master/SOFTWARE/ARDUINO/ESP32_PoE_PowerReading/ESP32_PoE_PowerReading.ino

### 2.5.2. Battery measurement feature

This allows to measure the Li-Po battery’s voltage. This is helpful so you can evaluate when the battery is going to drain out so you can power off the board safely or switch to more conservative power method.

In ESP32-POE and its variants the battery measurement features is disabled by default but you can enabled it by soldering together the pads of STM jumper BAT_SENS_E1 jumper, after closing it – it will be routed to GPI35!

In ESP32-POE-ISO and its variants – the battery measurement is enabled and it is available on GPI35!

Refer to this Arduino IDE example to see how you can check for external power and check the battery measurement:

https://github.com/OLIMEX/ESP32-POE/blob/master/SOFTWARE/ARDUINO/ESP32_PoE_PowerReading/ESP32_PoE_PowerReading.ino

## 2.6. UEXT connector

UEXT connector stands for Universal EXTension connector and typically contains +3.3V, GND, UART, I2C, SPI signals.

UEXT is 0.1” 2.54mm step boxed plastic connector. All signals are with 3.3V levels.

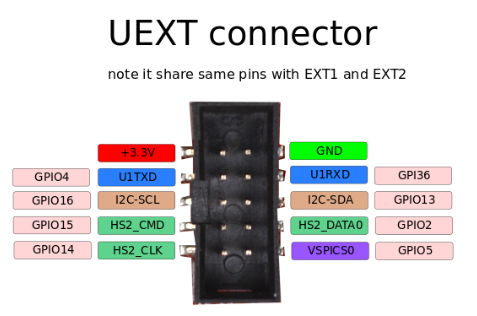
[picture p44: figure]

The 3.3V pin is only output.

Notice that the ESP32 GPIOs have to be defined in the code for their respective functions, e.g. define GPIO4 and GPIO36 for UART function before using them; define GPIO16 and GPIO13 for I2C, define GPIO15, GPIO2, GPIO14, GPIO5 for SPI.

GPIO15, GPIO2, GPIO14 are multiplexed with the SD card and if you have SPI device attached to them you’d have to use the chip select to switch between the card and the device connected to the UEXT.

Olimex has developed number of extension MODULES (https://www.olimex.com/Products/Modules/) compatible with this connector. There are temperature, humidity, pressure, magnetic field, light sensors. Modules with LCDs, LED matrix, relays, Bluetooth, Zigbee, Wi-Fi, GSM, GPS, RFID, RTC, EKG, sensors, and more.

## 2.7. ESP32-POE(-ISO) Ethernet connector

ESP32-POE and ESP32-POE-ISO have ETH8720 chip. All board variants use RJ45 LAN connector that is compatible with both PoE mode A and PoE mode B for PoE power delivery. Either mode is fine for the board.

How to define the Ethernet in the software?

It Arduino IDE this is done in the board configuration and you don’t have to specify the pins. Install the espresiff ESP32 package for Arduino IDE and make sure ESP32-POE or ESP32-POE-ISO is selected in the board selector and you are good to go. You can run the default Ethernet demo for LAN8720 without changes, go to File → Examples → Ethernet → ETH_LAN8720 verify and upload and open the serial terminal to see the results.

In other tools you might need to manually configure the pins. The pinout is as follows:

MDC – 23

MDIO – 18

PHY reset – 12

PHY RMII clock – 17 or 0 (17 in boards with WROOM module, 0 in boards with WROVER module)

If you use ESP-IDF v5.5 or newer just load the default Ethernet demo that comes with it and configure manually via menuconfig and edit the settings. Run:

idf.py menuconfig

Then navigate under "Example Ethernet Configuration" and make sure internal EMAC is selected and Ethernet PHY device is LAN87xx and set:

MDC – 23

MDIO – 18

PHY Reset – 12

PHY address – 0

It should look like this:

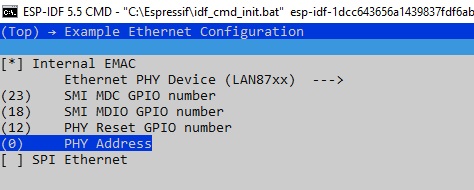
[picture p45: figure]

Then you also need to edit the settings for the Ethernet clock source – go back to Component config -> Ethernet -> Support ESP32 internal EMAC controller and remove the tick from Output RMII clock from GPIO0 (Experimental) and put RMII clock GPIO number to 17. Notice that if you use WROVER variant of the board put the tick om Output RMII clock from GPIO0 (Experimental).

For a regular board with WROOM module it should look like this:

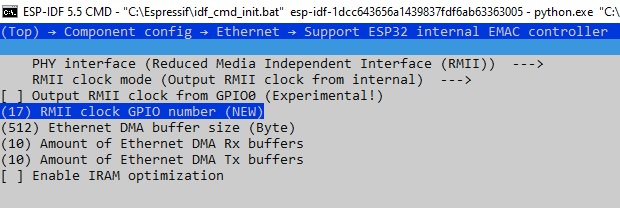
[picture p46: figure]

Notice the ESP32-POE and ESP32-POE-ISO boards use LAN8720A Ethernet chip. It is very important the LAN8720A to stay in reset (via GPIO12) until the ESP32 has generated the PHY clock (GPIO17/GPIO0, depending whether WROOM or WROVER variant). If there is no PHY clock generated when LAN8720A gets powered, the LAN8720A might hang! For more info refer to LAN8720A’s datasheet.

Usually the libraries take care of this by keeping the board in reset via GPIO12, but if it doesn’t you can do in your code. For example, in Arduino IDE you can first enable pin 17 (or pin 0 in WROVER module) to output and then hold pin 12 in reset for some moments BEFORE the Ethernet initialization like this:

pinMode(17, OUTPUT);

digitalWrite(17, HIGH); // enable external clock

// PHY reset sequence

pinMode(12, OUTPUT);

digitalWrite(12, LOW); // Hold PHY in reset

delay(300); // Keep it low for 300ms

digitalWrite(12, HIGH); // Release PHY reset

delay(50); // Wait 50ms for PHY clock to stabilize

// Start Ethernet: PHY reset = 12, PHY clock = 17

ETH.begin(ETH_PHY_LAN8720, 0, 23, 18, 12, ETH_CLOCK_GPIO17_OUT);

## 2.8. LED description

Board comes with 4 on-board status LEDs. These are not connected to the ESP32 directly and can’t be used as general purpose LEDs.

LED CHRG1 shows whether the Li-Po battery attached to the board is currently charging. When it is off it means that either there is no battery attached or it is already fully charged. Refer to "BL4054/BL4054B" datasheet and check for "CHRGb" port for more detailed information.

LED PWR1 is turned on when there is 5V DC applied to the board. It only actives from external power supply, USB power supply, or PoE powering. It won't turn on when board is powered from a Li-Po battery at BAT1 connector (to conserve energy required to power that LED).

LEDs LNK1 and ACT1 are Ethernet link and activity LEDs. LNK1 is turned on when 100 Mbps speed is detected, and turns off at 10Mbps or less. ACT1 blinks when activity is detected. For more information about their behavior, refer to the manual of "LAN8710A/LAN8710AI" and check the table describing "REGOFF" port (ACT1 is connected to it) and "nINTSEL" port (LNK1 is connected to it).

During USB power up the CHRG1 and PWR1 LEDs should light up.

Important! In order to reduce current consumption the LEDs would remain off when the board is powered from Li-Po battery! Do not count on the LEDs when the board is powered only from a Li-Po battery!

# 3. SOFTWARE

ESP32-POE and ESP32-POE-ISO are very popular boards and supported by a lot of software tools, among them (there are ready-to-use configs for ESP32-POE and ESP32-POE-ISO):

- Espressif ESP-IDF (https://docs.espressif.com/projects/esp-idf/en/latest/esp32/get-started/)
- Arduino IDE (https://github.com/espressif/arduino-esp32)
- MicroPython (https://micropython.org/download/OLIMEX_ESP32_POE/)
- ESPhome (https://github.com/esphome/bluetooth-proxies/blob/main/olimex-esp32-poe-iso.yaml)
- PlatformIO (https://docs.platformio.org/en/latest/boards/espressif32/esp32-poe.html)

## 3.1. Olimex-made software

We provide some examples for basic functions at our GitHub:

- For Arduino you can find them here:

https://github.com/OLIMEX/ESP32-POE/tree/master/SOFTWARE/ARDUINO

- For ESP-IDF here:

https://github.com/OLIMEX/ESP32-POE/tree/master/SOFTWARE/ESP-IDF

# 4. Frequently asked questions

- Is it safe to have USB powering and PoE powering connected and enabled at the same time?
  - If you are using ESP32-POE or any of its variants – no, it is not safe and should be avoided at all costs.
  - If you are using ESP32-POE-ISO or any of its variants – yes, it is safe to have them both enabled.
- Where are I2C, UART, SPI pins exposed?
  The ESP32 chip has very advanced multiplexing and you can define any free GPIO pin for I2C, UART, SPI operation as long as you are within the maximum supported (some penalties to SPI's maximum frequency apply, when not using the dedicated pins). Notice that some ESP32 pins can only be inputs. Double check if the pins you want to use are free. Defining pins for another function is a purely software effort.
- I provide 24V to the Ethernet of ESP32-PoE-ISO's but it doesn't seem powered. What is the problem?
  TPS2375PW (Si3402) would NOT work with 24V DC. The recommended voltage is 48V DC and the minimum is around 37V DC. For more info refer to TPS2375PW's (Si3402-B's) datasheet.
- What is the PoE class of the devices?
  ESP32-POE and ESP32-POE-ISO are set for class PoE class 0 operation (0.44W-12.95W).  There was one batch of ESP32-POE devices, hardware revision M, that are setup to class 4 operation (similar to ESP32-POE2). Class 4 operation might require more current since it requires at least 12.95W up to 25.5W, if you have trouble with ESP32-POE revision M devices refer to the schematic and remove resistor R54 to switch back to class 0 operation. This only applies to ESP32-POE boards from hardware revision M. ESP32-POE revision M1 were set to class 0 operation again.
- I have 10 of your boards connected to my switch but some doesn't seem to work. Are they broken?
- Switches reserve the maximum power for the board. Make sure the total power output of the switch is not exceeded. For 10 of these boards it needs to be capable to provide at least 150W (this is with the default setting for PoE Class 0, and if you changed the jumper state to upgrade the Class 0 to Class 4, then double it).
- What is the power delivery mode of these boards? Is it mode A or mode B?
  ESP32-POE and ESP32-POE-ISO and all variants use LAN connector that is compatible with both mode A or mode B. Either one is fine.
- I power the board from the Ethernet connector. What current do I have available for additional circuits?
  The ESP32-POE circuit can safely provide up to 4W in total. Part of this wattage is used to power the ESP32 module, the battery charger, and other circuits part of the board design; the remaining wattage is available for additional circuits (up to around 3W). So you can use 3W for own circuits around 600mA @ 5V or 900mA @ 3.3V (combined draw from 3.3V and 5V lines shouldn't be more than 3W) safely.
  The isolated DCDC in the design of ESP32-POE-ISO provides up to 2W in total but some power is used for the module itself and the battery charger. So you can use 1W for own circuits around 200mA @ 5V or 300mA @ 3.3V (combined draw from 3.3V and 5V lines shouldn't be more than 1W) safely.
- I power the board from the battery connector. The LEDs remain off. Is it broken?
  Probably not. This is a low-power design. The LEDs would not turn on when operating on battery to save power. You need other ways to determine if it works or not. For example, something over the serial lines or over the Ethernet (with no PoE enabled else it would get powered from there).
- A specific resistor gets very hot! What is this component? Is it safe? Can I remove it?
  This resistor is required by the IEEE standards. It is used for MPS (maintain power signature).
  Search online "maintain power signature poe" to get the general idea. It consumes around 0.5W, when the board is powered from Power-Over-Ethernet (notice the MPS resistor consumes 0 when the board is powered from other sources). We didn't ensure MPS in the first hardware revisions of the board (e.g. had no resistor in place), but this caused availability problems when using some power saving modes – the board consumed less wattage than PoE equipment can detect, which led to PoE equipment shutting the board off.
  If you have soldering experience and the resistor bothers you, you might try desoldering it and see if that effects your setup negatively. Notice that we don't recommend doing so.
- ESP32-PoE and ESP32-POE-ISO don't work well with bauds over 115200. What to do? We use CH340 daily for bauds up to 2M so it is not a hardware issue. Some older drivers might have wrong timings, causing worse throughput. Download and install the latest drivers for CH340. If you are using Linux make sure to try with these drivers: high-speed driver for Linux (https://github.com/OLIMEX/ch340-dkms).
- Help! Ethernet is not working. I use ESP32-POE-WROVER and ESP32-POE-ISO-WROVER. Is the device broken?
  Your board with a WROVER chip is not broken and we test each device with Ethernet, chances of broken device are very low. However, there is hardware difference in the pinout between boards with WROOM and WROVER modules – the WROVER module requires two extra pins for the PSRAM memory. One of the pins affects the Ethernet, the other – the I2C. When WROVER module is used (instead of the default WROOM) then GPIO16 and GPIO17 are unavailable (both are used for the PSRAM inside the module). In that case we have set GPIO33 to go on UEXT1 pin #5 (instead of GPIO16). Also the clock for the Ethernet is now GPIO0 (instead of GPIO17). Modify your software for these differences.
- Help! Ethernet is not working always upon power-up. If I press the reset or power cycle the board a few times it starts working. Is my device faulty?
  It is probably because your software didn’t utilize the PHY_PWR pin (GPIO12) properly. This behavior happens when the PHY controller (LAN8720) gets powered before the ESP32 module can generate the PHY clock. What your software should do is hold the LAN8720 in reset for few milliseconds via the PHY_PWR pin and release it from reset only after PHY clock is already generated by the ESP32 module. Simple software workarounds that can be tested are adding delay before Ethernet initialization or toggling GPIO12 to reset only the Ethernet chip until connection is restored.
- Even if I power the board from power jack the USB-serial converter CH340T appears to remain powered. This affects my readings of the serial. What can I do?
  Look at the schematic, the CH340 can get parasitically powered via GPIO3 if you haven't set the GPIO as input. It is a problem if GPIO3 is set as output. So make sure it is set as input.

# 5. Useful links

The main pages of ESP32-POE and ESP32-POE-ISO are the main hubs for other locations, make sure to first check the product page at our web-site.

ESP32-POE main product page:

https://www.olimex.com/Products/IoT/ESP32/ESP32-POE/open-source-hardware

ESP32-POE-ISO main product page:

https://www.olimex.com/Products/IoT/ESP32/ESP32-POE-ISO/open-source-hardware

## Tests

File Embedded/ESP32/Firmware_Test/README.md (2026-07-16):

# ESP32 V3 Signage Controller — Testing Build & System Reference

> **Purpose of this document:** A single, authoritative reference for the V3 smart-signage
> hardware and its firmware/software behaviour. It is written so that **any agent or engineer**
> opening this folder can understand the finalized wiring, the command/telemetry model, and what
> the testing build does — without reading every source file first.
>
> **Status:** Finalized hardware (user-confirmed 2026-07-13). Some software behaviours (failsafe,
> battery, HMI) are intentionally **deferred** and marked as such below. Do not treat deferred
> items as implemented.

---

## 0. System at a Glance

A distributed metro-signage network. Each **ESP32 edge node** drives LED signage (animated
left/right arrows + always-on static panels), monitors its own health (currents, voltages), and
talks over **Ethernet** to a **Raspberry Pi gateway**. The Pi bridges **Modbus TCP** (SCADA/PLC +
touch HMI) to **MQTT** (the ESP32 fleet), for up to 100 nodes.

```
  PLC / SCADA ──Modbus TCP──┐
                            ├──►  Raspberry Pi Gateway  ──MQTT──►  ESP32 nodes (x N)
  Touch HMI  ──Modbus TCP──┘        (Modbus <-> MQTT bridge)         │
                                                                     └─► LED signage + sensors
```

This folder (`Firmware_Test/`) contains the **testing build** — a Serial-driven hardware bring-up
sketch that validates the board **without** needing the Ethernet/MQTT/Modbus stack online. The
networked **production firmware** lives in `../Firmware/`.

---

## 1. Finalized Hardware Connections (V3)

> This section supersedes `PCB/PCB_V3/Connections.md` where they differ.

### 1.1 Power Tree

**Input protection chain (in order):**
```
14.5V Input Terminal Block (+) ──► Fuse Holder ──► 470uF Electrolytic Cap ──► Diode ──► Battery Terminal Block
                                                                                            │
                                                                        System Bus tapped HERE (post-diode)
```
- The **system bus** is taken *after* the diode, at the point where the backup **battery** ties in.
- The diode provides reverse-polarity / isolation between input and battery.

**Buck converters — 4x MP1584 (not 5; no floating spare):**

| Buck | Output | Feeds |
|---|---|---|
| MP1584 #1 | 12V | Static LED Zone 1 |
| MP1584 #2 | 12V | Static LED Zone 2 |
| MP1584 #3 | 12V | Left + Right arrow LEDs |
| MP1584 #4 | 5V  | ESP32, LAN8720, MCP23017, 4x ACS712, and AMS1117 input |

**Linear regulator — AMS1117-3.3:**
- Input from the **5V** MP1584.
- 3.3V rail feeds: ESP32 (3V3), LAN8720, MCP23017, and the I2C pull-ups on SDA (GPIO4) / SCL (GPIO13).

**Ground:** single **common GND** net across input, battery, all bucks, AMS1117, ESP32, PHY,
expander, all ACS712, and all MOSFET sources.

### 1.2 ESP32 ↔ LAN8720 (Ethernet PHY, RMII)

| Signal | ESP32 GPIO | Notes |
|---|---|---|
| MDC | 23 | Management clock |
| MDIO | 18 | Management data |
| CRS_DV | 27 | RMII carrier sense (fixed-function) |
| RXD0 | 25 | RMII (fixed-function) |
| RXD1 | 26 | RMII (fixed-function) |
| TXD0 | 19 | RMII (fixed-function) |
| TXD1 | 22 | RMII (fixed-function) |
| TX_EN | 21 | RMII (fixed-function) |
| nINT / REF_CLK | TX2 = **GPIO17** | **50 MHz reference clock OUT** → `ETH_CLOCK_GPIO17_OUT` |

> **Why GPIO17 matters:** GPIO17 sources the PHY reference clock. The I2C bus was therefore moved
> off 16/17 to **4/13** (see §1.4) to eliminate the clock conflict that existed in older firmware.

### 1.3 Analog Sensors (ADC1 only) — **4x ACS712**

| GPIO | Sensor | Role | Switched? |
|---|---|---|---|
| 36 (VP) | Voltage divider | PSU bus (14.5V → ≤3.0V) | — |
| 39 (VN) | Voltage divider | Battery (Vbatt → ≤3.0V) | — |
| 34 | ACS712 #1 | **LHS** arrow load | Yes (Port A) |
| 35 | ACS712 #2 | **RHS** arrow load | Yes (Port B) |
| 32 | ACS712 #3 | **Static Load 1** | No (always-on) |
| 33 | ACS712 #4 | **Static Load 2** | No (always-on) |

### 1.4 I2C Expander — MCP23017 @ `0x20`

| Pin | Connection |
|-----|---|
| VCC | 3.3V rail |
| RESET | 3.3V rail |
| A0 / A1 / A2 | GND (→ address `0x20`) |
| **SDA** | **GPIO4** (4.7kΩ pull-up to 3.3V) |
| **SCL** | **GPIO13** (4.7kΩ pull-up to 3.3V) |

### 1.5 MOSFET Outputs — 10x logic-level N-channel

| Group | Gates driven by | Series R | Pull-down |
|---|---|---|---|
| LHS (5 strips) | MCP23017 **Port A0–A4** | 100Ω | 10kΩ to GND |
| RHS (5 strips) | MCP23017 **Port B0–B4** | 100Ω | 10kΩ to GND |

- All MOSFET **Sources → common GND**; **Drains → LED strip (−) terminals**.
- **Only the LHS and RHS arrow strips are switched.** The two **static zones are permanently
  powered and only current-monitored** (no on/off control).

---

## 2. Software Functionality

### 2.1 Command Model (production firmware)

Commands arrive as a single integer (via MQTT `.../value`, bridged from Modbus):

- **Macro animations `0–4`** (arrow LEDs):
  - `0` All OFF · `1` Left chase · `2` Right chase · `3` Both chase · `4` Solid ON
- **Raw bitmask `10000–11023`**: subtract 10000 → 10-bit value. Low 5 bits → Port A (LHS),
  high 5 bits → Port B (RHS). Enables exact per-strip control of all 10 MOSFETs.

Static zones are not addressed by commands — they are always on.

### 2.2 Telemetry / Diagnostics

Each node reports a **4-state discrepancy** per switched load, computed by comparing the *intended*
state against *measured* current with dynamic, strip-count-scaled thresholds:

| State | Meaning |
|---|---|
| `ON` | Intended ON, current flowing |
| `OFF` | Intended OFF, no current |
| `FAIL_OPEN` | Intended ON, but no current (broken wire / burnt LED / open MOSFET) |
| `FAIL_SHORT` | Intended OFF, but current flowing (welded/shorted MOSFET) |

Plus PSU power health (`OK`/`FAIL`) and network status (`ONLINE:<ip>` / `OFFLINE`).

> **Channel count note:** current firmware publishes `current1` (LHS), `current2` (RHS),
> `current3` (Static 1). The finalized hardware adds a **4th ACS712 (Static 2)** → a **`current4`**
> channel and matching Modbus diagnostic slot must be added. Not yet implemented.

### 2.3 Communication

- **MQTT (ESP32 ↔ broker on Pi):**
  - RX: `metro/signage/register/<ID>/value`, `metro/signage/scan` (`PING`)
  - TX (retained): `.../status`, `/power`, `/current1`, `/current2`, `/current3` (+ future `/current4`)
  - Last Will & Testament publishes `OFFLINE` on disconnect.
- **Modbus TCP (Pi ↔ SCADA + HMI):** pymodbus server on port 502, single holding-register bank.

### 2.4 Holding Register Map (Pi gateway)

| Zone | Modbus reg | Address | Purpose |
|---|---|---|---|
| Active execution | 40001–40100 | 0–99 | Command pushed to each ESP32 |
| HMI manual buffer | 41001–41100 | 1000–1099 | Commands from touch HMI |
| SCADA auto buffer | 42001–42100 | 2000–2099 | Commands from PLC |
| MUX flag | 43001 | 3000 | 0 = SCADA/Auto, 1 = HMI/Manual |
| Diagnostics | 45001–45600 | 5000+ | N regs/node (status, power, LHS, RHS, batt, static…) |

> The per-node diagnostic layout will change when `current4` (Static 2) and the battery
> keep/cut decision are finalized. Treat the current 6-reg/node layout as provisional.

### 2.5 Watchdog Timer (internal hang-recovery) vs. Failsafe (network loss)

Two **separate** mechanisms — do not conflate them:

- **Watchdog** — ESP32 `esp_task_wdt`, **15s timeout, panic reset**, fed from both cores. Detects a
  frozen/deadlocked core and reboots the chip. It does **not** react to network loss.
- **Failsafe (LOCKED) = HOLD LAST COMMAND.** On network loss the node keeps executing the last
  command it received (no forced Solid-ON, no forced OFF). The last command is **persisted to NVS
  (flash)** on change and reloaded+applied on boot, so the last state survives a reboot even if the
  network is still down. If last state was `1`, it stays `1`.

### 2.6 Dual-Core Architecture (production firmware)

- **Core 1:** `loop()` — Ethernet events, MQTT parsing, non-blocking LED animation state machine.
- **Core 0:** `SensorTask` — ADC reads, median filtering, 4-state discrepancy logic.
- **IPC:** FreeRTOS queue (mailbox) shares state between cores without race conditions.

---

## 3. The Testing Build (`Firmware_Test.ino`)

Serial-driven hardware bring-up. **No Ethernet/MQTT/Modbus** — flash it to a bare board and confirm
what works. Uses the **finalized I2C pins (SDA=4, SCL=13)** and the same ACS712 calibration math as
production so calibration validates here.

**Serial menu (115200 baud):**

| Key | Action |
|-----|---|
| `0`–`4` | Toggle an LHS MOSFET (Port A0–A4) |
| `5`–`9` | Toggle an RHS MOSFET (Port B0–B4) |
| `a` / `x` | All MOSFETs ON / OFF |
| `c` | Run chase animation self-test (5 cycles) |
| `r` | Read all current sensors once |
| `s` | Toggle continuous 1 Hz current stream |
| `v` | Read PSU + battery divider voltages once |
| `h` | Reprint the menu |

> **Calibration placeholders:** ACS712 `SENS/ZERO` and the voltage-divider ratios in the sketch are
> starting values. Verify on the bench with a multimeter and update them before trusting readings.
>
> **Not yet in the test sketch:** the 4th ACS712 (GPIO33 / Static 2). To be added alongside the
> `current4` channel work.

---

## 4. Decision Log

### Locked (implement in production firmware)
1. **Failsafe = HOLD LAST COMMAND**, persisted to NVS (see §2.5). No forced ON/OFF.
2. **4th current channel (`current4`, Static 2)** — add across firmware + MQTT + Pi + register map.
   All 4 currents use the 4-state string; static channels are ON/FAIL_OPEN only.
3. **Modbus-offset bitmask (10000+)** stays; HMI will later expose it as a separate advanced panel.
4. **Watchdog** unchanged (internal hang-recovery, 15s panic reboot).

### Still open / deferred
1. **Battery monitoring** — **kept STUBBED**: reserve the register slot, leave unimplemented,
   revisit later. (Not removed, not active.)
2. **HMI rework** — still on the old 2-relay model; needs modes `0–4` + a separate bitmask panel.
   Deferred to the HMI phase.
3. **ACS712 calibration** — `SENS = 0.146` does not match a standard ACS712 variant. Confirm the
   sensor model (5A/20A/30A) and recalibrate on the bench.

---

## 5. File Map

| Path | What it is |
|---|---|
| `Firmware_Test/Firmware_Test.ino` | **This** testing/bring-up sketch |
| `Firmware_Test/README.md` | This document |
| `../Firmware/Firmware.ino` | Production networked firmware (dual-core, MQTT/Modbus) |
| `../Firmware/firmware_doc.md` | Production firmware doc (predates V3 hardware — verify against §1) |
| `../../RaspberryPi/Gateway/Pi.py` | Modbus↔MQTT bridge gateway |
| `../../RaspberryPi/HMI/HMI.py` | Touch HMI client (Tkinter) |
| `PCB/PCB_V3/Connections.md` | Older wiring doc — **superseded by §1 here** |

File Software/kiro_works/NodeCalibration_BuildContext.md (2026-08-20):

# Node Calibration Utility — Build Context

**Project:** `CompanyUtilityApp` — Node Calibration for the Smart Signage System
**Organisation:** I2ST Technologies Pvt. Ltd.
**Version:** 2.0.0
**Date:** 2026-08-20
**Root:** `CompanyUtilityApp\CompanyUtilityApp\`
**Build state:** `dotnet build` → **0 errors, 0 warnings** (was 0 errors, 80 warnings)

This is the handoff document: everything needed to build, configure, run and extend
the application without the conversation that produced it.

---

## 1. Project facts

| | |
|---|---|
| Type | Windows Forms desktop application |
| Framework | .NET 10.0 (`net10.0-windows`) |
| Language | C# 12, nullable reference types enabled and enforced |
| Database | SQL Server LocalDB — `NodeManagementDB` |
| Device transport | USB serial (`System.IO.Ports`), HTTP OTA (`HttpClient`), Modbus TCP (`NModbus4`) |
| Packages | `Microsoft.Data.SqlClient` 7.0.0 · `NModbus4` 2.1.0 · `System.IO.Ports` 10.0.7 |
| Hand-written C# | ~5,400 lines across 22 files |
| Root namespace | `CompanyUtilityApp` |

---

## 2. Solution layout

```
CompanyUtilityApp/
├─ .gitignore
└─ CompanyUtilityApp/
   ├─ CompanyUtilityApp.csproj      metadata, analyser policy, config copying
   ├─ appsettings.json              all externalised settings
   ├─ Program.cs                    entry point, global exception handling
   │
   ├─ Configuration/
   │  └─ AppConfig.cs               strongly typed settings loader
   │
   ├─ Models/
   │  ├─ User.cs                    operator identity + admin predicate
   │  ├─ Area.cs                    panel position (Areas table)
   │  ├─ Node.cs                    ESP32 controller (Nodes table)
   │  ├─ ViewModels.cs              NodeListItem, PanelDeploymentTarget
   │  ├─ DeviceConfigurationPayload.cs   firmware JSON contract + calibration
   │  └─ Settings.cs                technician/network settings + IPv4 validation
   │
   ├─ Security/
   │  └─ PasswordHasher.cs          PBKDF2 with legacy SHA-256 migration
   │
   ├─ Data/
   │  ├─ Db.cs                      connection factory, error translation, health check
   │  ├─ AuthRepository.cs          authentication, transparent hash upgrade
   │  ├─ AreaRepository.cs          panel reads/updates
   │  └─ NodeRepository.cs          node CRUD, calibration status
   │
   ├─ Services/
   │  ├─ DeviceConfigurationService.cs   serial + OTA deployment (static)
   │  ├─ ModbusDiagnosticsService.cs     Modbus TCP reads/writes (IDisposable)
   │  └─ SettingsService.cs              atomic JSON persistence
   │
   ├─ Infrastructure/
   │  ├─ AppLogger.cs               rolling file logger
   │  └─ UserSession.cs             session state + role gating
   │
   ├─ UI/
   │  └─ UserDialog.cs              dialog helpers + BusyScope
   │
   ├─ Forms/                        MainForm, LoginForm, AddEditNodeForm, EditAreaForm
   ├─ UserControls/                 9 screens
   ├─ Properties/                   Resources
   ├─ Resources/                    logo, icons
   └─ DocumentFiles/                user manual PDF
```

Namespaces now match folders (`CompanyUtilityApp.Forms`, `.UserControls`, `.Data`, …).
This is not cosmetic — see §4.1.

---

## 3. Database schema

`NodeManagementDB` on SQL Server LocalDB. Unchanged by this work; the application
reads it as it stands.

### Users
| Column | Type | Constraints |
|---|---|---|
| Id | INT | PK, IDENTITY |
| Username | NVARCHAR(50) | UNIQUE, NOT NULL |
| PasswordHash | NVARCHAR(255) | NOT NULL |
| FullName | NVARCHAR(100) | NOT NULL |
| CreatedAt | DATETIME | DEFAULT GETDATE() |

`PasswordHash` now holds either a legacy 64-character SHA-256 hex string or a
PBKDF2 record of the form `PBKDF2$<iterations>$<base64 salt>$<base64 hash>`. Both
are accepted; legacy rows are upgraded on next successful sign-in. The column is
already wide enough (255) for the PBKDF2 format, so no migration is required.

### Areas — 400 pre-seeded rows (4 routes × 100 panels)
| Column | Type | Constraints |
|---|---|---|
| Id | INT | PK, IDENTITY |
| Route | INT | NOT NULL |
| PanelLocation | INT | NOT NULL |
| HoldingRegister | INT | UNIQUE, NOT NULL |
| PanelSerialNumber | INT | UNIQUE, NOT NULL |
| Description | NVARCHAR(255) | NULL |

Plus `UNIQUE(Route, PanelLocation)`.
`HoldingRegister = 40000 + (Route-1)*100 + PanelLocation`, assigned at seed time and
treated as immutable.

### Nodes
| Column | Type | Default |
|---|---|---|
| Id | INT | PK, IDENTITY |
| NodeNumber | INT | UNIQUE, NOT NULL |
| PanelSerialNumber | INT | UNIQUE, NOT NULL, FK → Areas |
| LocalIPAddress | NVARCHAR(15) | UNIQUE, NOT NULL |
| Zerovolt_CS1 / _CS2 | FLOAT | 2.40 |
| Sensitivity_CS1 / _CS2 | FLOAT | 0.105 |
| Threshold_CS1 | FLOAT | 0.100 |
| Threshold_CS2 | FLOAT | 0.120 |
| BatteryCalibration | FLOAT | 0.0 |
| BatterySagCompensation | FLOAT | 0.0 |
| PSUThreshold | INT | 1800 |
| Calibration | BIT | 0 |

The database column names are retained; the C# model uses conventional
casing (`ZeroVoltCs1`, `IsCalibrated`) and maps explicitly in the repository.

---

## 4. What changed and why

The refactor was driven by defects and risks found while reading the code, not by
style preference. The items below are ordered by consequence.

### 4.1 Two methods contained SQL that could never execute

`NodeRepository` had two methods that referenced columns which do not exist. Both
would have thrown `SqlException` the first time they ran:

```sql
-- IpAddressExists: the column is LocalIPAddress, not IPAddress
SELECT COUNT(*) FROM Nodes WHERE IPAddress = @IPAddress

-- PanelLocationExistsForRoute: Nodes has neither Route nor PanelLocation;
-- both live on Areas
SELECT COUNT(*) FROM Nodes WHERE Route = @Route AND PanelLocation = @PanelLocation
```

`IpAddressExists` was replaced by `LocalIpExistsAsync` against the correct column.
`PanelLocationExistsForRoute` was **removed rather than fixed**: the constraint it
was reaching for — one node per panel — is already guaranteed by the unique
`Nodes.PanelSerialNumber` column, so a replacement would be redundant.

Neither was reachable from the UI, so this was latent rather than live. It is listed
first because it is the clearest evidence that the data layer had no test coverage.

### 4.2 A successful serial write was treated as a successful deployment

This was the most consequential defect. The old flow was:

```csharp
port.Write(data);
MessageBox.Show("Configuration sent successfully.");
NodeRepository.MarkCalibrated(selectedNode.PanelSerialNumber);
```

`SerialPort.Write` returning without throwing only means the bytes reached the local
UART buffer. It says nothing about whether a controller was attached, powered, running
the signage firmware, or willing to accept the JSON. An unplugged cable, a device in
bootloader mode, or a malformed payload all produced "sent successfully" and a node
flagged as calibrated **permanently**, while the hardware kept running stale
configuration. Because the Panel Settings screen only lists uncalibrated nodes, the
node then disappeared from the list and the mistake became invisible.

`DeviceConfigurationService` now requires an acknowledgement. It writes the payload,
then reads the controller's reply until the device falls quiet or a configurable
timeout expires, and classifies it:

- reply contains a confirmation token (`config saved`, `restarting`, …) → success
- reply contains a rejection token (`error`, `invalid`, `bad json`, …) → failure
- no reply, or an unrecognised reply → failure, reported as unconfirmed

`MarkCalibratedAsync` is called **only** on success. On any other outcome the operator
is told explicitly that the node has *not* been marked as calibrated, and the device's
raw reply is echoed into the serial monitor so they can see why.

The OTA path already had a real acknowledgement in the HTTP status code; it now
reports the response body on failure as well.

### 4.3 Every screen was reachable without signing in

`MainForm` contained the access-control code, commented out:

```csharp
//// Enable/disable protected features
//Node.Enabled = loggedIn;
//Area.Enabled = loggedIn;
...
```

Node creation, deletion and device deployment were all reachable with no
authentication. Sign-in existed but gated nothing except the visibility of the
username in the menu bar.

Access control now lives in `UserSession` and is applied by
`MainForm.ApplySessionState()`, with `NavigateProtected()` refusing to open a
protected screen and explaining why. Home remains available so there is always
somewhere to be.

The admin-only calibration panel was previously gated by a public `IsAdmin` property
that the host form had to remember to set, with the role decided by a string
comparison inside `MainForm`. It is now `UserSession.CanCalibrate`, decided in one
place.

### 4.4 Passwords were stored as unsalted SHA-256

```csharp
using (SHA256 sha256 = SHA256.Create())
    return BitConverter.ToString(sha256.ComputeHash(...)).Replace("-","").ToLower();
```

Two problems. SHA-256 is designed to be fast, so an attacker holding a copy of the
Users table can test billions of candidates per second on commodity hardware. And
with no salt, identical passwords produce identical hashes, so one precomputed table
breaks every account at once.

`PasswordHasher` now writes PBKDF2-HMAC-SHA256 with a 16-byte random salt and 600,000
iterations (OWASP's 2023 figure for this algorithm). Verification is fixed-time.

**Existing logins keep working.** `Verify` recognises the legacy 64-character hex
format, and on a successful sign-in against a legacy hash the stored value is
transparently rewritten as PBKDF2 — the one moment the plaintext is available. Nobody
has to reset anything, and a failed upgrade is logged without blocking the sign-in.

### 4.5 The application had no diagnostics and no crash handling

There was no logging of any kind, and no global exception handler. A dropped database
connection produced the Windows crash dialog and terminated the process, leaving
nothing to reconstruct the fault from — which for a tool used on site, on a
commissioning deadline, is expensive.

- `AppLogger` writes a dated rolling log to
  `%LOCALAPPDATA%\I2ST\NodeCalibration\logs`, pruned to 14 files. Every repository
  failure, deployment attempt, device reply and rejected sign-in is recorded.
- `Program` installs `Application.ThreadException`,
  `AppDomain.UnhandledException` and `TaskScheduler.UnobservedTaskException`. A
  UI-thread fault is now reported and **survivable** — the operator keeps their other
  work. A background fault is logged before the runtime tears down.
- A named mutex enforces a single instance. Two copies would compete for the same COM
  port and could send conflicting configuration to one controller.
- `Db.CheckHealthAsync` runs once at start-up and reports an unreachable database or
  missing tables immediately, rather than as a stack trace on first use.

### 4.6 Every database call blocked the UI thread

All ADO.NET calls were synchronous and made directly from event handlers, so the
window froze for the duration of each query. Everything is now `async`, with
`CancellationToken` support; controls cancel in-flight work when they are torn down,
so a query that returns after the screen closed cannot touch a disposed control.

`BusyScope` shows the wait cursor and disables the triggering control for the duration
of an operation, restoring both on dispose even if the operation throws — the previous
hand-rolled equivalents could leave a button permanently disabled on an early return.

### 4.7 The serial port leaked and could be used after close

```csharp
if (_serialPort != null && _serialPort.IsOpen)
{
    _serialPort.Close();
    _serialPort.DataReceived -= SerialPort_DataReceived;   // after the close
    _serialPort = null;                                    // never disposed
}
```

The handler was detached *after* the close, leaving a window in which a final
`DataReceived` could fire against a closing port, and the port was never disposed, so
the handle leaked on every connect/disconnect cycle. `DataReceived` also called
`this.Invoke` with no check that the handle still existed, which throws if the control
is being torn down while data arrives.

Now: handler detached first, then close, then `Dispose`. The receive path checks
`IsDisposed`/`IsHandleCreated`, uses `BeginInvoke`, and catches
`ObjectDisposedException` for the race that remains. The monitor buffer is capped at
100,000 characters — a chatty controller left connected for hours would otherwise grow
the text box until the process ran out of memory.

Disposal is wired through the designer's `Dispose(bool)` (as `ReleaseResources()`),
which is the reliable point: it runs when `MainForm` replaces the screen.

### 4.8 Replaced screens were never disposed

```csharp
panel2.Controls.Clear();   // detaches, does not dispose
```

A screen holding a serial port or Modbus socket kept it open for the life of the
process. `MainForm.Navigate()` now disposes the control it replaces, and disposes the
hosted screen on form close.

### 4.9 A dialog both did and did not save, depending on how it was opened

`AddEditNodeForm` returned data to the caller in add mode, but wrote to the database
itself in edit mode — calling `NodeRepository.UpdateNode` and
`AreaRepository.UpdateArea` from inside the dialog, and discarding the latter's
success/failure return value. The caller had no way to know which had happened.

The dialog now only validates and collects. Persistence belongs to the caller,
uniformly. It also carries the stored calibration constants through an edit
untouched — a detail worth noting, because rebuilding the `Node` without them would
have reset the record to model defaults on the next write.

### 4.10 Race-prone uniqueness checks

The original pattern was check-then-write:

```csharp
if (NodeRepository.NodeNumberExists(nodeNum)) { /* complain */ }
// ... another workstation can take the value here ...
NodeRepository.AddNode(node);
```

The pre-checks are kept, because they give a better message than a constraint
violation. But the database's unique constraints are now treated as the actual
guarantee: `AddAsync`/`UpdateAsync` catch SQL error 2627/2601 and return it as a
normal outcome with a message naming the offending field, parsed from the index name.

### 4.11 The Open File menu item ran the New File handler

```csharp
openFileToolStripMenuItem.Click += newFileToolStripMenuItem_Click;
```

Choosing "Open File" reported "New File created." The real `openFileToolStripMenuItem_Click`
existed but was never wired. Fixed in the designer. The `Upload/Download` button had
no handler wired at all; it is now connected.

### 4.12 A latent resource-lookup bug from folder/namespace mismatch

`MainForm.Designer.cs` uses:

```csharp
var resources = new ComponentResourceManager(typeof(MainForm));
TSB.Image = (Image)resources.GetObject("TSB.Image");
```

`ComponentResourceManager` looks up `<class namespace>.MainForm.resources`, while the
embedded resource name is derived from `RootNamespace` + folder path. The file lived in
`WindowForms\` while the class was in namespace `CompanyUtilityApp`, so the lookup
name (`CompanyUtilityApp.MainForm.resources`) did not match the manifest name
(`CompanyUtilityApp.WindowForms.MainForm.resources`). `GetObject` returned null and
the toolbar user icon silently never loaded.

The same mismatch affected every control in `UserControls\` except
`PanelSettingsControl`, which happened to already declare the matching namespace —
which is why that one worked.

Fixed by renaming `WindowForms\` → `Forms\` and aligning namespaces to folders
throughout. This is the reason the namespace normalisation was worth doing.

### 4.13 Two settings screens were entirely inert

`SettingsControl` and `NetworkControl` had designer layouts and code-behinds
containing nothing but empty label handlers. Anything typed was discarded when the
screen was replaced, and the Wi-Fi fields never hid because
`checkBox1_CheckedChanged` was empty. Neither screen had a Save button.

Both now load and save through `SettingsService`, with validation
(`Models\Settings.cs`) and a Save button added in code. The Wi-Fi group shows and
hides correctly. The Wi-Fi password field is masked — a visible pre-shared key on a
shared commissioning workstation is a real exposure.

`settings.json` is written to `%LOCALAPPDATA%\I2ST\NodeCalibration`, not beside the
executable: a Program Files directory is not writable by a standard user, so saving
next to the binary either fails or triggers UAC virtualisation. Writes are atomic
(temp file then replace), so an interrupted save cannot leave a file that fails to
parse on next launch.

### 4.14 Hardcoded deployment values

The connection string was a `private static readonly string` in `DatabaseHelper`, and
the Raspberry Pi address was one in `ModbusHelper`. Retargeting a deployment required
a rebuild.

All of it now lives in `appsettings.json`, loaded once into `AppConfig`. A malformed
file falls back to built-in defaults and reports why in the log and on start-up rather
than refusing to start — a site engineer should not be stranded by a stray comma.

### 4.15 Modbus connections leaked and could hang

`ModbusHelper.CreateMaster()` returned an `IModbusMaster` while keeping the underlying
`TcpClient` private, so callers had no way to close the socket — every connection
attempt leaked one. `TcpClient.Connect` also has no timeout of its own, so an
unreachable gateway blocked for the OS default (roughly 20 seconds on Windows),
freezing the caller.

`ModbusDiagnosticsService` owns both objects, implements `IDisposable`, and applies a
configurable connect timeout via a linked `CancellationTokenSource`. It decodes the
6-register diagnostic block into a typed `NodeDiagnostics` record and forces a
reconnect after any failure.

### 4.16 Calibration values were sent unvalidated

Any number that parsed was pushed to the device. Calibration constants translate raw
ADC counts into amps and volts, so a typo or a wrong unit silently corrupts every
subsequent reading the node publishes. `CalibrationOverride.TryValidate` now bounds
sensitivity to 0.001–1.0 V/A (the ACS712-class sensors on these panels sit in the
tens-to-hundreds of mV/A) and battery calibration to ±5 V.

Deployment is also now confirmed, spelling out whether calibration will be overwritten
or preserved, because the controller restarts on accepting a payload.

### 4.17 Miscellaneous

- `ToolStripStatusLabel_Click` set the label to the **literal string**
  `"_currentUser.FullName"`. Handler removed along with its designer wiring.
- Eight empty event handlers and their designer wiring removed.
- `AuthRepository` imported `Microsoft.VisualBasic.ApplicationServices`, which defines
  a competing `User` type; it worked by accident of resolution order. Removed.
- `MainForm.Designer.cs` was missing its `Dispose(bool)` body, which is why
  `components` produced CS0414. Restored.
- `Print` opened a `PrintDialog` and discarded the result — a dialog that could not
  print. It now says so plainly.
- The empty `Models\` folder declared in the csproj now contains actual models.
- Machine-local `CompanyUtilityApp.csproj.user` removed; `.gitignore` added.
- Nullable reference types were enabled but ignored (80 warnings). Now enforced:
  `WarningsAsErrors` covers the CS86xx nullable set, and generated designer files are
  excluded with `#nullable disable` — the approach the WinForms templates use, since
  designer fields are assigned inside `InitializeComponent()` where the analyser
  cannot see them.
- All machine-facing conversions pinned to `InvariantCulture`. Node numbers, IP
  addresses and register values must not vary with the operator's regional settings.
- Placeholder screens (Tests, I/O Activity, Upload/Download) now state their status
  instead of presenting controls that do nothing.

---

## 5. Firmware contract

The JSON sent to the ESP32. Two properties are load-bearing:

```json
{
  "Route": 2,
  "PanelLocation": 5,
  "PanelSerialNumber": 40005,
  "HoldingRegister": 40005,
  "Description": "Platform 3, Column B",
  "LocalIP": "192.168.1.105"
}
```

1. **`NodeNumber` is deliberately absent.** The controller derives its node identity
   from the holding register. Sending a second source of truth would let the two
   disagree.

2. **Calibration keys are omitted entirely unless an administrator supplied them.**
   The firmware only overwrites a stored constant when the corresponding key is
   present, so an absent key preserves the bench calibration. Sending nulls or zeros
   would wipe it. This is enforced by
   `[JsonIgnore(Condition = JsonIgnoreCondition.WhenWritingNull)]` on the three
   optional fields, not by convention.

With calibration, three additional keys appear: `Sensitivity_CS1`,
`Sensitivity_CS2`, `BatteryCalibration`.

Reset payload: `{"ResetConfig": true}` — clears stored preferences and restarts.

The controller restarts unconditionally after accepting configuration.

---

## 6. Modbus register map

Zero-based addresses, as used by `ModbusDiagnosticsService`.

| Purpose | Address | Notes |
|---|---|---|
| Node diagnostics block | `5000 + (N-1)*6` | 6 registers per node |
| ↳ +0 Status | | 1 = ONLINE |
| ↳ +1 Power | | 1 = OK |
| ↳ +2 Current 1 | | 1 = OK |
| ↳ +3 Current 2 | | 1 = OK |
| ↳ +4 Battery | | percent (0 / 50 / 100) |
| ↳ +5 Relay status | | 2-bit field, bit 0 = relay 1 |
| MUX | `3000` | Modbus 43001 |
| Manual relay | `1000 + (N-1)` | Modbus 41001+ |
| SCADA | `2000 + (N-1)` | Modbus 42001+ |

---

## 7. Configuration reference

`appsettings.json`, copied to the output directory on every build.

| Section | Key | Default | Purpose |
|---|---|---|---|
| Database | ConnectionString | LocalDB / NodeManagementDB | |
| | CommandTimeoutSeconds | 30 | |
| Modbus | GatewayHost | 192.168.1.10 | Raspberry Pi bridge |
| | Port | 502 | |
| | SlaveId | 1 | |
| | ConnectTimeoutMs | 3000 | prevents the 20 s OS default |
| | ReadWriteTimeoutMs | 3000 | |
| Serial | BaudRate | 115200 | |
| | DataBits / Parity / StopBits | 8 / None / One | |
| | ReadTimeoutMs / WriteTimeoutMs | 2000 | |
| | **DeviceAckTimeoutMs** | 8000 | how long to wait for the controller to confirm |
| Ota | RequestTimeoutSeconds | 5 | |
| | ConfigEndpoint | /config | |
| Routes | Count | 4 | drives every route dropdown |
| | PanelsPerRoute | 100 | |
| Logging | MinimumLevel | Information | Debug / Information / Warning / Error |
| | RetainedFileCount | 14 | |

---

## 8. Build and run

```powershell
cd CompanyUtilityApp\CompanyUtilityApp
dotnet build          # expect 0 errors, 0 warnings
dotnet run
```

Prerequisites:

1. **SQL Server LocalDB** with `NodeManagementDB` present, containing the `Users`,
   `Areas` and `Nodes` tables. The application reports an unreachable database or
   missing tables at start-up.
2. `Areas` seeded with the 400 route/panel rows.
3. At least one row in `Users`. Both password formats are accepted, so existing
   seeded credentials work unchanged.

Runtime paths:

| What | Where |
|---|---|
| Logs | `%LOCALAPPDATA%\I2ST\NodeCalibration\logs` |
| Settings | `%LOCALAPPDATA%\I2ST\NodeCalibration\settings.json` |
| Configuration | `appsettings.json` beside the executable |

---
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

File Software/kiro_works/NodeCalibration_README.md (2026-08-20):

# Node Calibration Utility

> Windows desktop application for commissioning and calibrating ESP32 edge controllers
> in a metro smart-signage system.
>
> **I2ST Technologies Pvt. Ltd.** · .NET 10 · Windows Forms · SQL Server LocalDB

---

## Table of Contents

1. [What this is](#1-what-this-is)
2. [My role in the project](#2-my-role-in-the-project)
3. [Features](#3-features)
4. [Architecture](#4-architecture)
5. [Database schema](#5-database-schema)
6. [Device communication](#6-device-communication)
7. [Project structure](#7-project-structure)
8. [Getting started](#8-getting-started)
9. [Configuration](#9-configuration)
10. [Engineering notes](#10-engineering-notes)
11. [Roadmap](#11-roadmap)

---

## 1. What this is

A metro station's smart-signage system runs on a network of **ESP32-based edge
controllers** — one per signage panel — distributed across four routes of up to 100
panels each. Each controller drives relays, monitors two current-sensing channels and
a battery, and publishes its state over MQTT to a Raspberry Pi that bridges it into
Modbus TCP for the station SCADA system.

Before a controller can join that network it has to be told **who it is**: its route,
its panel location, its panel serial number, the Modbus holding register it owns, and
its static IP address. It also needs per-device **calibration constants** that convert
raw ADC counts into amps and volts.

This application is the tool that does both. It is what a technician carries to a
panel with a laptop and a USB cable.

**Node Calibration Utility** provides:

- a managed record of every panel position and the controller installed at it,
- validated data entry with database-enforced uniqueness,
- configuration deployment over **USB serial** or **Ethernet (OTA)**, confirmed by
  the device before it is recorded as done,
- administrator-gated calibration with range checking,
- role-based access control over a SQL Server database.

---

## 2. My role in the project

The smart-signage system as a whole spans embedded firmware, a Python
MQTT-to-Modbus bridge, an ERPS fibre-optic ring across three managed switches, and
this desktop application.

**My contribution is this Windows Forms application** — the desktop tool covered by
this repository. I designed and built the UI, the data layer, the device
communication and the access control.

The firmware, the Raspberry Pi bridge and the network ring were built by other
members of the team. They are described here only where the desktop application has
to agree with them — the JSON contract in
[§6](#6-device-communication) and the register map in the build context document are
interface definitions I had to implement against, not code I wrote.

---

## 3. Features

### 3.1 Node Management
- Route-filtered grid of every installed controller, joined to its panel position.
- Add, edit and delete with full validation: IPv4 format, positive node numbers, and
  uniqueness on node number, IP address and panel serial number.
- Uncalibrated nodes are highlighted, so outstanding commissioning work is visible at
  a glance rather than requiring a column-by-column read.
- Double-click a row to edit.
- Records are re-read before an edit opens, so a node changed or removed from another
  workstation is detected instead of silently overwritten.

### 3.2 Area (Panel Position) Management
- All 100 panel positions for a selected route, from a table pre-seeded with every
  route/panel combination.
- Panel serial number and description are editable; route, panel location and holding
  register are read-only, because the firmware and the Modbus bridge both key off the
  register mapping.
- Changing a serial number requires explicit confirmation — it re-points the node
  foreign key and must match the number physically stencilled on the panel.

### 3.3 Configuration Deployment
- **Two transports**: USB serial for bench and on-panel work, HTTP OTA for
  controllers already on the network.
- **Acknowledgement required.** A deployment is only recorded as successful once the
  controller confirms it. Writing bytes to a COM port proves nothing about the device
  having received or accepted them, so the tool waits for a reply and classifies it.
  If the device stays silent or rejects the payload, the node is explicitly *not*
  marked as calibrated and the operator is told why.
- Live serial monitor with the device's own output, including its reply to the
  deployment.
- Pre-deployment confirmation stating the target, the transport, and whether
  calibration will be overwritten or preserved — the controller restarts on accepting
  a payload.
- Reset-to-defaults command that clears the controller's stored preferences.

### 3.4 Calibration Control
- Administrator-only. Calibration changes the meaning of every reading a node
  publishes, so it is deliberately restricted.
- Current values are pre-loaded from the database, so an operator adjusts from what
  the device is actually running rather than typing into empty boxes.
- Range-checked before transmission: sensitivity is bounded to the physically
  plausible band for the sensors in use, so a typo or a wrong unit is caught before it
  silently corrupts every subsequent measurement.
- Calibration keys are **omitted** from the payload unless supplied, because the
  firmware preserves any constant whose key is absent. Sending zeros would wipe the
  bench calibration.
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

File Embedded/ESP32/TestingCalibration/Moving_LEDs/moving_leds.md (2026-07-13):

# ESP32 5-Channel MOSFET LED Chase Controller

## Project Overview
This project uses an ESP32 DevKit V1 to control five 12V LED strips via IRLZ44N N-channel logic-level MOSFETs. It features a non-blocking, directional "chase" animation that creates the illusion of movement toward the left. The system is controlled dynamically via serial communication.
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

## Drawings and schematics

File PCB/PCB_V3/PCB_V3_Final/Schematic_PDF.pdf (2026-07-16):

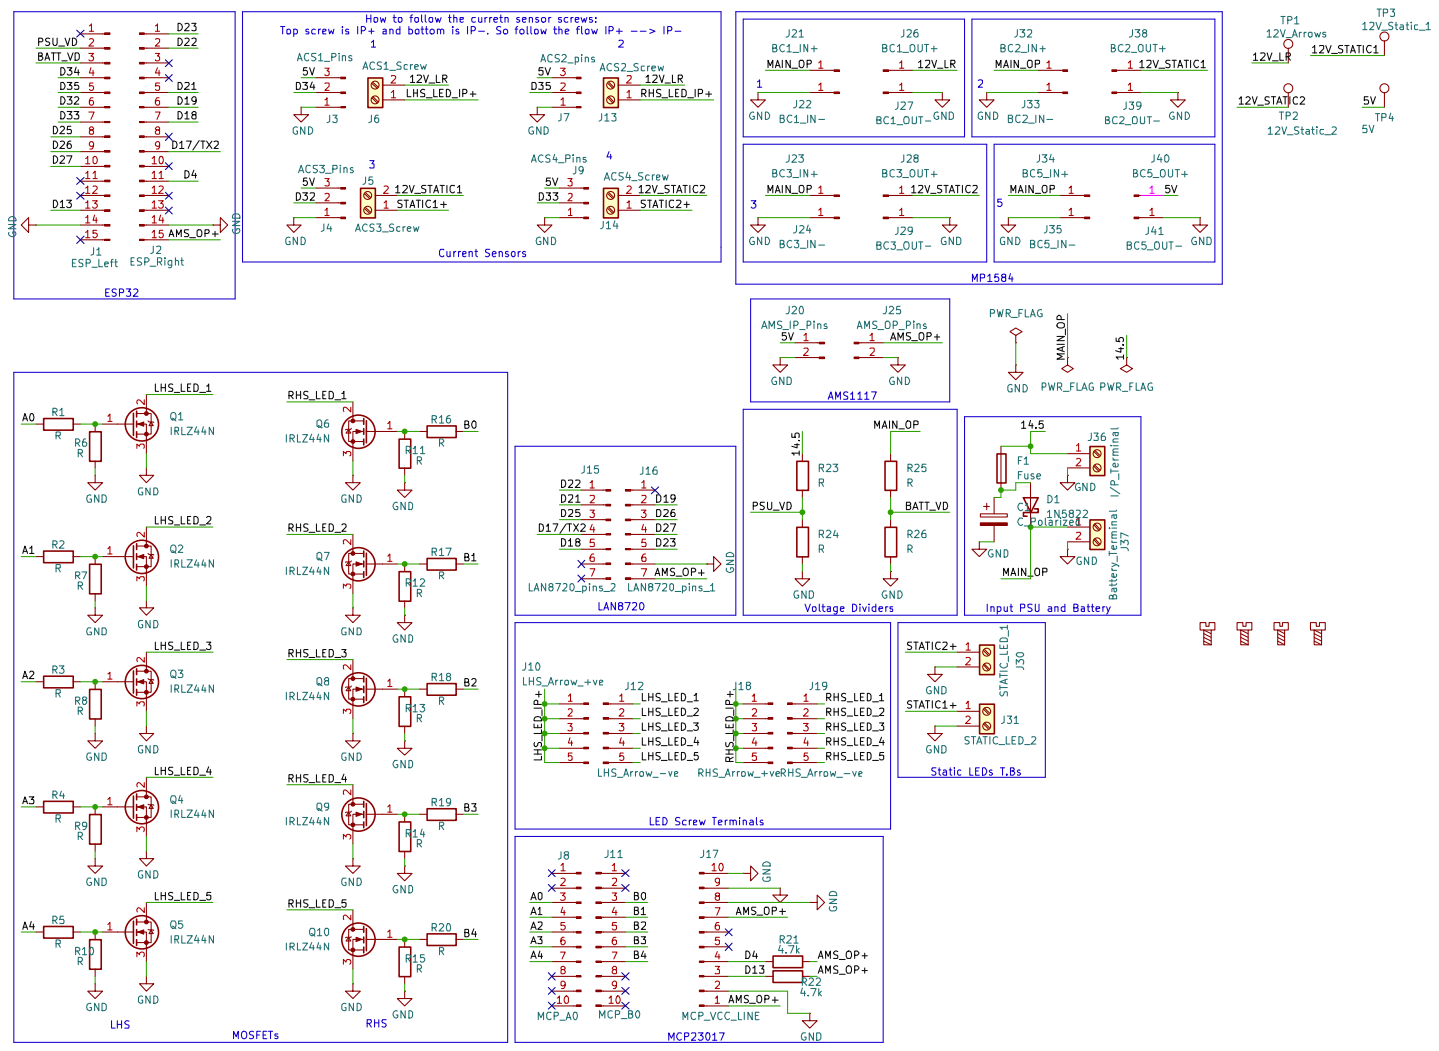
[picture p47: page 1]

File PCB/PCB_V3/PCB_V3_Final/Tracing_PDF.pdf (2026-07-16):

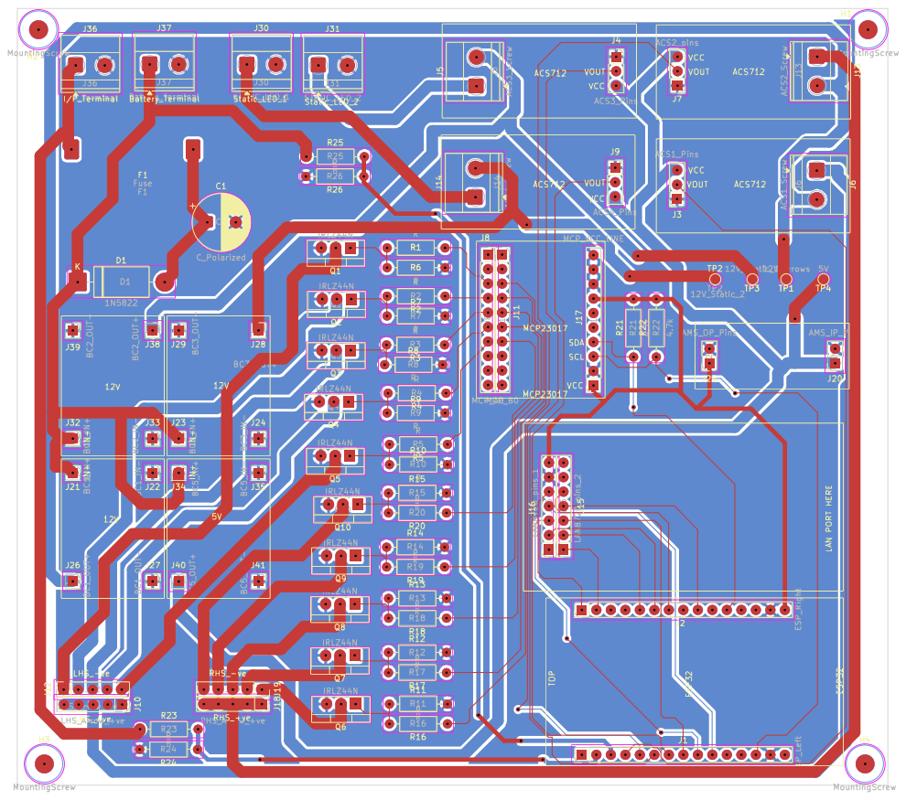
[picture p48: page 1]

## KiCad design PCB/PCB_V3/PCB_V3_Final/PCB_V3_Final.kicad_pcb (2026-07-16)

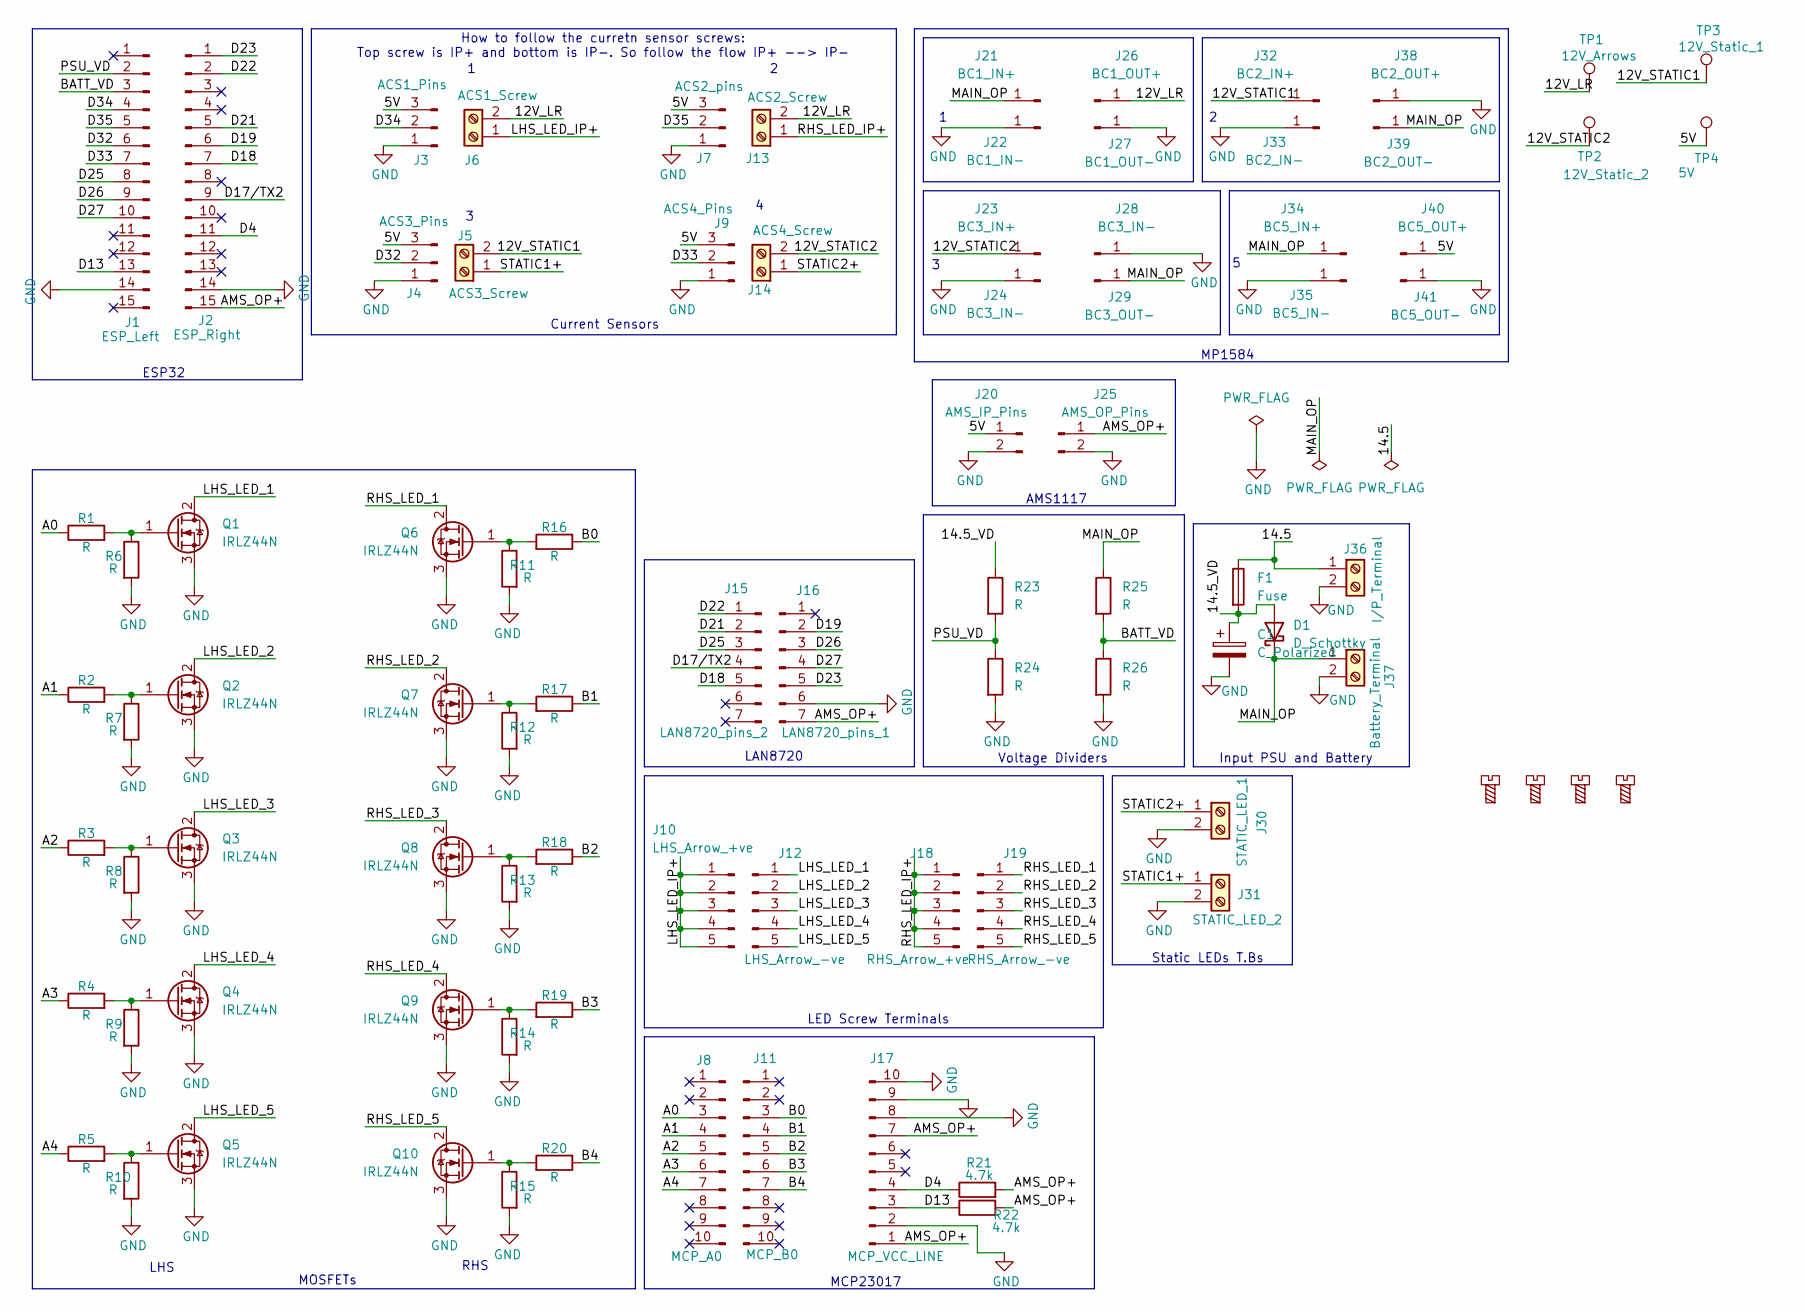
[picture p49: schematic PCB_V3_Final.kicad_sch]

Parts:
C1: C_Polarized; CP_Radial_D10.0mm_P5.00mm
D1: D_Schottky; TO-220-2_Vertical
F1: Fuse; Fuseholder_BF020_21.3mmm
H1, H2, H3, H4: MountingScrew; MountingHole_3.2mm_M3
J1: ESP_Left; PinHeader_1x15_P2.54mm_Vertical
J2: ESP_Right; PinHeader_1x15_P2.54mm_Vertical
J3: ACS1_Pins; PinSocket_1x03_P2.54mm_Vertical
J4: ACS3_Pins; PinSocket_1x03_P2.54mm_Vertical
J5: ACS3_Screw; TerminalBlock_Phoenix_MKDS-1,5-2-5.08_1x02_P5.08mm_Horizont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
J6: ACS1_Screw; TerminalBlock_Phoenix_MKDS-1,5-2-5.08_1x02_P5.08mm_Horizont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
J7: ACS2_pins; PinHeader_1x03_P2.54mm_Vertical
J8: MCP_A0; PinSocket_1x10_P2.54mm_Vertical
J9: ACS4_Pins; PinSocket_1x03_P2.54mm_Vertical
J10: LHS_Arrow_+ve; PinSocket_1x05_P2.54mm_Vertical
J11: MCP_B0; PinSocket_1x10_P2.54mm_Vertical
J12: LHS_Arrow_-ve; PinSocket_1x05_P2.54mm_Vertical
J13: ACS2_Screw; TerminalBlock_Phoenix_MKDS-1,5-2-5.08_1x02_P5.08mm_Horizont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
J14: ACS4_Screw; TerminalBlock_Phoenix_MKDS-1,5-2-5.08_1x02_P5.08mm_Horizont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
J15: LAN8720_pins_2; PinSocket_1x07_P2.54mm_Vertical
J16: LAN8720_pins_1; PinSocket_1x07_P2.54mm_Vertical
J17: MCP_VCC_LINE; PinSocket_1x10_P2.54mm_Vertical
J18: RHS_Arrow_+ve; PinSocket_1x05_P2.54mm_Vertical
J19: RHS_Arrow_-ve; PinSocket_1x05_P2.54mm_Vertical
J20: AMS_IP_Pins; PinSocket_1x02_P2.54mm_Vertical
J21: BC1_IN+; PinSocket_1x01_P2.54mm_Vertical
J22: BC1_IN-; PinSocket_1x01_P2.54mm_Vertical
J23: BC3_IN+; PinSocket_1x01_P2.54mm_Vertical
J24, J28: BC3_IN-; PinSocket_1x01_P2.54mm_Vertical
J25: AMS_OP_Pins; PinSocket_1x02_P2.54mm_Vertical
J26: BC1_OUT+; PinSocket_1x01_P2.54mm_Vertical
J27: BC1_OUT-; PinSocket_1x01_P2.54mm_Vertical
J29: BC3_OUT-; PinSocket_1x01_P2.54mm_Vertical
J30: STATIC_LED_1; TerminalBlock_Phoenix_MKDS-1,5-2-5.08_1x02_P5.08mm_Horizont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
J31: STATIC_LED_2; TerminalBlock_Phoenix_MKDS-1,5-2-5.08_1x02_P5.08mm_Horizont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
J32: BC2_IN+; PinSocket_1x01_P2.54mm_Vertical
J33: BC2_IN-; PinSocket_1x01_P2.54mm_Vertical
J34: BC5_IN+; PinSocket_1x01_P2.54mm_Vertical
J35: BC5_IN-; PinSocket_1x01_P2.54mm_Vertical
J36: I/P_Terminal; TerminalBlock_Phoenix_MKDS-1,5-2-5.08_1x02_P5.08mm_Horizont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
J37: Battery_Terminal; TerminalBlock_Phoenix_MKDS-1,5-2-5.08_1x02_P5.08mm_Horizont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
J38: BC2_OUT+; PinSocket_1x01_P2.54mm_Vertical
J39: BC2_OUT-; PinSocket_1x01_P2.54mm_Vertical
J40: BC5_OUT+; PinSocket_1x01_P2.54mm_Vertical
J41: BC5_OUT-; PinSocket_1x01_P2.54mm_Vertical
Q1, Q2, Q3, Q4, Q5, Q6, Q7, Q8, Q9, Q10: IRLZ44N; TO-220-3_Vertical
R1, R2, R3, R4, R5, R6, R7, R8, R9, R10, R11, R12, R13, R14, R15, R16, R17, R18, R19, R20, R23, R24, R25, R26: R; R_Axial_DIN0207_L6.3mm_D2.5mm_P10.16mm_Horizontal
R21, R22: 4.7k; R_Axial_DIN0207_L6.3mm_D2.5mm_P10.16mm_Horizontal
TP1: 12V_Arrows; TestPoint_Pad_D1.5mm
TP2: 12V_Static_2; TestPoint_Pad_D1.5mm
TP3: 12V_Static_1; TestPoint_Pad_D1.5mm
TP4: 5V; TestPoint_Pad_D1.5mm

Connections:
/5V: J3.3, J4.3, J7.3, J9.3, J20.1, J40.1 (Pin_1_1), TP4.1 (1_1)
/12V_LR: J6.2, J13.2, J26.1 (Pin_1_1), TP1.1 (1_1)
/12V_STATIC1: J5.2, J32.1 (Pin_1_1), TP3.1 (1_1)
/12V_STATIC2: J14.2, J23.1 (Pin_1_1), TP2.1 (1_1)
/14.5: F1.1, J36.1
/14.5_VD: C1.1, D1.2 (A), F1.2, R23.1
/A0: J8.3, R1.1
/A1: J8.4, R2.1
/A2: J8.5, R3.1
/A3: J8.6, R4.1
/A4: J8.7, R5.1
/AMS_OP+: J2.15, J16.7, J17.1, J17.7, J25.1, R21.2, R22.2
/B0: J11.3, R16.1
/B1: J11.4, R17.1
/B2: J11.5, R18.1
/B3: J11.6, R19.1
/B4: J11.7, R20.1
/BATT_VD: J1.3, R25.2, R26.1
/D4: J2.11, J17.4, R21.1
/D13: J1.13, J17.3, R22.1
/D17/TX2: J2.9, J15.4
/D18: J2.7, J15.5
/D19: J2.6, J16.2
/D21: J2.5, J15.2
/D22: J2.2, J15.1
/D23: J2.1, J16.5
/D25: J1.8, J15.3
/D26: J1.9, J16.3
/D27: J1.10, J16.4
/D32: J1.6, J4.2
/D33: J1.7, J9.2
/D34: J1.4, J3.2
/D35: J1.5, J7.2
/LHS_LED_1: J12.1, Q1.2 (D)
/LHS_LED_2: J12.2, Q2.2 (D)
/LHS_LED_3: J12.3, Q3.2 (D)
/LHS_LED_4: J12.4, Q4.2 (D)
/LHS_LED_5: J12.5, Q5.2 (D)
/LHS_LED_IP+: J6.1, J10.1, J10.2, J10.3, J10.4, J10.5
/MAIN_OP: D1.1 (K), J21.1 (Pin_1_1), J29.1 (Pin_1_1), J34.1 (Pin_1_1), J37.1, J39.1 (Pin_1_1), R25.1
/PSU_VD: J1.2, R23.2, R24.1
/RHS_LED_1: J19.1, Q6.2 (D)
/RHS_LED_2: J19.2, Q7.2 (D)
/RHS_LED_3: J19.3, Q8.2 (D)
/RHS_LED_4: J19.4, Q9.2 (D)
/RHS_LED_5: J19.5, Q10.2 (D)
/RHS_LED_IP+: J13.1, J18.1, J18.2, J18.3, J18.4, J18.5
/STATIC1+: J5.1, J31.1
/STATIC2+: J14.1, J30.1
GND: C1.2, J1.14, J2.14, J3.1, J4.1, J7.1, J9.1, J16.6, J17.2, J17.8, J17.9, J17.10, J20.2, J22.1 (Pin_1_1), J24.1 (Pin_1_1), J25.2, J27.1 (Pin_1_1), J28.1 (Pin_1_1), J30.2, J31.2, J33.1 (Pin_1_1), J35.1 (Pin_1_1), J36.2, J37.2, J38.1 (Pin_1_1), J41.1 (Pin_1_1), Q1.3 (S), Q2.3 (S), Q3.3 (S), Q4.3 (S), Q5.3 (S), Q6.3 (S), Q7.3 (S), Q8.3 (S), Q9.3 (S), Q10.3 (S), R6.2, R7.2, R8.2, R9.2, R10.2, R11.2, R12.2, R13.2, R14.2, R15.2, R24.2, R26.2
unnamed: Q1.1 (G), R1.2, R6.1
unnamed: Q2.1 (G), R2.2, R7.1
unnamed: Q3.1 (G), R3.2, R8.1
unnamed: Q4.1 (G), R4.2, R9.1
unnamed: Q5.1 (G), R5.2, R10.1
unnamed: Q6.1 (G), R11.1, R16.2
unnamed: Q7.1 (G), R12.1, R17.2
unnamed: Q8.1 (G), R13.1, R18.2
unnamed: Q9.1 (G), R14.1, R19.2
unnamed: Q10.1 (G), R15.1, R20.2

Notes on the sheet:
MP1584
ESP32
Voltage Dividers
How to follow the curretn sensor screws: Top screw is IP+ and bottom is IP-. So follow the flow IP+ --> IP-
LAN8720
Input PSU and Battery
MOSFETs
RHS
LED Screw Terminals
AMS1117
LHS
Current Sensors
Static LEDs T.Bs
MCP23017

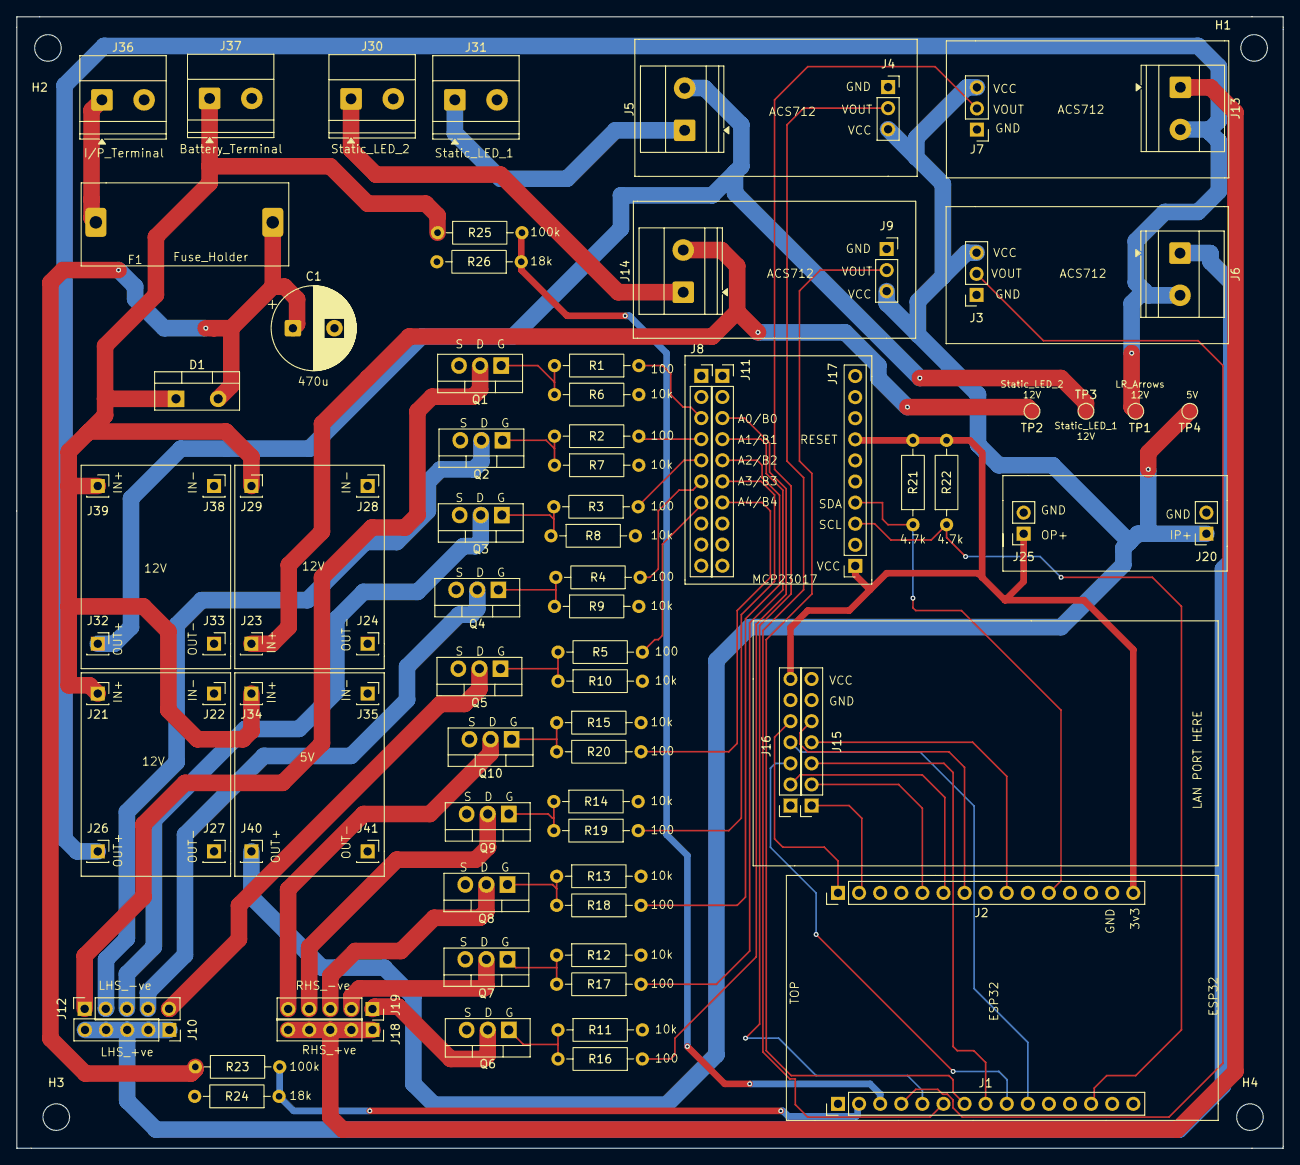
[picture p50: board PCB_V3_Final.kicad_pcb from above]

Board: 2 copper layers, 152.5 x 136.2 mm, 88 parts (0 on the bottom side), 60 nets.

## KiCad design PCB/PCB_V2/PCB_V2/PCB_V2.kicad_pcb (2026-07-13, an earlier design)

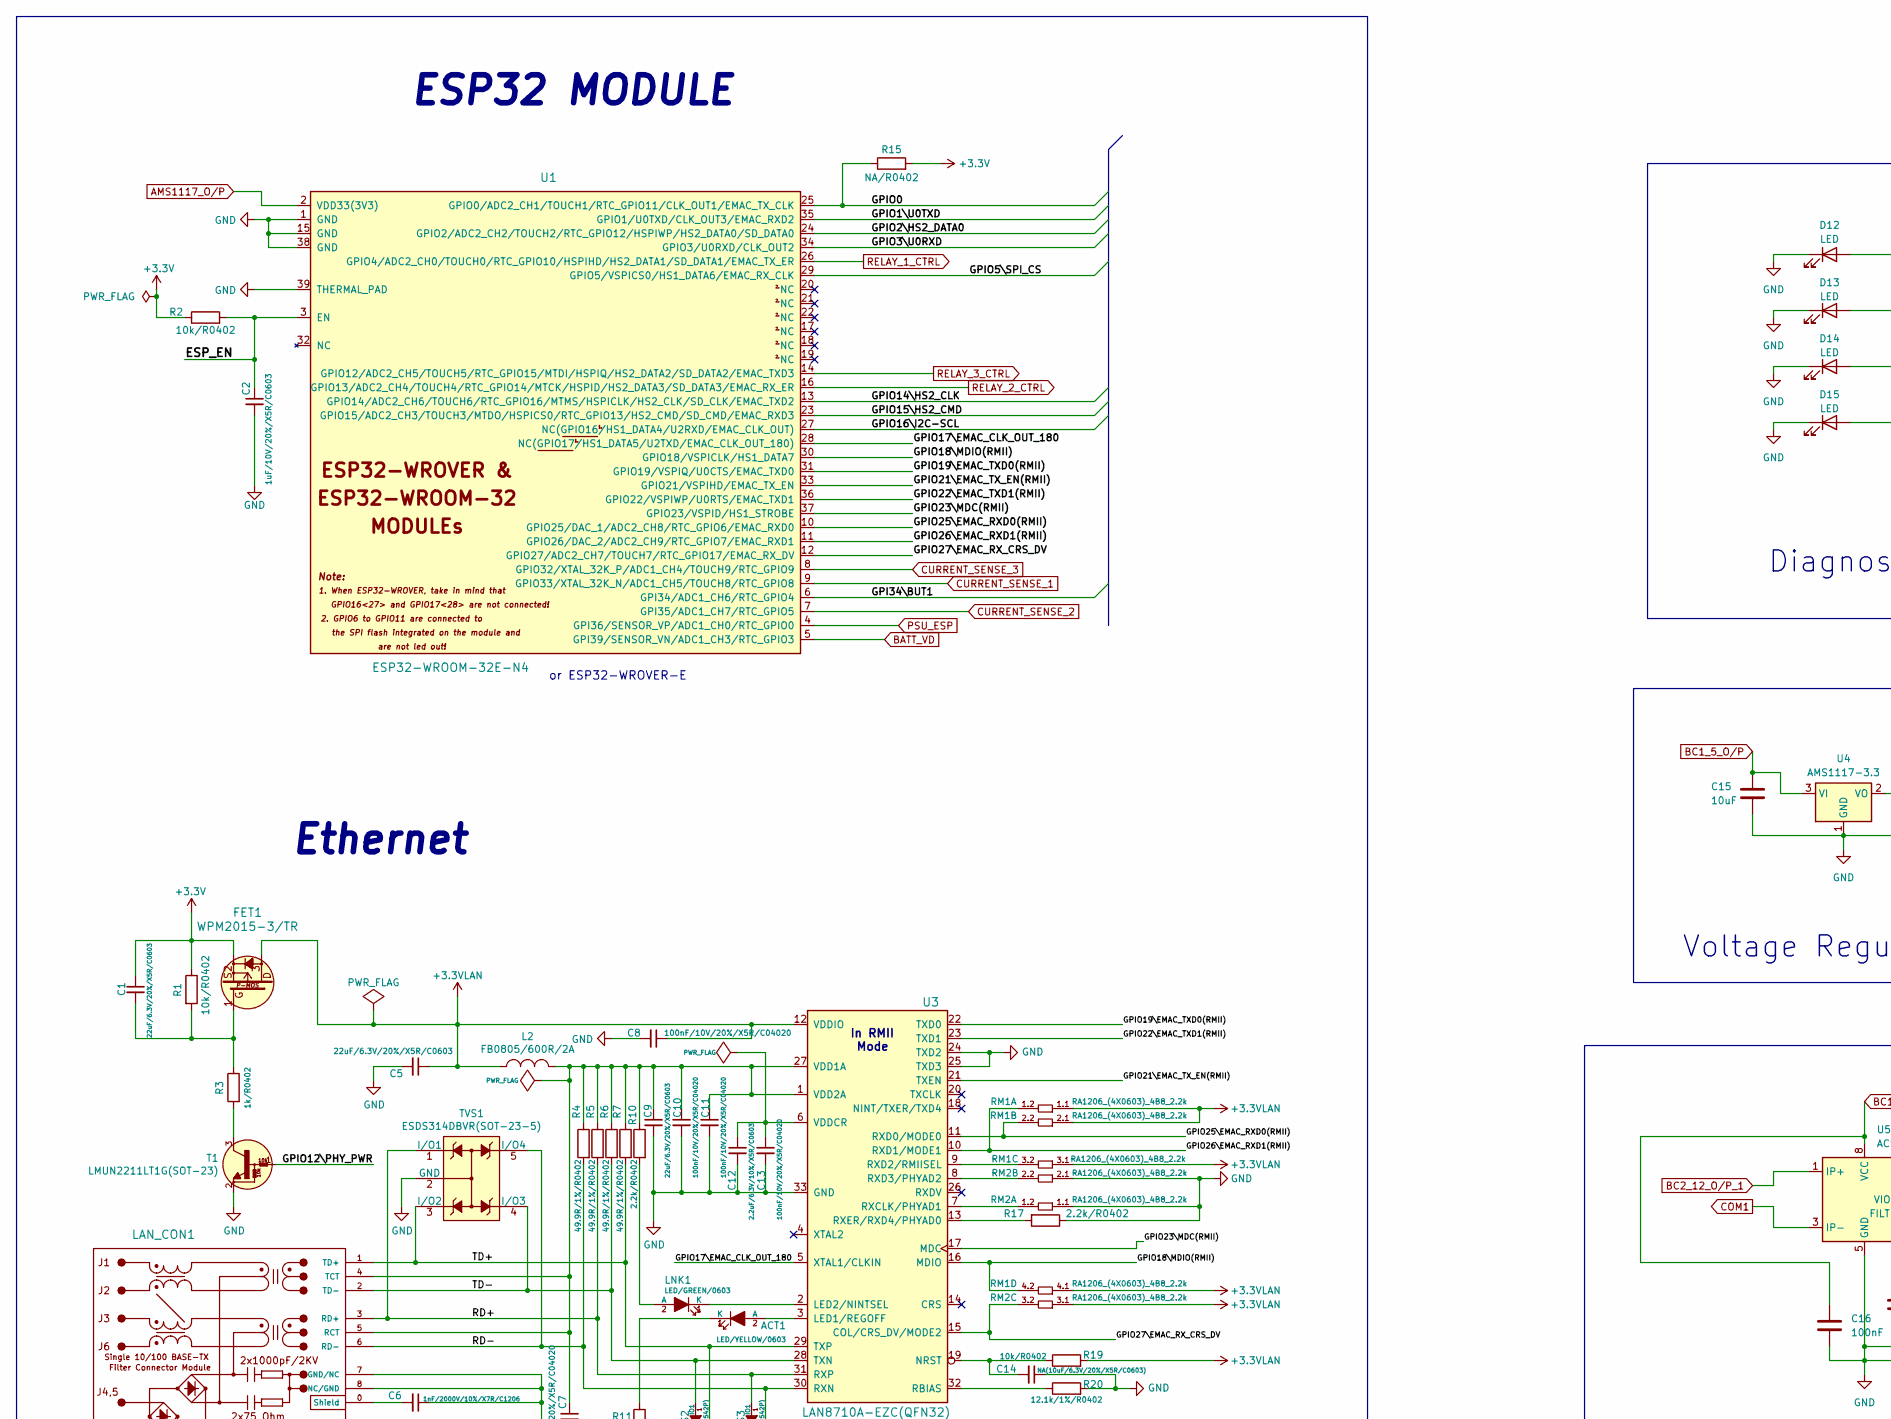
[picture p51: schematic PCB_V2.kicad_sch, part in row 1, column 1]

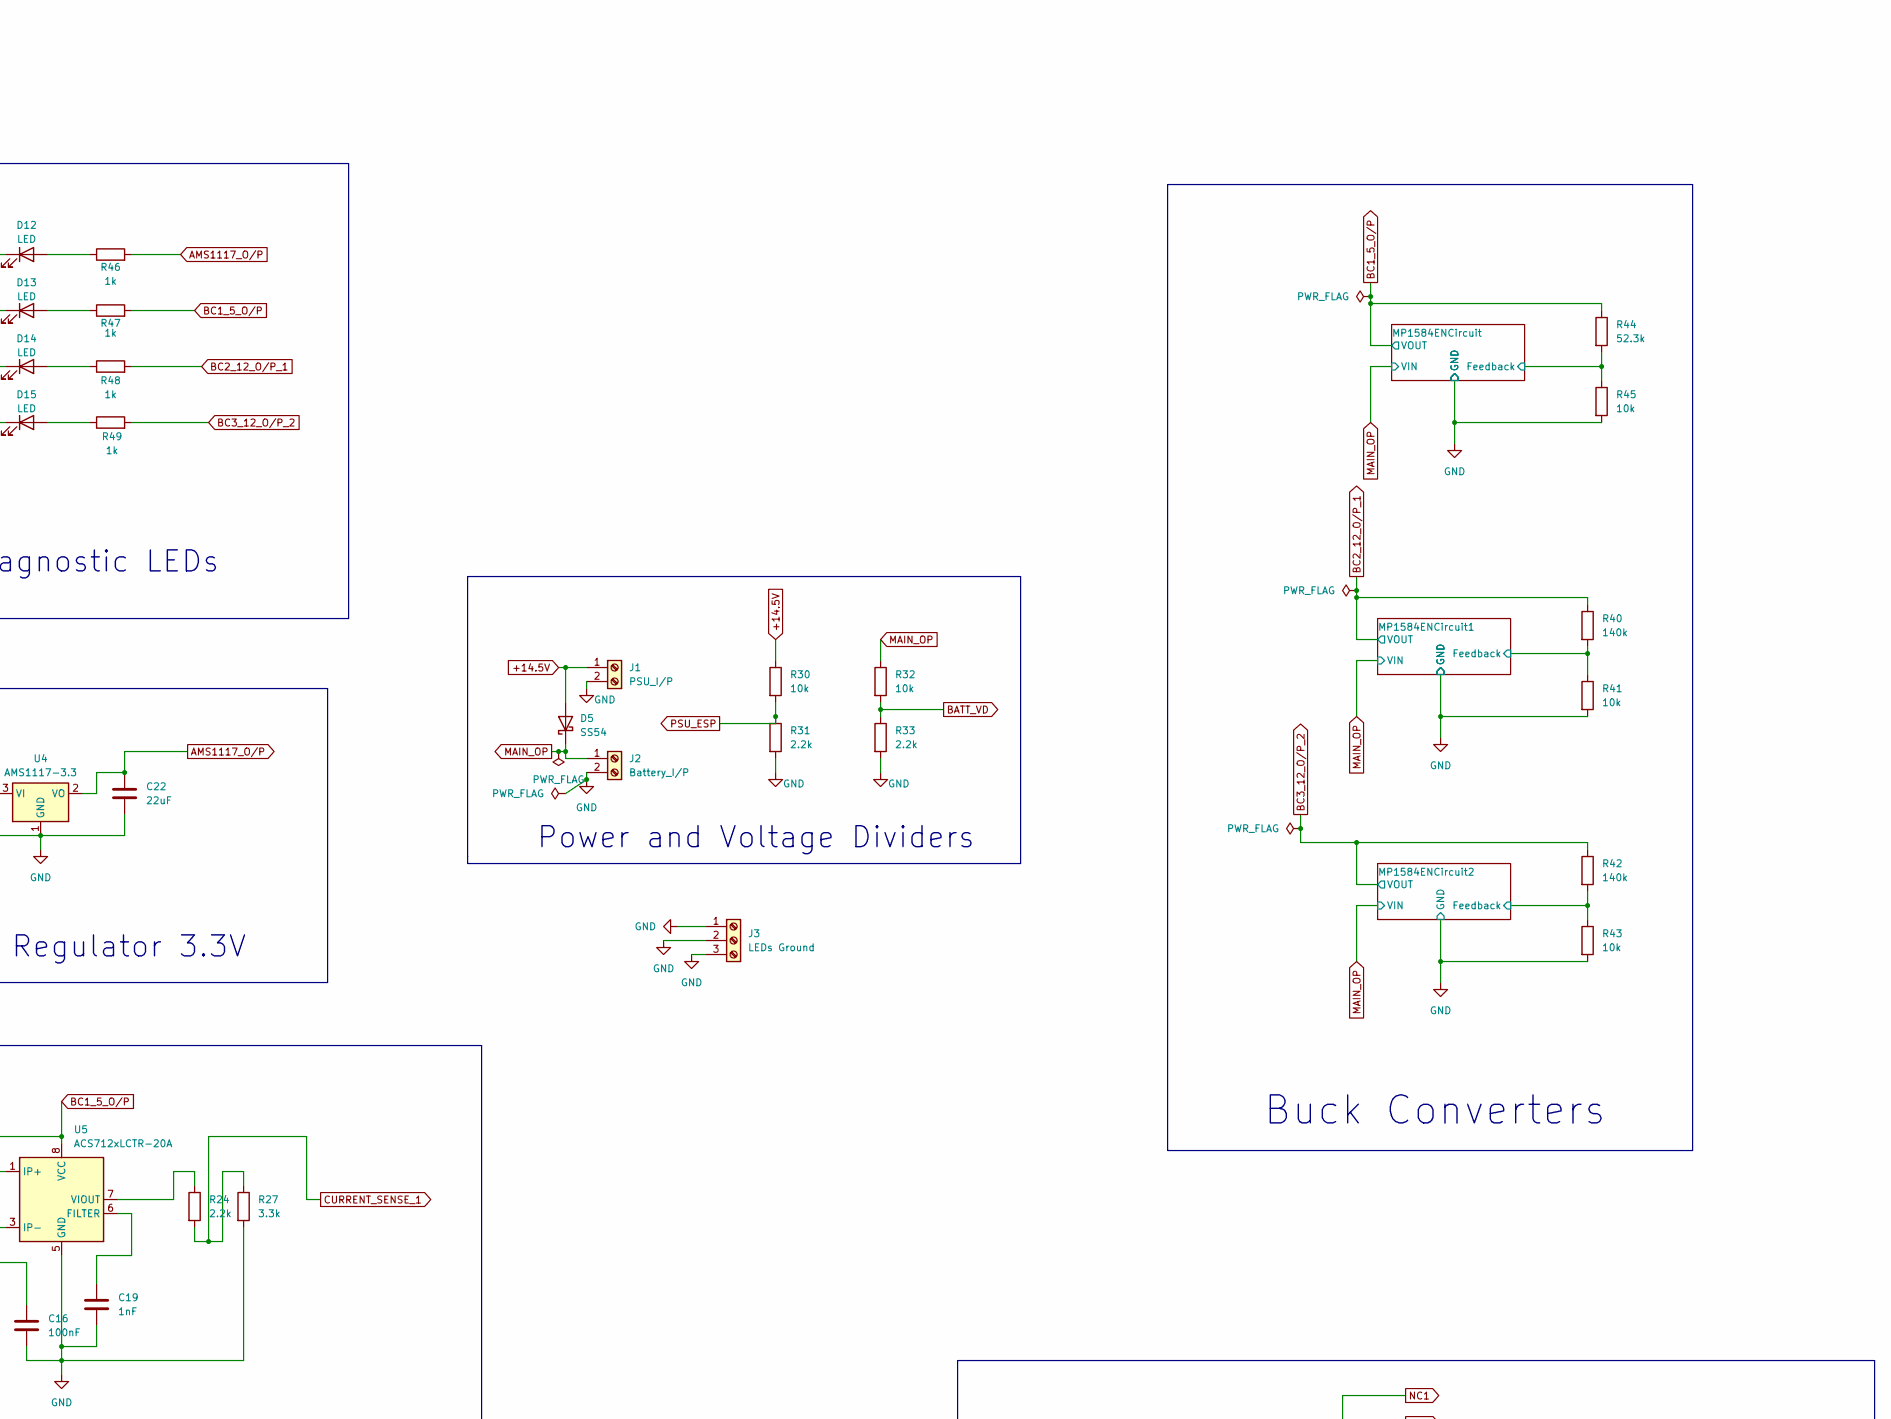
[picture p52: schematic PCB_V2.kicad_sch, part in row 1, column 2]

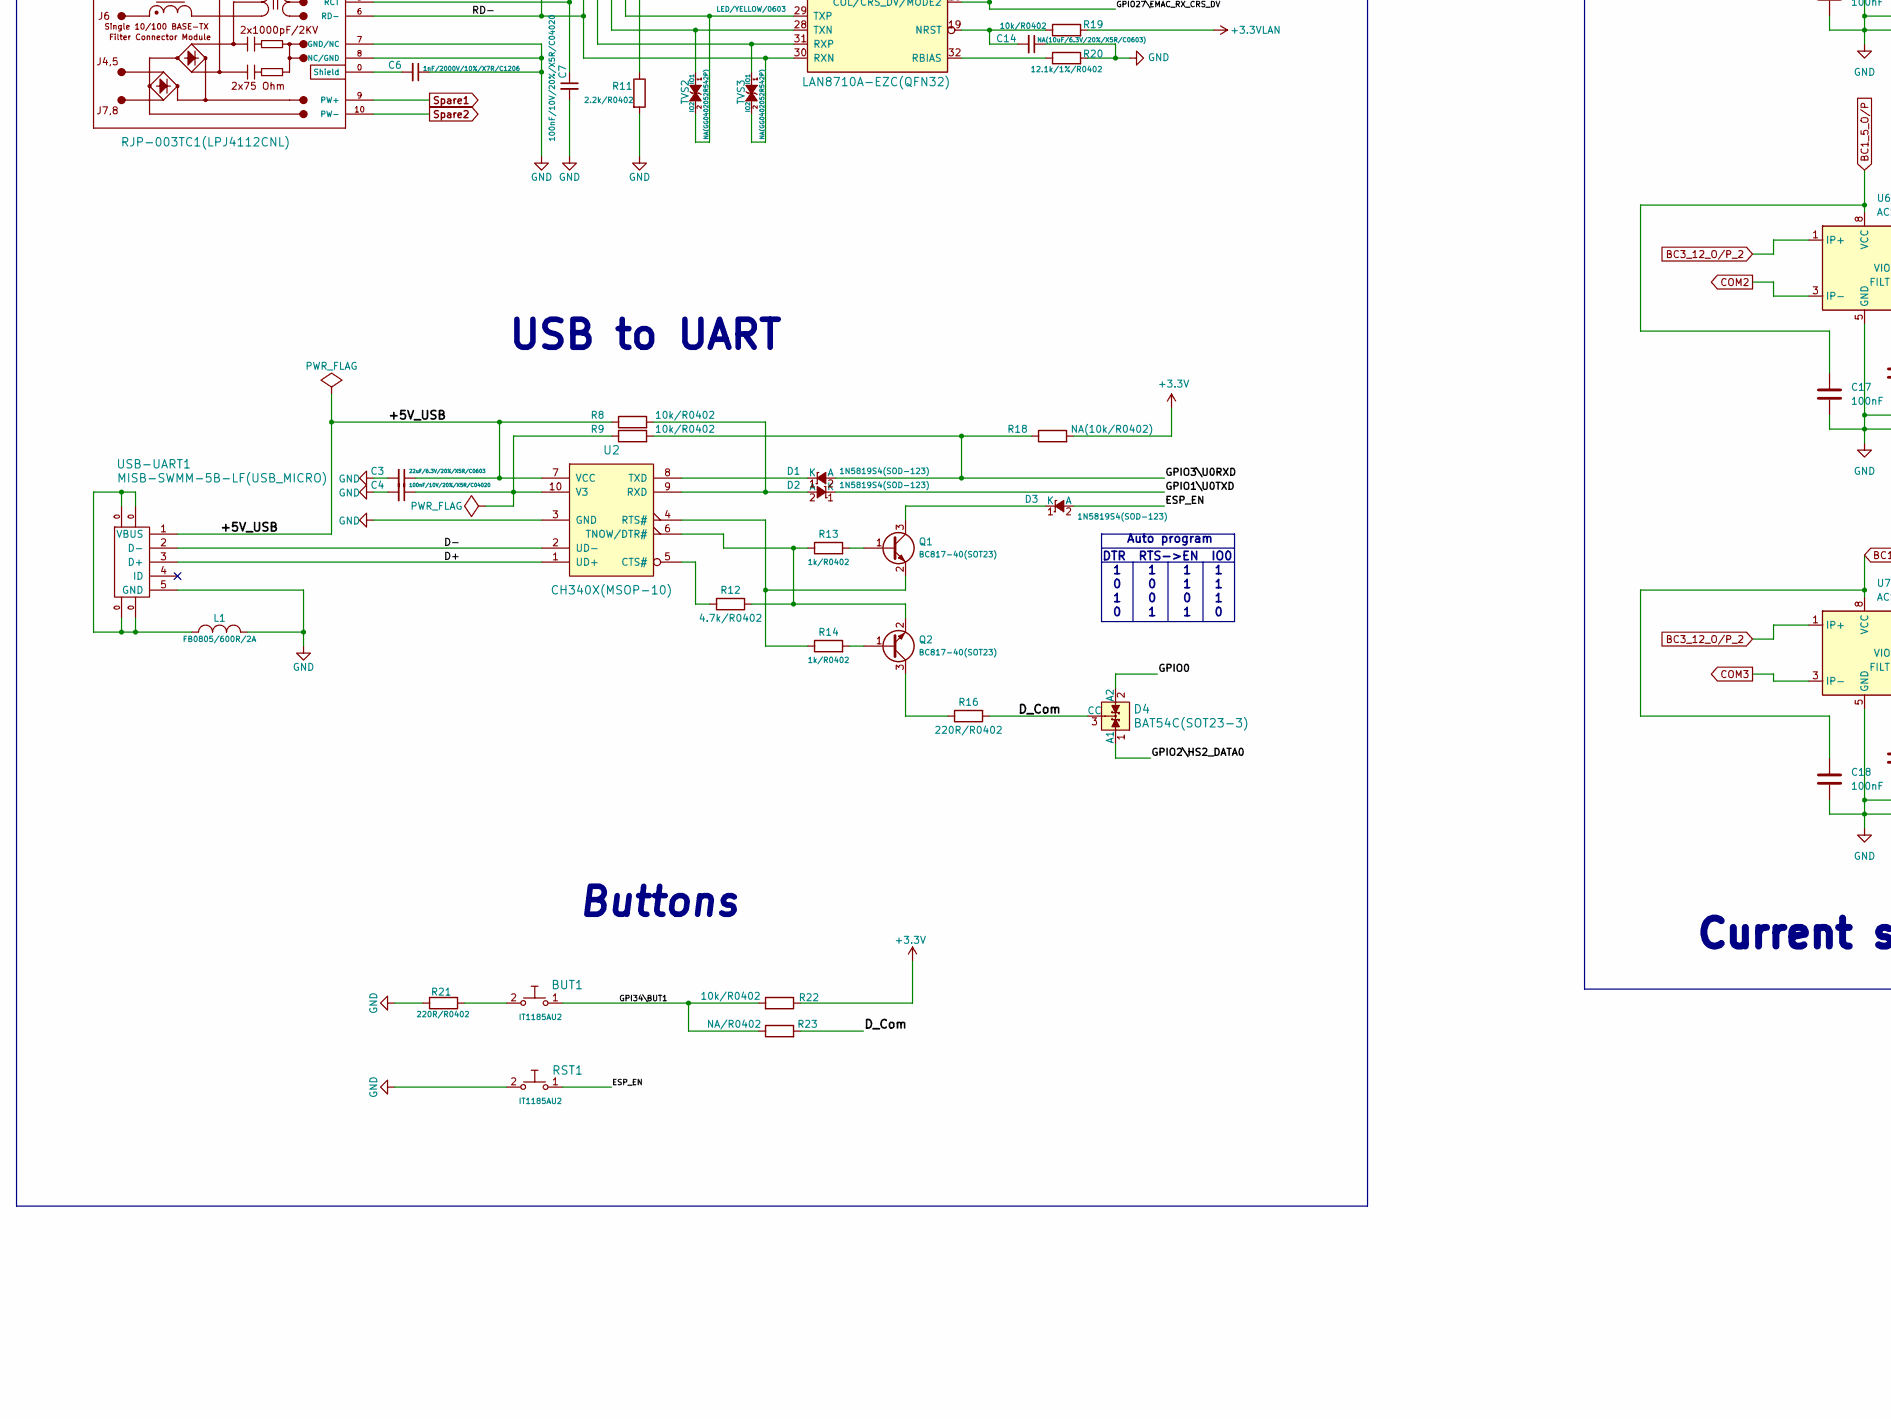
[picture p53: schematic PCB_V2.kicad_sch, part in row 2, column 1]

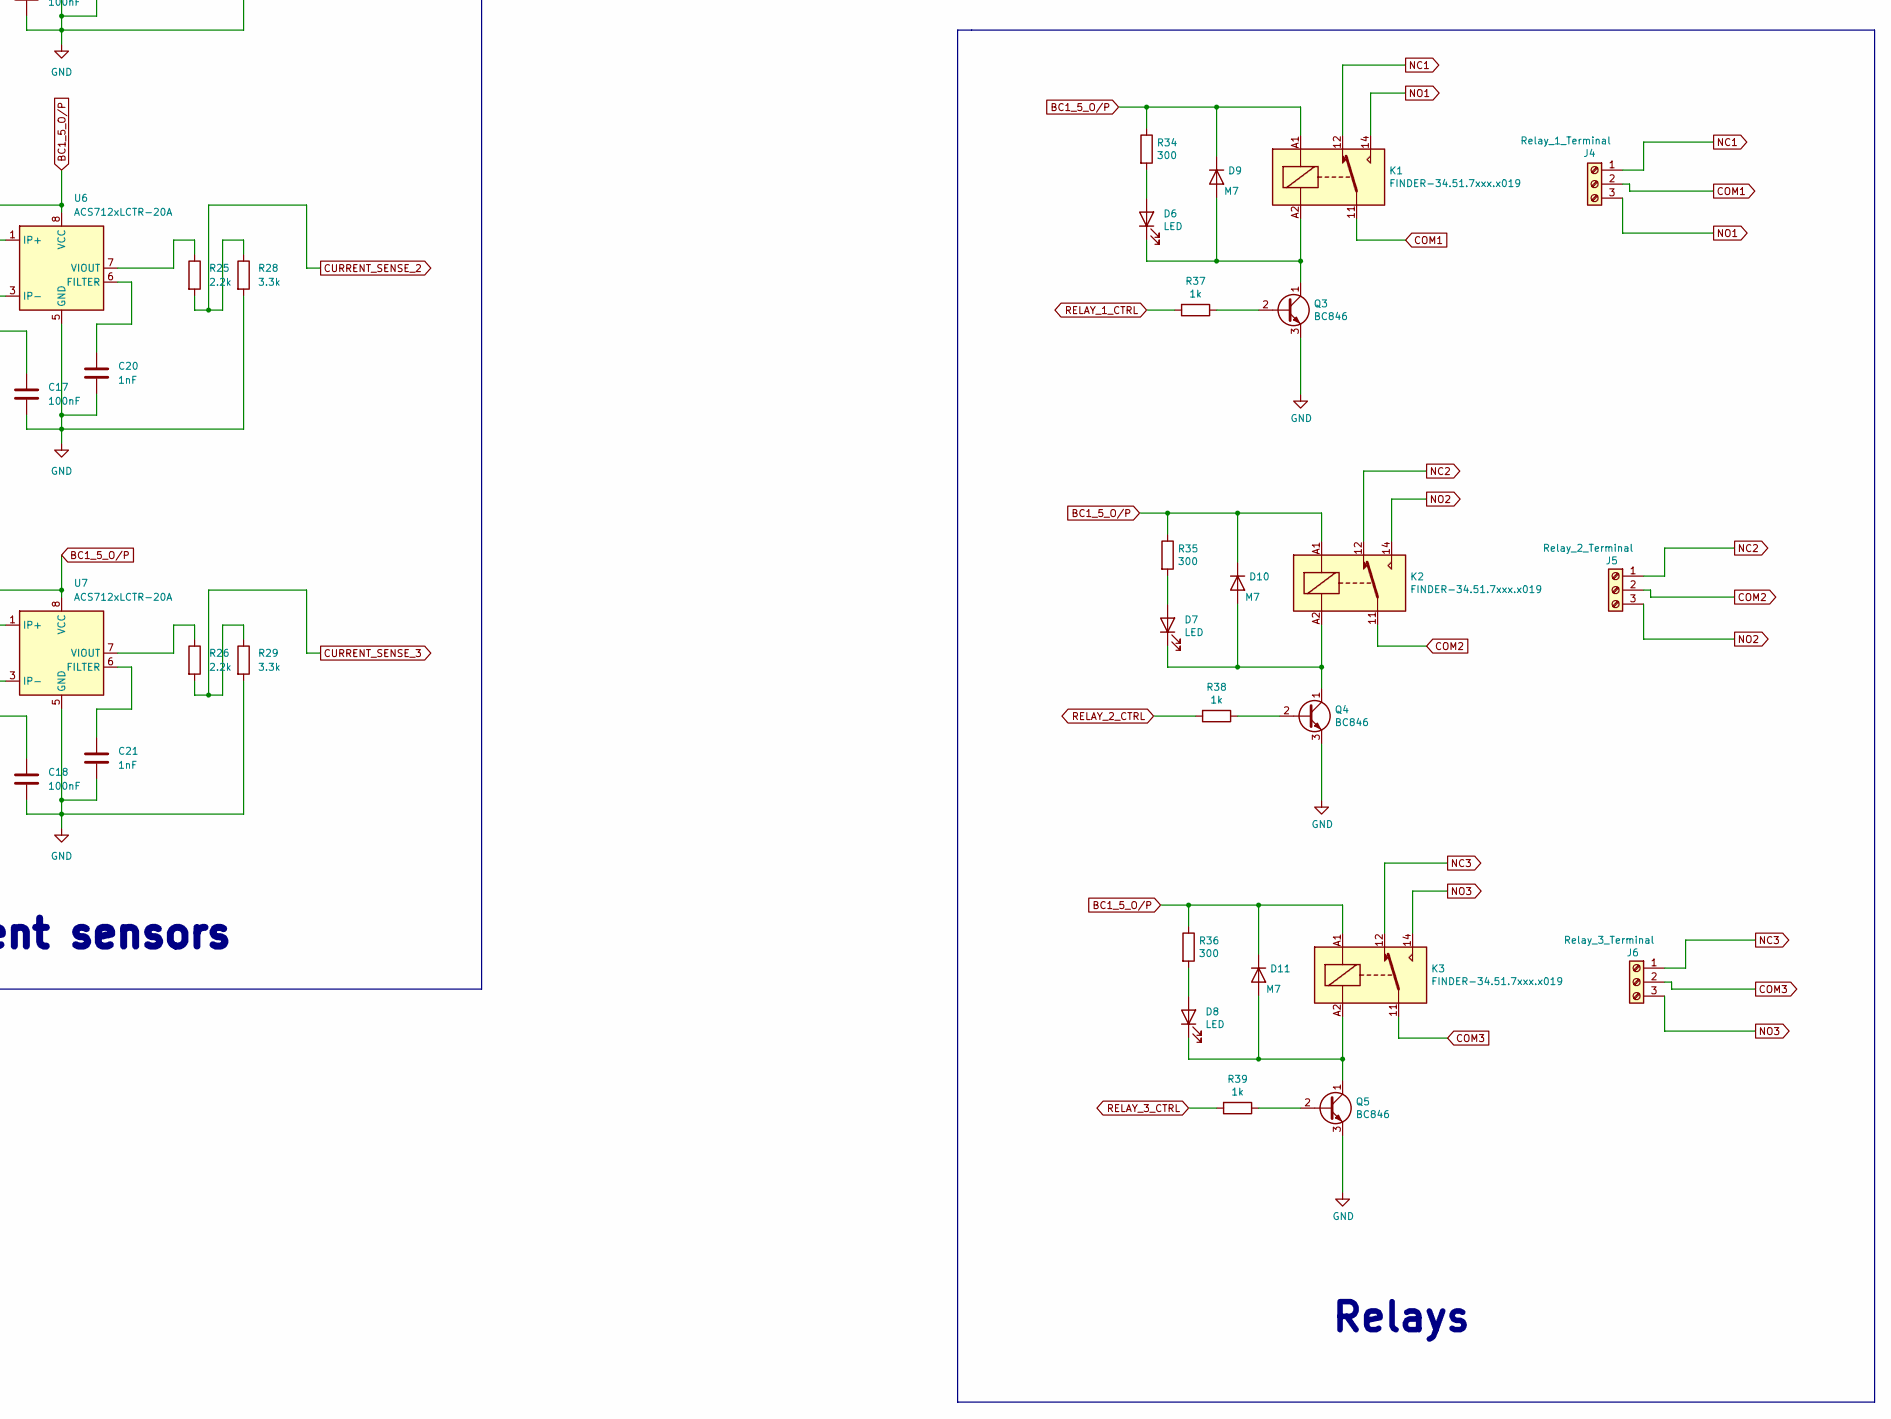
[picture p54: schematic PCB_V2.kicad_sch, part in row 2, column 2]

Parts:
ACT1: LED/YELLOW/0603; LED_0603_KA
BUT1: IT1185AU2; IT1185AU2_V2
C1, C3, C5, C9: 22uF/6.3V/20%/X5R/C0603; C_0603_5MIL_DWS
C2: 1uF/10V/20%/X5R/C0603; C_0603_5MIL_DWS
C4, C7, C8, C10, C11, C13: 100nF/10V/20%/X5R/C04020; C_0402_5MIL_DWS
C6: 1nF/2000V/10%/X7R/C1206; C_1206_5MIL_DWS_ISO
C12: 2.2uF/6.3V/10%/X5R/C0603; C_0603_5MIL_DWS
C14: NA(10uF/6.3V/20%/X5R/C0603); C_0603_5MIL_DWS
C15: 10uF; C_0805_2012Metric
C16, C17, C18: 100nF; C_0805_2012Metric
C19, C20, C21: 1nF; C_0805_2012Metric
C22: 22uF; C_0805_2012Metric
D1, D2, D3: 1N5819S4(SOD-123); SOD-123_1C-2A_KA
D4: BAT54C(SOT23-3); SOT23-3
D5: SS54; D_SMC
D6, D7, D8, D12, D13, D14, D15: LED; LED_0805_2012Metric
D9, D10, D11: M7; D_SMA
FET1: WPM2015-3/TR; SOT23
J1: PSU_I/P; TerminalBlock_Phoenix_MKDS-1,5-2-5.08_1x02_P5.08mm_Horizont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
J2: Battery_I/P; TerminalBlock_Phoenix_MKDS-1,5-2-5.08_1x02_P5.08mm_Horizont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
J3: LEDs Ground; TerminalBlock_Phoenix_MKDS-1,5-3_1x03_P5.00mm_Horizontal
J4: Relay_1_Terminal; TerminalBlock_Phoenix_MKDS-1,5-3-5.08_1x03_P5.08mm_Horizont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
J5: Relay_2_Terminal; TerminalBlock_Phoenix_MKDS-1,5-3-5.08_1x03_P5.08mm_Horizont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
J6: Relay_3_Terminal; TerminalBlock_Phoenix_MKDS-1,5-3-5.08_1x03_P5.08mm_Horizont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
K1, K2, K3: FINDER-34.51.7xxx.x019; Relay_SPDT_Finder_34.51_Horizontal
L1, L2: FB0805/600R/2A; L_0805_5MIL_DWS
LAN_CON1: RJP-003TC1(LPJ4112CNL)
LNK1: LED/GREEN/0603; LED_0603_KA
Q1, Q2: BC817-40(SOT23); SOT23
Q3, Q4, Q5: BC846; SOT-23
R1, R2, R8, R9, R19, R22: 10k/R0402; R_0402_5MIL_DWS
R3, R13, R14: 1k/R0402; R_0402_5MIL_DWS
R4, R5, R6, R7: 49.9R/1%/R0402; R_0402_5MIL_DWS
R10, R11, R17: 2.2k/R0402; R_0402_5MIL_DWS
R12: 4.7k/R0402; R_0402_5MIL_DWS
R15, R23: NA/R0402; R_0402_5MIL_DWS
R16, R21: 220R/R0402; R_0402_5MIL_DWS
R18: NA(10k/R0402); R_0402_5MIL_DWS
R20: 12.1k/1%/R0402; R_0402_5MIL_DWS
R24, R25, R26, R31, R33: 2.2k; R_0805_2012Metric
R27, R28, R29: 3.3k; R_0805_2012Metric
R30, R32: 10k; R_0805_2012Metric
R34, R35, R36: 300; R_0603_1608Metric
R37, R38, R39: 1k; R_0603_1608Metric
R40, R42: 140k; R_0603_1608Metric
R41, R43, R45: 10k; R_0603_1608Metric
R44: 52.3k; R_0603_1608Metric
R46, R47, R48, R49: 1k; R_0805_2012Metric
RM1, RM2: RA1206_(4X0603)_4B8_2.2k; R_MATRIX_4
RST1: IT1185AU2; IT1185AU2_V2
T1: LMUN2211LT1G(SOT-23); SOT23
TVS1: ESDS314DBVR(SOT-23-5); SOT-23-5
TVS2, TVS3: NA(GG0402052R542P); D_0402_5MIL_DWS
U1: ESP32-WROOM-32E-N4; ESP32-WROVER_MODULE
U2: CH340X(MSOP-10); MSOP-10_Pitch-0.5mm_3.00x3.00x1.00mm
U3: LAN8710A-EZC(QFN32); QFN32_EP(33)_5.00x5.00x0.90mm_Pitch_0.50mm
U4: AMS1117-3.3; SOT-223-3_TabPin2
U5, U6, U7: ACS712xLCTR-20A; SOIC-8_3.9x4.9mm_P1.27mm
USB-UART1: MISB-SWMM-5B-LF(USB_MICRO); USB-MICRO_MISB-SWMM-5B_LF

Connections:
+3.3V: C1.1, FET1.2, R1.1, R2.1, R15.2, R18.2, R22.1
+3.3VLAN: C5.1, C8.1, FET1.3, L2.1, R19.2, RM1.1.1, RM1.2.1, RM1.3.1, RM1.4.1, RM2.3.1, U3.12 (VDDIO)
+14.5V: D5.2 (A), J1.1, R30.1
/+5V_USB: C3.1, R8.1, U2.7 (VCC), USB-UART1.1 (VBUS)
/D+: U2.1 (UD+), USB-UART1.3 (D+)
/D-: U2.2 (UD-), USB-UART1.2 (D-)
/D_Com: D4.3 (CC), R16.2, R23.2
/ESP_EN: C2.1, D3.2 (A), R2.2, RST1.1, U1.3 (EN)
/GPI34\BUT1: BUT1.1, R22.2, R23.1, U1.6 (GPI34/ADC1_CH6/RTC_GPIO4)
/GPIO0: D4.2 (A2), R15.1, U1.25 (GPIO0/ADC2_CH1/TOUCH1/RTC_GPIO11/CLK_OU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)
/GPIO1\U0TXD: D2.1 (K), U1.35 (GPIO1/U0TXD/CLK_OUT3/EMAC_RXD2)
/GPIO2\HS2_DATA0: D4.1 (A1), U1.24 (GPIO2/ADC2_CH2/TOUCH2/RTC_GPIO12/HSPIWP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)
/GPIO3\U0RXD: D1.2 (A), R9.2, R18.1, U1.34 (GPIO3/U0RXD/CLK_OUT2)
/GPIO5\SPI_CS: U1.29 (GPIO5/VSPICS0/HS1_DATA6/EMAC_RX_CLK)
/GPIO12\PHY_PWR: T1.1 (B)
/GPIO14\HS2_CLK: U1.13 (GPIO14/ADC2_CH6/TOUCH6/RTC_GPIO16/MTMS/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)
/GPIO15\HS2_CMD: U1.23 (GPIO15/ADC2_CH3/TOUCH3/MTDO/HSPICS0/RTC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)
/GPIO16\I2C-SCL: U1.27 (NC(GPIO16/HS1_DATA4/U2RXD/EMAC_CLK_OUT))
/GPIO17\EMAC_CLK_OUT_180: U1.28 (NC(GPIO17/HS1_DATA5/U2TXD/EMAC_CLK_OUT_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), U3.5 (XTAL1/CLKIN)
/GPIO18\MDIO(RMII): RM1.4.2, U1.30 (GPIO18/VSPICLK/HS1_DATA7), U3.16 (MDIO)
/GPIO19\EMAC_TXD0(RMII): U1.31 (GPIO19/VSPIQ/U0CTS/EMAC_TXD0), U3.22 (TXD0)
/GPIO21\EMAC_TX_EN(RMII): U1.33 (GPIO21/VSPIHD/EMAC_TX_EN), U3.21 (TXEN)
/GPIO22\EMAC_TXD1(RMII): U1.36 (GPIO22/VSPIWP/U0RTS/EMAC_TXD1), U3.23 (TXD1)
/GPIO23\MDC(RMII): U1.37 (GPIO23/VSPID/HS1_STROBE), U3.17 (MDC)
/GPIO25\EMAC_RXD0(RMII): RM1.2.2, U1.10 (GPIO25/DAC_1/ADC2_CH8/RTC_GPIO6/EMAC_RX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), U3.11 (RXD0/MODE0)
/GPIO26\EMAC_RXD1(RMII): RM1.1.2, U1.11 (GPIO26/DAC_2/ADC2_CH9/RTC_GPIO7/EMAC_RX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), U3.10 (RXD1/MODE1)
/GPIO27\EMAC_RX_CRS_DV: RM2.3.2, U1.12 (GPIO27/ADC2_CH7/TOUCH7/RTC_GPIO17/EMAC_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), U3.15 (COL/CRS_DV/MODE2)
/MP1584ENCircuit1/Feedback: R40.2, R41.1; also elsewhere on the board
/MP1584ENCircuit2/Feedback: R42.2, R43.1; also elsewhere on the board
/MP1584ENCircuit/Feedback: R44.2, R45.1; also elsewhere on the board
/RD+: LAN_CON1.3 (RD+), R5.2, TVS1.1 (I/O1), TVS3.1 (IO1), U3.31 (RXP)
/RD-: LAN_CON1.6 (RD-), R4.2, TVS1.5 (I/O4), TVS3.2 (IO2), U3.30 (RXN)
/TD+: LAN_CON1.1 (TD+), R7.2, TVS1.3 (I/O2), TVS2.2 (IO2), U3.29 (TXP)
/TD-: LAN_CON1.2 (TD-), R6.2, TVS1.4 (I/O3), TVS2.1 (IO1), U3.28 (TXN)
AMS1117_O/P: C22.1, R46.2, U1.2 (VDD33(3V3)), U4.2 (VO)
BATT_VD: R32.2, R33.1, U1.5 (GPI39/SENSOR_VN/ADC1_CH3/RTC_GPIO3)
BC1_5_O/P: C15.1, C16.1, C17.1, C18.1, D9.1 (K), D10.1 (K), D11.1 (K), K1.A1, K2.A1, K3.A1, R34.1, R35.1, R36.1, R44.1, R47.2, U4.3 (VI), U5.8 (VCC), U6.8 (VCC), U7.8 (VCC); also elsewhere on the board
BC2_12_O/P_1: R40.1, R48.2, U5.1 (IP+), U5.2 (IP+); also elsewhere on the board
BC3_12_O/P_2: R42.1, R49.2, U6.1 (IP+), U6.2 (IP+), U7.1 (IP+), U7.2 (IP+); also elsewhere on the board
COM1: J4.2, K1.11, U5.3 (IP-), U5.4 (IP-)
COM2: J5.2, K2.11, U6.3 (IP-), U6.4 (IP-)
COM3: J6.2, K3.11, U7.3 (IP-), U7.4 (IP-)
CURRENT_SENSE_1: R24.2, R27.1, U1.9 (GPIO33/XTAL_32K_N/ADC1_CH5/TOUCH8/RTC_G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)
CURRENT_SENSE_2: R25.2, R28.1, U1.7 (GPI35/ADC1_CH7/RTC_GPIO5)
CURRENT_SENSE_3: R26.2, R29.1, U1.8 (GPIO32/XTAL_32K_P/ADC1_CH4/TOUCH9/RTC_G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)
GND: C2.2, C3.2, C4.2, C5.2, C6.1, C7.2, C8.2, C9.2, C10.2, C11.2, C12.2, C13.2, C14.1, C15.2, C16.2, C17.2, C18.2, C19.2, C20.2, C21.2, C22.2, D12.1 (K), D13.1 (K), D14.1 (K), D15.1 (K), J1.2, J2.2, J3.1, J3.2, J3.3, L1.2, LAN_CON1.7 (GND/NC), LAN_CON1.8 (NC/GND), Q3.3 (E), Q4.3 (E), Q5.3 (E), R11.2, R17.1, R20.2, R21.2, R27.2, R28.2, R29.2, R31.2, R33.2, R41.2, R43.2, R45.2, RM2.1.1, RM2.2.1, RST1.2, T1.2 (E), TVS1.2 (GND), U1.1 (GND), U1.15 (GND), U1.38 (GND), U1.39 (THERMAL_PAD), U2.3 (GND), U3.24 (TXD2), U3.25 (TXD3), U3.33 (GND), U4.1 (GND), U5.5 (GND), U6.5 (GND), U7.5 (GND), USB-UART1.5 (GND); also elsewhere on the board
MAIN_OP: D5.1 (K), J2.1, R32.1; also elsewhere on the board
NC1: J4.1, K1.12
NC2: J5.1, K2.12
NC3: J6.1, K3.12
NO1: J4.3, K1.14
NO2: J5.3, K2.14
NO3: J6.3, K3.14
unnamed: ACT1.2 (A), U3.3 (LED1/REGOFF)
unnamed: ACT1.1 (K), R11.1
unnamed: BUT1.2, R21.1
unnamed: C1.2, FET1.1, R1.2, R3.1
unnamed: D1.1 (K), U2.8 (TXD)
unnamed: D2.2 (A), R8.2, U2.9 (RXD)
unnamed: D3.1 (K), Q1.3 (C)
unnamed: D6.2 (A), R34.2
unnamed: D6.1 (K), D9.2 (A), K1.A2, Q3.1 (C)
unnamed: D7.2 (A), R35.2
unnamed: D8.2 (A), R36.2
unnamed: D7.1 (K), D10.2 (A), K2.A2, Q4.1 (C)
unnamed: D8.1 (K), D11.2 (A), K3.A2, Q5.1 (C)
unnamed: D12.2 (A), R46.1
unnamed: D13.2 (A), R47.1
unnamed: D14.2 (A), R48.1
unnamed: D15.2 (A), R49.1
unnamed: L1.1, USB-UART1.0
unnamed: C7.1, C9.1, C10.1, C11.1, L2.2, LAN_CON1.4 (TCT), LAN_CON1.5 (RCT), R4.1, R5.1, R6.1, R7.1, R10.1, U3.1 (VDD2A), U3.27 (VDD1A)
unnamed: C6.2, LAN_CON1.0 (Shield)
unnamed: LNK1.2 (A), R10.2
unnamed: LNK1.1 (K), U3.2 (LED2/NINTSEL)
unnamed: Q1.1 (B), R13.2
unnamed: Q1.2 (E), R14.1, U2.4 (RTS#)
unnamed: Q2.1 (B), R14.2
unnamed: Q2.3 (C), R16.1
unnamed: Q2.2 (E), R12.1, R13.1, U2.6 (TNOW/DTR#)
unnamed: Q3.2 (B), R37.1
unnamed: Q4.2 (B), R38.1
unnamed: Q5.2 (B), R39.1
unnamed: R3.2, T1.3 (C)
unnamed: R12.2, U2.5 (CTS#)
unnamed: C4.1, R9.1, U2.10 (V3)
unnamed: C14.2, R19.1, U3.19 (NRST)
unnamed: R20.1, U3.32 (RBIAS)
unnamed: RM2.1.2, U3.7 (RXCLK/PHYAD1)
unnamed: RM1.3.2, U3.9 (RXD2/RMIISEL)
unnamed: RM2.2.2, U3.8 (RXD3/PHYAD2)
unnamed: R17.2, U3.13 (RXER/RXD4/PHYAD0)
unnamed: C12.1, C13.1, U3.6 (VDDCR)
unnamed: C19.1, U5.6 (FILTER)
unnamed: R24.1, U5.7 (VIOUT)
unnamed: C20.1, U6.6 (FILTER)
unnamed: R25.1, U6.7 (VIOUT)
unnamed: C21.1, U7.6 (FILTER)
unnamed: R26.1, U7.7 (VIOUT)
PSU_ESP: R30.2, R31.1, U1.4 (GPI36/SENSOR_VP/ADC1_CH0/RTC_GPIO0)
RELAY_1_CTRL: R37.2, U1.26 (GPIO4/ADC2_CH0/TOUCH0/RTC_GPIO10/HSPIHD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)
RELAY_2_CTRL: R38.2, U1.16 (GPIO13/ADC2_CH4/TOUCH4/RTC_GPIO14/MTCK/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)
RELAY_3_CTRL: R39.2, U1.14 (GPIO12/ADC2_CH5/TOUCH5/RTC_GPIO15/MTDI/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)
Spare1: LAN_CON1.9 (PW+)
Spare2: LAN_CON1.10 (PW-)

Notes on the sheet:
DTR RTS->EN IO0
Relays
USB to UART
Ethernet
Auto program
ESP32 MODULE
Voltage Regulator 3.3V
or ESP32-WROVER-E
Current sensors
Power and Voltage Dividers
Buck Converters
Diagnostic LEDs
Buttons
In RMII Mode

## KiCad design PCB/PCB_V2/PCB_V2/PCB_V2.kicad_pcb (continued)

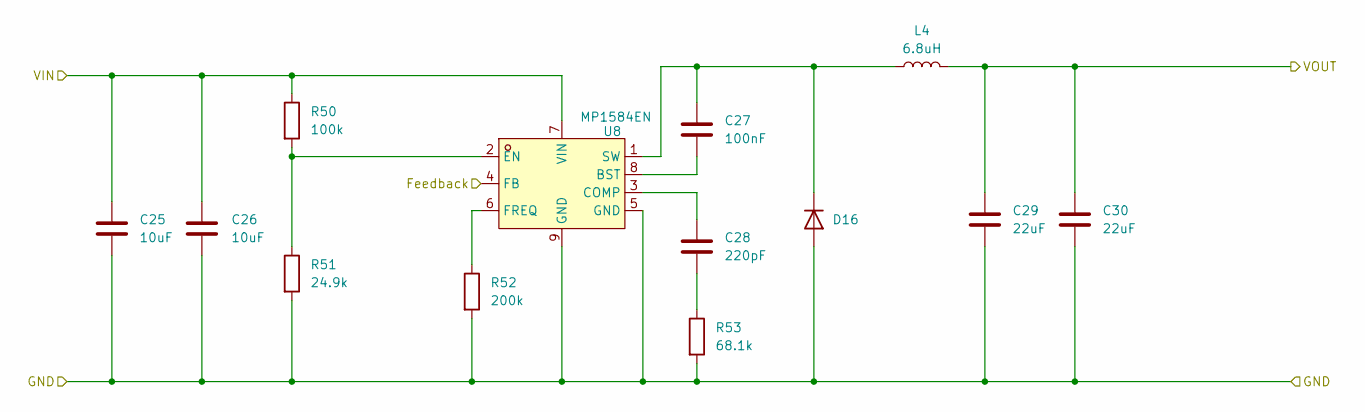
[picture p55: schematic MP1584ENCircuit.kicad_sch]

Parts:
C25, C26: 10uF; C_1206_3216Metric_Pad1.33x1.80mm_HandSolder
C27: 100nF; C_0603_1608Metric_Pad1.08x0.95mm_HandSolder
C28: 220pF; C_0603_1608Metric_Pad1.08x0.95mm_HandSolder
C29, C30: 22uF; C_1206_3216Metric_Pad1.33x1.80mm_HandSolder
D16: D_SMA_Handsoldering
L4: 6.8uH; L_6.3x6.3_H3
R50: 100k; R_0603_1608Metric_Pad0.98x0.95mm_HandSolder
R51: 24.9k; R_0603_1608Metric_Pad0.98x0.95mm_HandSolder
R52: 200k; R_0603_1608Metric_Pad0.98x0.95mm_HandSolder
R53: 68.1k; R_0603_1608Metric_Pad0.98x0.95mm_HandSolder
U8: MP1584EN; SOIC-8_L4.9-W3.9-P1.27-LS6.0-BL-EP3.3; MPN MP1584EN; LCSC Part C454188

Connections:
/MP1584ENCircuit/Feedback: U8.4 (FB); also elsewhere on the board
BC1_5_O/P: C29.1, C30.1, L4.2; also elsewhere on the board
GND: C25.2, C26.2, C29.2, C30.2, D16.2 (A), R51.2, R52.2, R53.2, U8.5 (GND), U8.9 (GND); also elsewhere on the board
MAIN_OP: C25.1, C26.1, R50.1, U8.7 (VIN); also elsewhere on the board
unnamed: C28.2, R53.1
unnamed: C27.1, D16.1 (K), L4.1, U8.1 (SW)
unnamed: C27.2, U8.8 (BST)
unnamed: C28.1, U8.3 (COMP)
unnamed: R50.2, R51.1, U8.2 (EN)
unnamed: R52.1, U8.6 (FREQ)

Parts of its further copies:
C31, C32, C37, C38: 10uF; C_1206_3216Metric_Pad1.33x1.80mm_HandSolder
C33, C39: 100nF; C_0603_1608Metric_Pad1.08x0.95mm_HandSolder
C34, C40: 220pF; C_0603_1608Metric_Pad1.08x0.95mm_HandSolder
C35, C36, C41, C42: 22uF; C_1206_3216Metric_Pad1.33x1.80mm_HandSolder
L5, L6: 6.8uH; L_6.3x6.3_H3
R54, R58: 100k; R_0603_1608Metric_Pad0.98x0.95mm_HandSolder
R55, R59: 24.9k; R_0603_1608Metric_Pad0.98x0.95mm_HandSolder
R56, R60: 200k; R_0603_1608Metric_Pad0.98x0.95mm_HandSolder
R57, R61: 68.1k; R_0603_1608Metric_Pad0.98x0.95mm_HandSolder
U9, U10: MP1584EN; SOIC-8_L4.9-W3.9-P1.27-LS6.0-BL-EP3.3; MPN MP1584EN; LCSC Part C454188

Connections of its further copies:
/MP1584ENCircuit1/Feedback: U9.4 (FB); also elsewhere on the board
/MP1584ENCircuit2/Feedback: U10.4 (FB); also elsewhere on the board
BC2_12_O/P_1: C35.1, C36.1, L5.2; also elsewhere on the board
BC3_12_O/P_2: C41.1, C42.1, L6.2; also elsewhere on the board
GND: C31.2, C32.2, C35.2, C36.2, C37.2, C38.2, C41.2, C42.2, R55.2, R56.2, R57.2, R59.2, R60.2, R61.2, U9.5 (GND), U9.9 (GND), U10.5 (GND), U10.9 (GND); also elsewhere on the board
MAIN_OP: C31.1, C32.1, C37.1, C38.1, R54.1, R58.1, U9.7 (VIN), U10.7 (VIN); also elsewhere on the board
unnamed: C34.2, R57.1
unnamed: C40.2, R61.1
unnamed 74: C33.1, L5.1, U9.1 (SW); also elsewhere on the board
unnamed 75: C39.1, L6.1, U10.1 (SW); also elsewhere on the board
unnamed: C33.2, U9.8 (BST)
unnamed: C34.1, U9.3 (COMP)
unnamed: R54.2, R55.1, U9.2 (EN)
unnamed: R56.1, U9.6 (FREQ)
unnamed: C39.2, U10.8 (BST)
unnamed: C40.1, U10.3 (COMP)
unnamed: R58.2, R59.1, U10.2 (EN)
unnamed: R60.1, U10.6 (FREQ)

Board: 2 copper layers, 161 parts (0 on the bottom side), 116 nets, no tracks yet.

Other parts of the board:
D17, D18: D_SMA_Handsoldering

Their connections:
GND: D17.2 (A), D18.2 (A); also elsewhere on the board
unnamed 74: D17.1 (K); also elsewhere on the board
unnamed 75: D18.1 (K); also elsewhere on the board

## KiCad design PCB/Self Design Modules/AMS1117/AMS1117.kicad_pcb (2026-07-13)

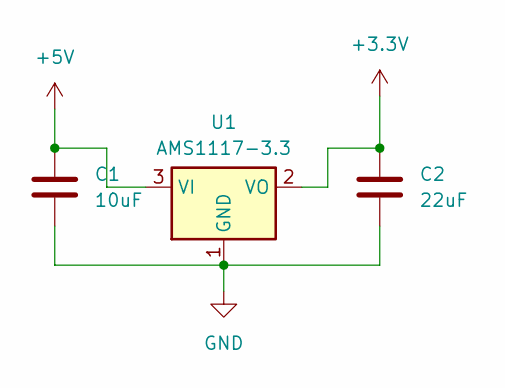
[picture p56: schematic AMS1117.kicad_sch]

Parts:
C1: 10uF; C_0805_2012Metric
C2: 22uF; C_0805_2012Metric
U1: AMS1117-3.3; SOT-223-3_TabPin2

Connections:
+3.3V: C2.1, U1.2 (VO)
+5V: C1.1, U1.3 (VI)
GND: C1.2, C2.2, U1.1 (GND)

Board: 2 copper layers, 3 parts (0 on the bottom side), 3 nets, no tracks yet.

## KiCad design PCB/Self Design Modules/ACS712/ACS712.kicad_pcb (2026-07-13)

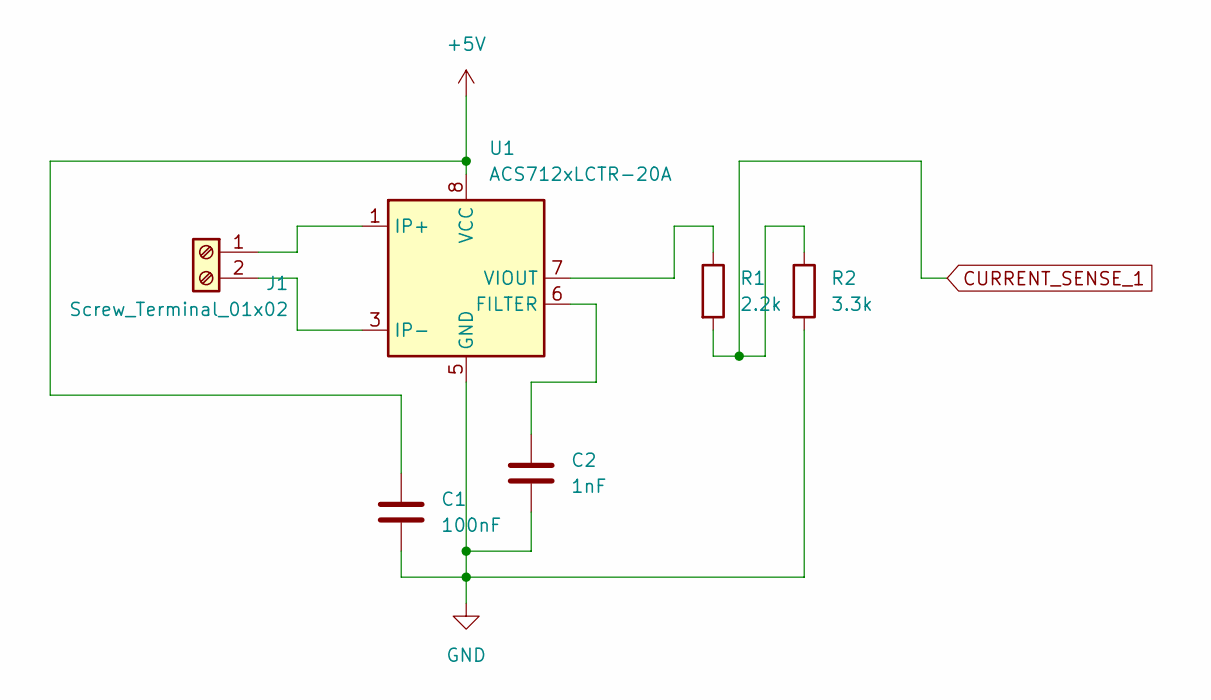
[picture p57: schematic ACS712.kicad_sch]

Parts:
C1: 100nF; C_0805_2012Metric
C2: 1nF; C_0805_2012Metric
J1: Screw_Terminal_01x02; TerminalBlock_Phoenix_MKDS-1,5-2-5.08_1x02_P5.08mm_Horizont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
R1: 2.2k; R_0805_2012Metric
R2: 3.3k; R_0805_2012Metric
U1: ACS712xLCTR-20A; SOIC-8_3.9x4.9mm_P1.27mm

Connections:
+5V: C1.1, U1.8 (VCC)
CURRENT_SENSE_1: R1.2, R2.1
GND: C1.2, C2.2, R2.2, U1.5 (GND)
unnamed: J1.1, U1.1 (IP+), U1.2 (IP+)
unnamed: J1.2, U1.3 (IP-), U1.4 (IP-)
unnamed: C2.1, U1.6 (FILTER)
unnamed: R1.1, U1.7 (VIOUT)

Board: 2 copper layers, 6 parts (0 on the bottom side), 7 nets, no tracks yet.

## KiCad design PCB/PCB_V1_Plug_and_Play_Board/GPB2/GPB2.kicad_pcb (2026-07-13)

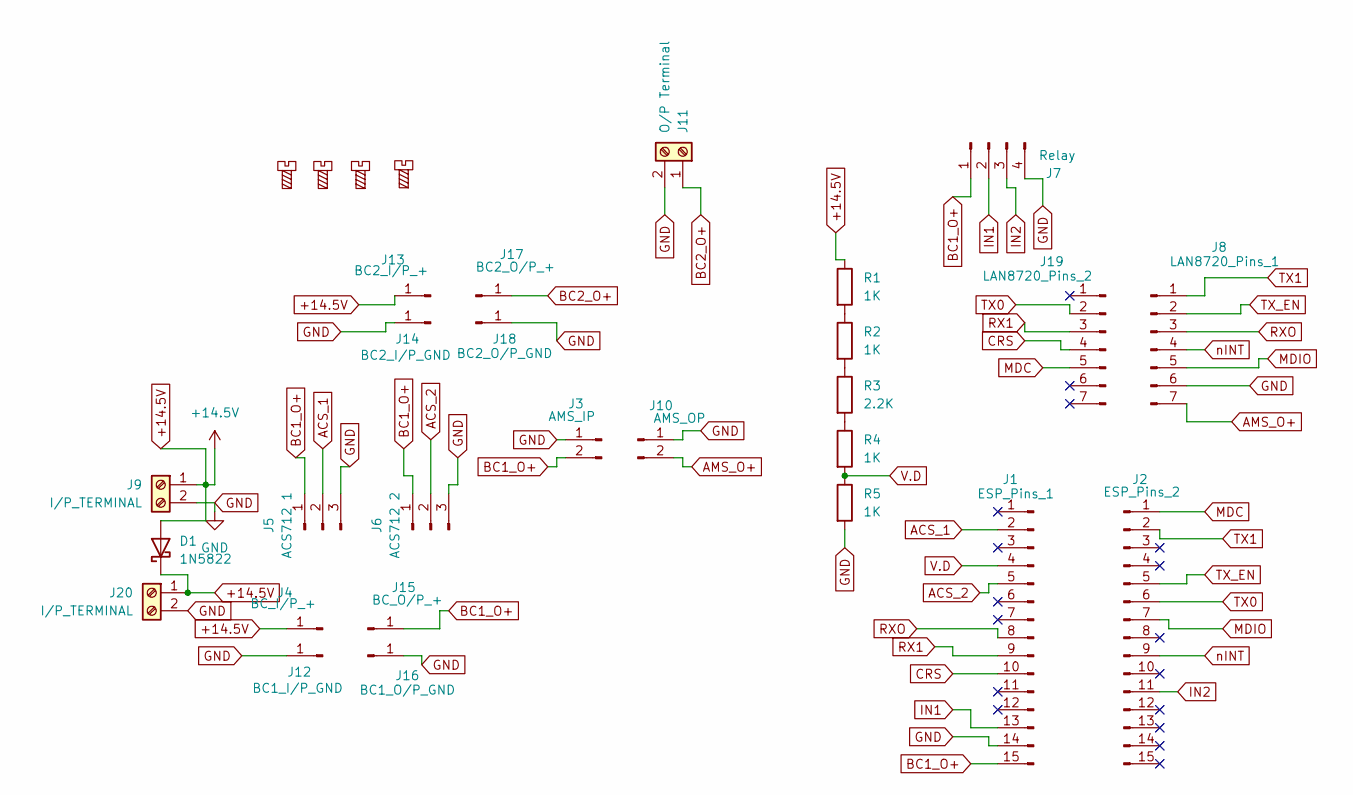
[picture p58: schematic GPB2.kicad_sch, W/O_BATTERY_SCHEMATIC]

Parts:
D1: 1N5822; D_DO-201AD_P15.24mm_Horizontal
H1, H2, H3, H4: MountingScrew; MountingHole_3.2mm_M3
J1: ESP_Pins_1; PinSocket_1x15_P2.54mm_Vertical
J2: ESP_Pins_2; PinSocket_1x15_P2.54mm_Vertical
J3: AMS_IP; PinSocket_1x02_P2.54mm_Vertical
J4: BC_I/P_+; PinSocket_1x01_P2.54mm_Vertical
J5: ACS712 1; PinSocket_1x03_P2.54mm_Vertical
J6: ACS712 2; PinSocket_1x03_P2.54mm_Vertical
J7: Relay; PinHeader_1x04_P2.54mm_Vertical
J8: LAN8720_Pins_1; PinSocket_1x07_P2.54mm_Vertical
J9, J20: I/P_TERMINAL; TerminalBlock_Phoenix_MKDS-1,5-2-5.08_1x02_P5.08mm_Horizont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
J10: AMS_OP; PinSocket_1x02_P2.54mm_Vertical
J11: O/P Terminal; TerminalBlock_Phoenix_MKDS-1,5-2-5.08_1x02_P5.08mm_Horizont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
J12: BC1_I/P_GND; PinSocket_1x01_P2.54mm_Vertical
J13: BC2_I/P_+; PinSocket_1x01_P2.54mm_Vertical
J14: BC2_I/P_GND; PinSocket_1x01_P2.54mm_Vertical
J15: BC_O/P_+; PinSocket_1x01_P2.54mm_Vertical
J16: BC1_O/P_GND; PinSocket_1x01_P2.54mm_Vertical
J17: BC2_O/P_+; PinSocket_1x01_P2.54mm_Vertical
J18: BC2_O/P_GND; PinSocket_1x01_P2.54mm_Vertical
J19: LAN8720_Pins_2; PinSocket_1x07_P2.54mm_Vertical
R1, R2, R4, R5: 1K; R_Axial_DIN0207_L6.3mm_D2.5mm_P10.16mm_Horizontal
R3: 2.2K; R_Axial_DIN0309_L9.0mm_D3.2mm_P12.70mm_Horizontal

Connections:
+14.5V: D1.1 (K), D1.2 (A), J4.1, J9.1 (V+), J13.1, J20.1 (V+), R1.1
ACS_1: J1.2 (Vp), J5.2 (OUT)
ACS_2: J1.5 (D35), J6.2 (OUT)
AMS_O+: J8.7, J10.2 (GND)
BC1_O+: J1.15 (VIN), J3.2 (GND), J5.1 (VCC), J6.1 (VCC), J7.1 (VCC), J15.1
BC2_O+: J11.1 (V+), J17.1
CRS: J1.10 (D27), J19.4
GND: J1.14 (GND), J3.1 (I+), J5.3 (GND), J6.3 (GND), J7.4 (GND), J8.6, J9.2 (V-), J10.1 (O+), J11.2 (V-), J12.1, J14.1, J16.1, J18.1, J20.2 (V-), R5.2
IN1: J1.13 (D13), J7.2 (IN2)
IN2: J2.11 (D4), J7.3 (IN1)
MDC: J2.1 (D23), J19.5
MDIO: J2.7 (D18), J8.5
unnamed: R1.2, R2.1
unnamed: R2.2, R3.1
unnamed: R3.2, R4.1
RX1: J1.9 (D26), J19.3
RXO: J1.8 (D25), J8.3
TX0: J2.6 (D19), J19.2
TX1: J2.2 (D22), J8.1
TX_EN: J2.5 (D21), J8.2
V.D: J1.4 (D34), R4.2, R5.1
nINT: J2.9 (TX2), J8.4

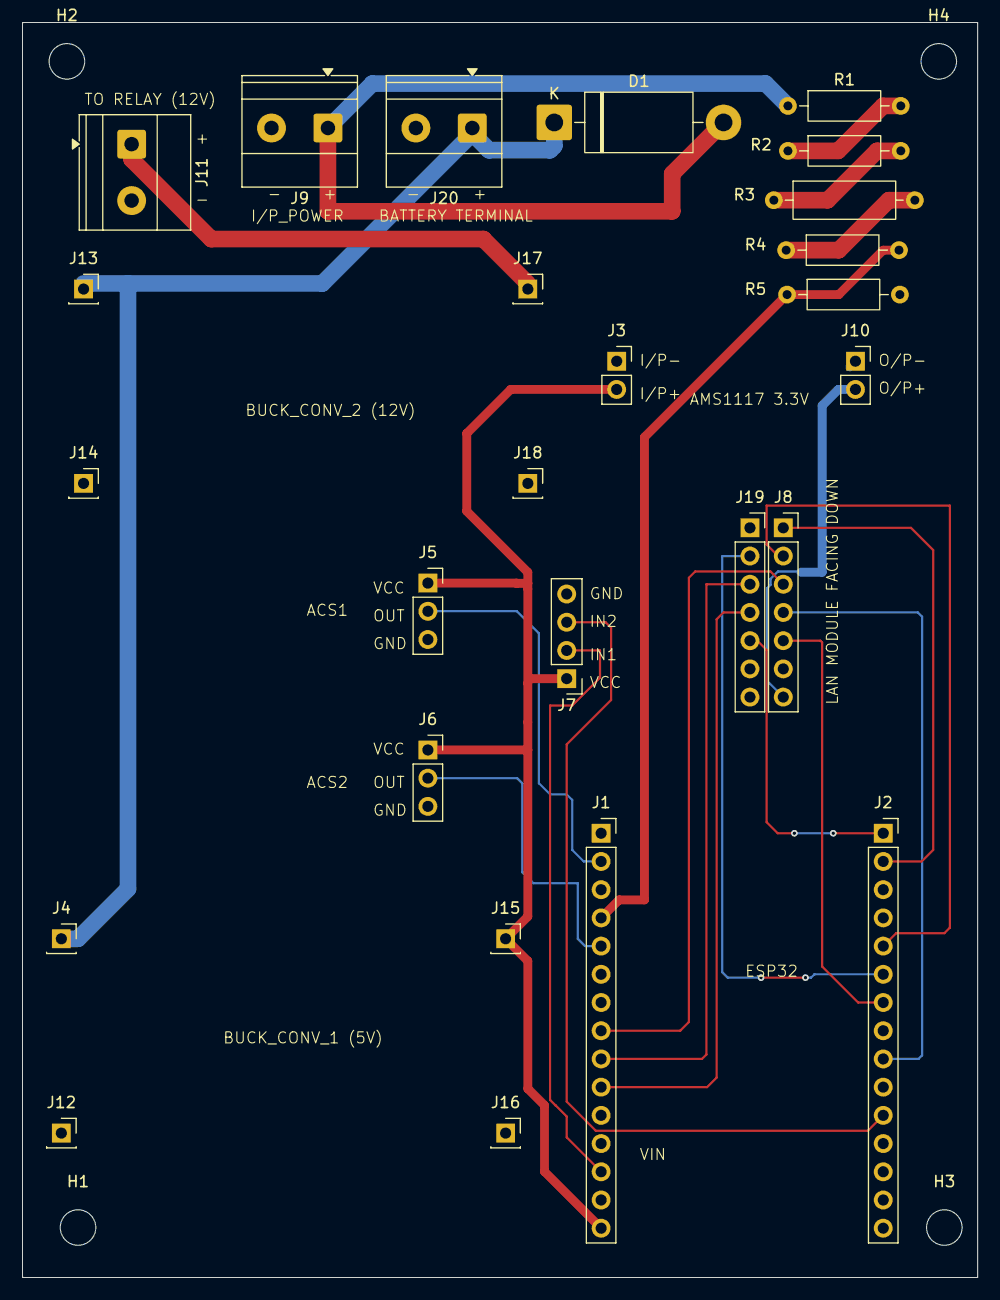
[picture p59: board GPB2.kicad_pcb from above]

Board: 2 copper layers, 86.0 x 113.0 mm, 30 parts (0 on the bottom side), 22 nets.

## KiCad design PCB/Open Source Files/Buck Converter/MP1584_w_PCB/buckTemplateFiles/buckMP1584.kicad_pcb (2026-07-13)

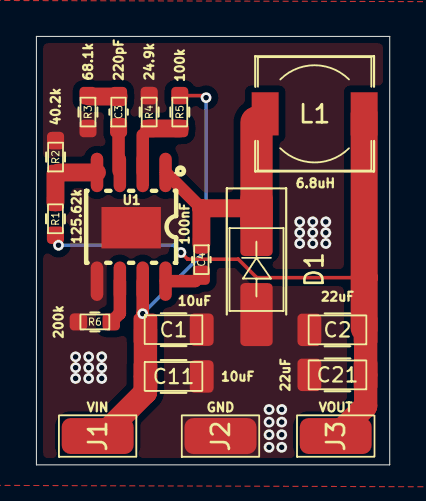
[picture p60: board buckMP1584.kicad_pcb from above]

Board: 2 copper layers, 19.6 x 23.8 mm, 18 parts (0 on the bottom side), 10 nets.

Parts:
C1, C11: 10uF; C_1206_3216Metric_Pad1.33x1.80mm_HandSolder
C2, C21: 22uF; C_1206_3216Metric_Pad1.33x1.80mm_HandSolder
C3: 220pF; C_0603_1608Metric_Pad1.08x0.95mm_HandSolder
C4: 100nF; C_0603_1608Metric_Pad1.08x0.95mm_HandSolder
D1: D_SMA_Handsoldering
J1: VIN; SolderWirePad_1x01_SMD_2x4mm
J2: GND; SolderWirePad_1x01_SMD_2x4mm
J3: VOUT; SolderWirePad_1x01_SMD_2x4mm
L1: 6.8uH; L_6.3x6.3_H3
R1: 125.62k; R_0603_1608Metric_Pad0.98x0.95mm_HandSolder
R2: 40.2k; R_0603_1608Metric_Pad0.98x0.95mm_HandSolder
R3: 68.1k; R_0603_1608Metric_Pad0.98x0.95mm_HandSolder
R4: 24.9k; R_0603_1608Metric_Pad0.98x0.95mm_HandSolder
R5: 100k; R_0603_1608Metric_Pad0.98x0.95mm_HandSolder
R6: 200k; R_0603_1608Metric_Pad0.98x0.95mm_HandSolder
U1: MP1584EN; SOIC-8_L4.9-W3.9-P1.27-LS6.0-BL-EP3.3

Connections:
+3.3V: C2.1, C21.1, J3.1 (Pin_1_1), L1.2, R1.1
/MP1584EN Buck module/Feedback: R1.2, R2.1, U1.4 (FB)
/VIN: C1.1, C11.1, J1.1 (Pin_1_1), R5.1, U1.7 (VIN)
GND: C1.2, C2.2, C11.2, C21.2, D1.2 (A), J2.1 (Pin_1_1), R2.2, R3.2, R4.2, R6.2, U1.5 (GND), U1.9 (GND)
unnamed: C3.2, R3.1
unnamed: C4.1, D1.1 (K), L1.1, U1.1 (SW)
unnamed: C4.2, U1.8 (BST)
unnamed: C3.1, U1.3 (COMP)
unnamed: R4.1, R5.2, U1.2 (EN)
unnamed: R6.1, U1.6 (FREQ)

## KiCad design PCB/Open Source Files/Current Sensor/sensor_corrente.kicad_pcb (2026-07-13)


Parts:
C1: 100nF; C_0805_2012Metric
C2: 1nF; C_0805_2012Metric
D1: LED; LED_0805_2012Metric
J1: Screw_Terminal_01x02; TerminalBlock_Phoenix_MKDS-1,5-2-5.08_1x02_P5.08mm_Horizont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
J2: 640456-3; PinHeader_1x3_P2.54_Drill1.1mm; MPN 640456-3; Digi-Key_PN A19470-ND
R1: 1k_omhs; R_0805_2012Metric
U2: ACS712xLCTR-05B; SOIC-8_3.9x4.9mm_P1.27mm

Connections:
+5V: C1.2, J2.3, R1.1, U2.8 (VCC)
/IP+: J1.1, U2.1 (IP+), U2.2 (IP+)
/IP-: J1.2, U2.3 (IP-), U2.4 (IP-)
GND: C1.1, C2.2, D1.1 (K), J2.1, U2.5 (GND)
unnamed: D1.2 (A), R1.2
unnamed: C2.1, U2.6 (FILTER)
unnamed: J2.2, U2.7 (VIOUT)


Board: 2 copper layers, 32.5 x 12.0 mm, 7 parts (0 on the bottom side), 7 nets.

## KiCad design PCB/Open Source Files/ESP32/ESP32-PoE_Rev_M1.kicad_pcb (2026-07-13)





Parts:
ACT1: LED/YELLOW/0603; LED_0603_KA
BAT1: DW02S; LIPO_BAT_VERTICAL_DW02S
BAT_SENS_E1: Opened; SJ_1_SMALLER
BUT1: IT1185AU2; IT1185AU2_V2
C1, C6, C7, C9, C10, C13, C22: 22uF/6.3V/20%/X5R/C0603; C_0603_5MIL_DWS
C2: 1nF/2000V/10%/X7R/C1206; C_1206_5MIL_DWS_ISO
C3: 47uF/6.3V/20%/X5R/C0805; C_0805_5MIL_DWS
C8, C11, C14, C15, C16, C18: 100nF/10V/20%/X5R/C04020; C_0402_5MIL_DWS
C12, C24: 100nF/100V/10%/X7R/C0603; C_0603_5MIL_DWS
C17: 2.2uF/6.3V/10%/X5R/C0603; C_0603_5MIL_DWS
C19: 1nF/50V/10%/X7R/C0402; C_0402_5MIL_DWS
C20: 1uF/10V/20%/X5R/C0603; C_0603_5MIL_DWS
C21: NA(10uF/6.3V/20%/X5R/C0603); C_0603_5MIL_DWS
C23: 12pF/50V/5%/COG/C0402; C_0402_5MIL_DWS
C25: 470uF/10V/20%/Low_ESR/RM2.5/6.0x11mm; CPOL-RM2.5mm_6.3x11mm_PTH
C26: NA(220pF/100V/C0603); C_0603_5MIL_DWS
C27: 15uF/100V/20%/RM2.5/6.3x11mm(Farnell:1281844); CPOL-RM2.5mm_6.3x11mm_PTH
C28: NA(100nF/10V/20%/X5R/C04020); C_0402_5MIL_DWS
C36: NA(120pF/50V/5%/C0G/C0402); C_0402_5MIL_DWS; not fitted
CHRG1: LED/YELLOW/0603; LED_0603_KA
Class4_EN1: Closed; SJ_Closed
D1, D3: 1N5822/SS34/SMA; SMA-KA
D2: BAT54C(SOT23-3); SOT23-3
D4, D6, D7, D9: 1N5819S4(SOD-123); SOD-123_1C-2A_KA
D5: SS510/100V/5A/0.85V/DO214AB(SMC); DO214AB(SMC)_1(K)-2(A)
D8: SMAJ58A/SMA; SMA-KA
EXT1, EXT2: NS(HN1x10); HN1x10
FET1, FET2, FET3: WPM2015-3/TR; SOT23
FID1, FID3, FID4, FID6: Fiducial; Fiducial1x3
FID2, FID5: Fiducial; Fiducial1x3_Paste
L1, L3, L5: FB0805/600R/2A; L_0805_5MIL_DWS
L2: 1.0uH/4.2A/DCR=35mR/20%/2.00x1.60x1.00mm/L2016(PI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; L_2016_MM
L4: 33uH/2.1A/DCR=0.1R/20%/DBS135(PD3316MT330); DBS135
LAN_CON1: RJP-003TC1(LPJ4112CNL)
LNK1: LED/GREEN/0603; LED_0603_KA
MH1, MH2, MH3: Mounting_Hole_NPTH; NPTH_2.2mm
MICRO_SD1: TFC-9P-1.7H(ATFFS150A01BR016); uSD(TFC-9P-1.xH(ATFFS150A01BR016))
PWR1: LED/RED/0603; LED_0603_KA
Q2, Q3: BC817-40(SOT23); SOT23
R1, R2, R6, R18, R19, R25, R32, R36, R37, R39, R48: 10k/R0402; R_0402_5MIL_DWS
R3, R20, R21: 1k/R0402; R_0402_5MIL_DWS
R4: 47k/R0402; R_0402_5MIL_DWS
R5, R8, R14, R15, R31, R35, R41: 2.2k/R0402; R_0402_5MIL_DWS
R7, R42: 9.1k/R2512; R_2512_MM_DWS
R9: 100k/R0402; R_0402_5MIL_DWS
R10, R11, R12, R13: 49.9R/1%/R0402; R_0402_5MIL_DWS
R16: NA(10k/R0402); R_0402_5MIL_DWS
R17, R22: 470k/R0402; R_0402_5MIL_DWS
R24, R46, R47: 220R/R0402; R_0402_5MIL_DWS
R26: 12.1k/1%/R0402; R_0402_5MIL_DWS
R28: 0.03R/1%/R1206; R_1206_5MIL_DWS
R29: 220k/R0402; R_0402_5MIL_DWS
R30: 49.9k/1%/R0402; R_0402_5MIL_DWS
R33: 4.7R/R0402; R_0402_5MIL_DWS
R34: 5.23k/1%/R0402; R_0402_5MIL_DWS
R38: 30.1k/1%/R0402; R_0402_5MIL_DWS
R40: 10R/R0402; R_0402_5MIL_DWS
R43: NA(22R/R0603); R_0603_5MIL_DWS
R44, R49: NA/R0402; R_0402_5MIL_DWS
R45: NA(10R/R0402); R_0402_5MIL_DWS
R52: 24.9k/1%/R0402; R_0402_5MIL_DWS
R53: 1.27k/1%/62.5mW/R0402; R_0402_5MIL_DWS
R54: NA(66.5R/1%/125mW/R0805); R_0805_5MIL_DWS
R55: 4.7k/R0402; R_0402_5MIL_DWS
RM1, RM2, RM3: RA1206_(4X0603)_4B8_2.2k; R_MATRIX_4
RST1: IT1185AU2; IT1185AU2_V2
T1: LMUN2211LT1G(SOT-23); SOT23
TVS1: ESDS314DBVR(SOT-23-5); SOT-23-5
TVS2, TVS3: NA(GG0402052R542P); D_0402_5MIL_DWS
U1: CH340X(MSOP-10); MSOP-10_Pitch-0.5mm_3.00x3.00x1.00mm
U3: TP4054-42-SOT25-R(SOT23-5); SOT-23-5
U4: LAN8710A-EZC(QFN32); QFN32_EP(33)_5.00x5.00x0.90mm_Pitch_0.50mm
U5: TX4138(ESOIC-8); ESOIC-8
U6: ESP32-WROOM-32E-N4; ESP32-WROVER_MODULE
U7: TPS62A02ADRLR(SOT-563-6); SOT-563-6
U8: NA(SN74LVC1G04DBVR(SOT23-5)); SOT-23-5
U9: TPS2378DDAR(HSOIC-8); ESOIC-8
UEXT1: P-B-V-10-LF; GBH-254-SMT-10
USB-UART1: MISB-SWMM-5B-LF(USB_MICRO); USB-MICRO_MISB-SWMM-5B_LF

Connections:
+3.3V: C10.1, C22.1, EXT1.2, FET3.2, L2.2, L5.1, R2.1, R16.2, R29.2, R31.1, R32.1, R35.1, R36.1, R37.1, R39.1, R44.2, R48.1, RM3.1.2, RM3.2.2, RM3.3.2, RM3.4.2, U6.2 (VDD33(3V3)), UEXT1.1; also elsewhere on the board
+3.3VLAN: C9.1, C14.1, C28.2, FET3.3, L1.1, R25.2, RM1.3.1, RM2.1.1, RM2.2.1, RM2.3.1, RM2.4.1, U4.12 (VDDIO), U8.5 (VCC)
+5V: C1.1, CHRG1.2 (A), D1.1 (K), D3.2 (A), EXT1.1, FET1.2, FET2.1, PWR1.2 (A), R1.1, R4.1, U3.4 (VCC)
+5VP: C23.1, C25.1 (+), D1.2 (A), FET1.1, L4.2, R38.1
/+5V_USB: C7.1, FET1.3, R18.1, U1.7 (VCC), USB-UART1.1 (VBUS)
/D+: U1.1 (UD+), USB-UART1.3 (D+)
/D-: U1.2 (UD-), USB-UART1.2 (D-)
/D_Com: D2.3 (CC), R24.2, R49.2
/ESP_EN: C20.1, D9.2 (A), EXT1.4, R32.2, RST1.1, U6.3 (EN)
/GPI34\BUT1: BUT1.1, EXT2.4, R48.2, R49.1, U6.6 (GPI34/ADC1_CH6/RTC_GPIO4)
/GPI35: BAT_SENS_E1.1, EXT2.3, U6.7 (GPI35/ADC1_CH7/RTC_GPIO5)
/GPI36\U1RXD: D4.2 (A), EXT2.2, R37.2, U6.4 (GPI36/SENSOR_VP/ADC1_CH0/RTC_GPIO0)
/GPI39: EXT2.1, R4.2, R9.1, U6.5 (GPI39/SENSOR_VN/ADC1_CH3/RTC_GPIO3)
/GPIO0: D2.2 (A2), EXT1.5, R44.1, U6.25 (GPIO0/ADC2_CH1/TOUCH1/RTC_GPIO11/CLK_OU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), U8.2 (A)
/GPIO1\U0TXD: D7.1 (K), EXT1.6, U6.35 (GPIO1/U0TXD/CLK_OUT3/EMAC_RXD2)
/GPIO2\HS2_DATA0: D2.1 (A1), EXT1.7, R46.1, RM3.4.1, U6.24 (GPIO2/ADC2_CH2/TOUCH2/RTC_GPIO12/HSPIWP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), UEXT1.8
/GPIO3\U0RXD: D6.2 (A), EXT1.8, R16.1, R19.2, U6.34 (GPIO3/U0RXD/CLK_OUT2)
/GPIO4\U1TXD: EXT1.9, U6.26 (GPIO4/ADC2_CH0/TOUCH0/RTC_GPIO10/HSPIHD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), UEXT1.3
/GPIO5\SPI_CS: EXT1.10, R36.2, U6.29 (GPIO5/VSPICS0/HS1_DATA6/EMAC_RX_CLK), UEXT1.10
/GPIO12\PHY_PWR: T1.1 (B), U6.14 (GPIO12/ADC2_CH5/TOUCH5/RTC_GPIO15/MTDI/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)
/GPIO13\I2C-SDA: EXT2.10, R35.2, U6.16 (GPIO13/ADC2_CH4/TOUCH4/RTC_GPIO14/MTCK/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), UEXT1.6
/GPIO14\HS2_CLK: EXT2.9, R40.1, U6.13 (GPIO14/ADC2_CH6/TOUCH6/RTC_GPIO16/MTMS/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), UEXT1.9
/GPIO15\HS2_CMD: EXT2.8, MICRO_SD1.3 (CMD/DI), R39.2, U6.23 (GPIO15/ADC2_CH3/TOUCH3/MTDO/HSPICS0/RTC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), UEXT1.7
/GPIO16\I2C-SCL: EXT2.7, R31.2, R45.2, U6.27 (NC(GPIO16/HS1_DATA4/U2RXD/EMAC_CLK_OUT)), UEXT1.5
/GPIO17\EMAC_CLK_OUT_180: U4.5 (XTAL1/CLKIN), U6.28 (NC(GPIO17/HS1_DATA5/U2TXD/EMAC_CLK_OUT_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), U8.4 (Y)
/GPIO18\MDIO(RMII): RM2.4.2, U4.16 (MDIO), U6.30 (GPIO18/VSPICLK/HS1_DATA7)
/GPIO19\EMAC_TXD0(RMII): U4.22 (TXD0), U6.31 (GPIO19/VSPIQ/U0CTS/EMAC_TXD0)
/GPIO21\EMAC_TX_EN(RMII): U4.21 (TXEN), U6.33 (GPIO21/VSPIHD/EMAC_TX_EN)
/GPIO22\EMAC_TXD1(RMII): U4.23 (TXD1), U6.36 (GPIO22/VSPIWP/U0RTS/EMAC_TXD1)
/GPIO23\MDC(RMII): U4.17 (MDC), U6.37 (GPIO23/VSPID/HS1_STROBE)
/GPIO25\EMAC_RXD0(RMII): RM2.2.2, U4.11 (RXD0/MODE0), U6.10 (GPIO25/DAC_1/ADC2_CH8/RTC_GPIO6/EMAC_RX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)
/GPIO26\EMAC_RXD1(RMII): RM2.1.2, U4.10 (RXD1/MODE1), U6.11 (GPIO26/DAC_2/ADC2_CH9/RTC_GPIO7/EMAC_RX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)
/GPIO27\EMAC_RX_CRS_DV: RM2.3.2, U4.15 (COL/CRS_DV/MODE2), U6.12 (GPIO27/ADC2_CH7/TOUCH7/RTC_GPIO17/EMAC_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)
/GPIO32: EXT2.6, U6.8 (GPIO32/XTAL_32K_P/ADC1_CH4/TOUCH9/RTC_G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)
/GPIO33: EXT2.5, R45.1, U6.9 (GPIO33/XTAL_32K_N/ADC1_CH5/TOUCH8/RTC_G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)
/RD+: LAN_CON1.3 (RD+), R11.2, TVS1.1 (I/O1), TVS3.1 (IO1), U4.31 (RXP)
/RD-: LAN_CON1.6 (RD-), R10.2, TVS1.5 (I/O4), TVS3.2 (IO2), U4.30 (RXN)
/TD+: LAN_CON1.1 (TD+), R13.2, TVS1.3 (I/O2), TVS2.2 (IO2), U4.29 (TXP)
/TD-: LAN_CON1.2 (TD-), R12.2, TVS1.4 (I/O3), TVS2.1 (IO1), U4.28 (TXN)
GND: BAT1.2, C1.2, C2.1, C3.2, C6.2, C7.2, C8.2, C9.2, C11.2, C13.2, C14.2, C15.2, C16.2, C17.2, C18.2, C19.2, C20.2, C21.1, C22.2, C25.2 (-), C26.2, C27.2 (-), C28.1, D5.2 (A), EXT1.3, L3.2, LAN_CON1.7 (GND/NC), LAN_CON1.8 (NC/GND), MICRO_SD1.6 (GND), MICRO_SD1.CH1 (Card_Housing), R1.2, R5.2, R6.2, R7.2, R9.2, R15.2, R22.2, R26.2, R30.2, R34.2, R41.1, R42.2, R47.2, RM1.1.1, RM1.2.1, RST1.2, T1.2 (E), TVS1.2 (GND), U1.3 (GND), U3.2 (GND), U4.24 (TXD2), U4.25 (TXD3), U4.33 (GND), U5.4 (GND), U6.1 (GND), U6.15 (GND), U6.38 (GND), U6.39 (THERMAL_PAD), U7.1 (GND), U8.3 (GND), U9.5 (RTN), U9.8 (APD), UEXT1.2, USB-UART1.5 (GND)
unnamed: ACT1.2 (A), U4.3 (LED1/REGOFF)
unnamed: ACT1.1 (K), R15.1
unnamed: BAT_SENS_E1.2, C19.1, R17.2, R22.1
unnamed: BUT1.2, R47.1
unnamed: C10.2, FET3.1, R2.2, R3.1
unnamed: C12.2, R33.2
unnamed: C26.1, R43.1
unnamed: CHRG1.1 (K), R8.1
unnamed: Class4_EN1.1, R54.2
unnamed: C6.1, D3.1 (K), FET2.2, U7.3 (VIN), U7.4 (EN)
unnamed: D4.1 (K), UEXT1.4
unnamed: C12.1, D5.1 (K), L4.1, R43.2, U5.1 (SW)
unnamed: D6.1 (K), U1.8 (TXD)
unnamed: D7.2 (A), R18.2, U1.9 (RXD)
unnamed: D9.1 (K), Q2.3 (C)
unnamed: L3.1, USB-UART1.0
unnamed: C11.1, C13.1, C15.1, C16.1, L1.2, LAN_CON1.4 (TCT), LAN_CON1.5 (RCT), R10.1, R11.1, R12.1, R13.1, R14.1, U4.1 (VDD2A), U4.27 (VDD1A)
unnamed: C2.2, LAN_CON1.0 (Shield)
unnamed: LNK1.2 (A), R14.2
unnamed: LNK1.1 (K), U4.2 (LED2/NINTSEL)
unnamed: MICRO_SD1.2 (CD/DAT3/CS), RM3.2.1
unnamed: MICRO_SD1.5 (CLK/SCLK), R40.2
unnamed: MICRO_SD1.7 (DAT0/DO), R46.2
unnamed: MICRO_SD1.8 (DAT1/RES), RM3.1.1
unnamed: MICRO_SD1.1 (DAT2/RES), RM3.3.1
unnamed: C3.1, L5.2, MICRO_SD1.4 (VDD)
unnamed: PWR1.1 (K), R5.1
unnamed: Q2.1 (B), R20.2
unnamed: Q2.2 (E), R21.1, U1.4 (RTS#)
unnamed: Q3.1 (B), R21.2
unnamed: Q3.3 (C), R24.1
unnamed: Q3.2 (E), R20.1, R55.1, U1.6 (TNOW/DTR#)
unnamed: R28.1, U5.2 (ILIM), U5.9 (ILIM)
unnamed: R3.2, T1.3 (C)
unnamed: R55.2, U1.5 (CTS#)
unnamed: C8.1, R19.1, U1.10 (V3)
unnamed: R8.2, U3.1 (CHRGb)
unnamed: R6.1, U3.5 (PROG)
unnamed: BAT1.1, FET2.3, R17.1, U3.3 (VBAT)
unnamed: C21.2, R25.1, U4.19 (NRST)
unnamed: R26.1, U4.32 (RBIAS)
unnamed: RM1.1.2, U4.7 (RXCLK/PHYAD1)
unnamed: RM1.3.2, U4.9 (RXD2/RMIISEL)
unnamed: RM1.2.2, U4.8 (RXD3/PHYAD2)
unnamed: R41.2, U4.13 (RXER/RXD4/PHYAD0)
unnamed: C17.1, C18.1, U4.6 (VDDCR)
unnamed: R33.1, U5.8 (BS)
unnamed: U5.6 (EN), U9.6 (CDB)
unnamed: C23.2, R34.1, R38.2, U5.5 (FB)
unnamed 89: R29.1, R30.1, U7.5 (FB); also elsewhere on the board
unnamed: L2.1, U7.2 (SW)
unnamed: Class4_EN1.2, R53.1, U9.3 (CLS)
unnamed: R52.2, U9.2 (DEN)
Spare1: C24.1, C27.1 (+), D8.1 (K), LAN_CON1.9 (PW+), R7.1, R28.2, R42.1, R52.1, U5.3 (Vin), U9.1 (VDD)
Spare2: C24.2, D8.2 (A), LAN_CON1.10 (PW-), R53.2, R54.1, U9.4 (VSS), U9.9 (EPAD)

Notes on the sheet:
Pull-Up
Pull-Down
GPIO2:
Rising-edge:Output
HSPID
Pin
MTDO/GPIO15:
HSPI_CS1_out
Don't-care
Rprog
HSPICLK
PoE Power Supply
EMAC_COL_out
Fiducials
GPIO15/MTDO
I2CEXT0_SCL_in
I2C
I2CEXT1_SCL_in
DTR RTS->EN IO0
Software Selectable Pins
CHARGING
Rising-edge:Input
The PHY is setted up as follows: MODE: All capable(10/100Base) -Auto-negotiation enabled -RMII Configuration -SMI address: 0x00
LiPo Charger
EMAC
GPIO5
Signal
Timing of SDIO Slave
Internal Bootstrapping Resistors
Buttons
Notes:
GPIO0
I2CEXT1_SDA_in
VSPI_CS0_in/_out
Vout=0.6*(1+Ra/Rb)
RDET
MTDI/GPIO12:
Default
HSPID_in/_out
VSPI_CS2_out



Board: 4 copper layers, 28.0 x 80.0 mm, 142 parts (83 on the bottom side), 95 nets.

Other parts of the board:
C29: NA(120pF/50V/5%/C0G/C0402); C_0402_5MIL_DWS
CE: CE_Sign
Logo_OSHW: LOGO_OPENHARDWARE_8x8
Logo_Olimex: OLIMEX_LOGO_TB
Sign_Antistatic: Val**; LOGO_ANTISTATIC_1
Sign_PB-Free: LOGO_PBFREE
Sign_RecycleBin: LOGO_RECYCLEBIN_1

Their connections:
+3.3V: C29.2; also elsewhere on the board
unnamed 89: C29.1; also elsewhere on the board

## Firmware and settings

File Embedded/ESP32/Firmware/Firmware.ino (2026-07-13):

/*
 * ESP32 Enterprise Signage Controller (Firmware v2.0)
 * Architecture: MCP23017 I2C (10-Ch MOSFETs) + 3x ACS712
 * Features: Non-blocking animations, 4-State Discrepancy Logic, Modbus Offset, Dynamic Thresholds
 */

#include <ETH.h>
#include <PubSubClient.h>
#include <WiFi.h>
#include <Wire.h>
#include <Adafruit_MCP23X17.h>
#include <esp_task_wdt.h>
#include <freertos/FreeRTOS.h>
#include <freertos/task.h>
#include <freertos/queue.h>

// --- USER CONFIGURATION ----------------------------------------
const char* mqtt_server_ip = "192.168.1.10"; 
const int mqtt_port = 1883;
const int ASSIGNED_REGISTER = 40001;

IPAddress local_IP(192, 168, 1, 101); 
IPAddress gateway(192, 168, 1, 1);    
IPAddress subnet(255, 255, 255, 0);   
IPAddress primaryDNS(8, 8, 8, 8);

// --- HARDWARE PIN MAPPING (Finalized Architecture) ---
// I2C (MCP23017)
#define I2C_SDA 16
#define I2C_SCL 17
Adafruit_MCP23X17 mcp;

// Analog Sensors (ADC1 Only)
const int PIN_VOLT_PSU  = 36; 
const int PIN_VOLT_BATT = 39; 
const int PIN_CURR_LEFT = 34; // ACS712 #1 (Left Arrows)
const int PIN_CURR_RGHT = 35; // ACS712 #2 (Right Arrows)
const int PIN_CURR_ALWY = 32; // ACS712 #3 (Always ON)

// --- SENSOR CALIBRATION ---
const float ADC_REF = 3.3;
const float ALPHA   = 0.15;  // Low-pass filter

// Individual Sensor Calibration (Update these via the Calibration Tool)
const float SENS_LEFT = 0.146;
const float ZERO_LEFT = 2.400;

const float SENS_RGHT = 0.146;
const float ZERO_RGHT = 2.400;

const float SENS_ALWY = 0.146;
const float ZERO_ALWY = 2.400;

// --- BATTERY CALIBRATION ---
/*
const float BATT_R1 = 42000.0; 
const float BATT_R2 = 10000.0; 
const float K_CALIBRATION = 1.063; // Your exact multiplier from the standalone test
const float SAG_PER_STRIP = 0.05;  // CALIBRATE THIS: Voltage drop caused by 1 single LED strip
*/

// Dynamic Threshold Baseline (Minimum acceptable current for ONE single strip)
const float THRESH_PER_STRIP = 0.060; 
const float THRESHOLD_ALWY   = 0.080; // Always ON load is static

// Ethernet PHY Configuration (LAN8720)
#define ETH_PHY_ADDR  1
#define ETH_PHY_POWER -1
#define ETH_PHY_MDC   23
#define ETH_PHY_MDIO  18
#define ETH_PHY_TYPE  ETH_PHY_LAN8720
#define ETH_CLK_MODE  ETH_CLOCK_GPIO17_OUT

// --- MQTT TOPICS ---
char topic_cmd[50];
char topic_status[50];
char topic_power[50];
char topic_curr_l[50]; // Left Load
char topic_curr_r[50]; // Right Load
char topic_curr_a[50]; // Always On Load
// char topic_batt[50];          
const char* topic_scan = "metro/signage/scan"; 

WiFiClient ethClient;
PubSubClient client(ethClient);
bool eth_connected = false;

// --- STATE VARIABLES ---
volatile int currentCommand = 0; // The active MQTT integer
volatile bool expectLeftOn = false;
volatile bool expectRightOn = false;

// NEW: Track exactly how many strips are currently lit to calculate battery sag
// volatile int totalActiveStrips = 0; 

// Shared threshold variables that Core 1 updates and Core 0 reads
volatile float dynamicThreshLeft = THRESH_PER_STRIP;
volatile float dynamicThreshRight = THRESH_PER_STRIP;

// Mailbox Queue for Core 0 to pass 4-state strings to Core 1
struct NodeStateMsg {
    bool power_ok;
    // int batt_pct;
    const char* state_left;
    const char* state_right;
    const char* state_alwy;
};
QueueHandle_t sensorQueue;
NodeStateMsg networkState = {true, "---", "---", "---"};

// Animation Bitmasks
const uint8_t chaseFrames[5] = {0x07, 0x0E, 0x1C, 0x19, 0x13};
const int numFrames = 5;

// ========================================================
// CORE 1: NETWORKING & MCP23017 ANIMATION MACHINE
// ========================================================

void eth_event_handler(arduino_event_id_t event) {
  switch (event) {
    case ARDUINO_EVENT_ETH_GOT_IP: eth_connected = true; break;
    case ARDUINO_EVENT_ETH_DISCONNECTED: eth_connected = false; break;
    default: break;
  }
}

void publish_state_msg(NodeStateMsg msg) {
  char onlineMsg[30];
  snprintf(onlineMsg, sizeof(onlineMsg), "ONLINE:%s", ETH.localIP().toString().c_str());
  client.publish(topic_status, onlineMsg, true);
  
  client.publish(topic_power, msg.power_ok ? "OK" : "FAIL", true);
  client.publish(topic_curr_l, msg.state_left, true);
  client.publish(topic_curr_r, msg.state_right, true);
  client.publish(topic_curr_a, msg.state_alwy, true);

  /*
  if (msg.batt_pct != -1) {
    char bStr[8];
    snprintf(bStr, sizeof(bStr), "%d", msg.batt_pct);
    client.publish(topic_batt, bStr, true);
  }
  */
}

void callback(char* topic, byte* payload, unsigned int length) {
  char msgBuffer[16]; 
  unsigned int copyLength = (length < sizeof(msgBuffer) - 1) ? length : (sizeof(msgBuffer) - 1);
  memcpy(msgBuffer, payload, copyLength);
  msgBuffer[copyLength] = '\0'; 

  if (strcmp(topic, topic_scan) == 0 && strcmp(msgBuffer, "PING") == 0) {
    publish_state_msg(networkState); 
    return;
  }

  // Update Global Command (The animation loop handles the actual hardware writing)
  currentCommand = atoi(msgBuffer); 
  Serial.printf("Command Updated: %d\n", currentCommand);
}

// Helper to mathematically count how many MOSFETs are active in the raw bitmask
int countActiveStrips(uint8_t portMask) {
  int count = 0;
  while (portMask) { count += portMask & 1; portMask >>= 1; }
  return count;
}

void runAnimationStateMachine() {
  static unsigned long previousMillis = 0;
  static int currentFrame = 0;      
  static int lastExecutedCommand = -1; 
  unsigned long currentMillis = millis();

  // --- MODE A: MACRO ANIMATIONS (0 to 4) ---
  if (currentCommand >= 0 && currentCommand <= 4) {
    if (currentMillis - previousMillis >= 300 || currentCommand != lastExecutedCommand) {
      previousMillis = currentMillis;
      lastExecutedCommand = currentCommand;

      switch (currentCommand) {
        case 0: 
          mcp.writeGPIOA(0x00); mcp.writeGPIOB(0x00); 
          expectLeftOn=false; expectRightOn=false; 
          // totalActiveStrips = 0;
          break;
        case 1: 
          mcp.writeGPIOA(chaseFrames[currentFrame]); mcp.writeGPIOB(0x00); 
          expectLeftOn=true; expectRightOn=false; 
          dynamicThreshLeft = THRESH_PER_STRIP * 2.5; // Expecting ~3 strips to be ON
          // totalActiveStrips = 3;
          break;
        case 2: 
          mcp.writeGPIOA(0x00); mcp.writeGPIOB(chaseFrames[currentFrame]); 
          expectLeftOn=false; expectRightOn=true; 
          dynamicThreshRight = THRESH_PER_STRIP * 2.5; // Expecting ~3 strips to be ON
          // totalActiveStrips = 3;
          break;
        case 3: 
          mcp.writeGPIOA(chaseFrames[currentFrame]); mcp.writeGPIOB(chaseFrames[currentFrame]); 
          expectLeftOn=true; expectRightOn=true; 
          dynamicThreshLeft = THRESH_PER_STRIP * 2.5; 
          dynamicThreshRight = THRESH_PER_STRIP * 2.5;
          // totalActiveStrips = 6;
          break;
        case 4: 
          mcp.writeGPIOA(0x1F); mcp.writeGPIOB(0x1F); 
          expectLeftOn=true; expectRightOn=true; 
          dynamicThreshLeft = THRESH_PER_STRIP * 4.5; // Solid ON expects all 5 strips
          dynamicThreshRight = THRESH_PER_STRIP * 4.5; 
          // totalActiveStrips = 10;
          break; 
      }
      currentFrame = (currentFrame + 1) % numFrames;
    }
  }
  
  // --- MODE B: RAW BITMASK (10000 to 11023) ---
  else if (currentCommand >= 10000 && currentCommand <= 11023) {
    if (currentCommand != lastExecutedCommand) {
      lastExecutedCommand = currentCommand;
      int bitmask = currentCommand - 10000; 
      
      uint8_t portA = bitmask & 0x1F;        
      uint8_t portB = (bitmask >> 5) & 0x1F; 
      
      mcp.writeGPIOA(portA);
      mcp.writeGPIOB(portB);

      // Inform Core 0 of our intentions for discrepancy logic
      expectLeftOn = (portA > 0);
      expectRightOn = (portB > 0);

      // Calculate exact dynamic thresholds based on how many bits are 1
      int activeLeft = countActiveStrips(portA);
      int activeRight = countActiveStrips(portB);
      
      // totalActiveStrips = activeLeft + activeRight;

      if (activeLeft > 0) dynamicThreshLeft = THRESH_PER_STRIP * (activeLeft - 0.5);
      if (activeRight > 0) dynamicThreshRight = THRESH_PER_STRIP * (activeRight - 0.5);
    }
  }
}


// ========================================================
// CORE 0: HARDWARE DSP & 4-STATE DISCREPANCY LOGIC
// ========================================================

int getMedianADC(int pin) {
  int samples[51]; 
  for (int i = 0; i < 51; i++) samples[i] = analogRead(pin);
  for (int i = 1; i < 51; i++) {
    int key = samples[i]; int j = i - 1;
    while (j >= 0 && samples[j] > key) { samples[j + 1] = samples[j]; j = j - 1; }
    samples[j + 1] = key;
  }
  return samples[25]; 
}

// The core engine for the 4-State Output
const char* getDiscrepancyState(bool expectedOn, float actualCurrent, float threshold) {
  if (expectedOn && actualCurrent >= threshold) return "ON";
  if (!expectedOn && actualCurrent < threshold) return "OFF";
  if (expectedOn && actualCurrent < threshold) return "FAIL_OPEN";
  return "FAIL_SHORT"; 
}

void SensorTask(void * parameter) {
  esp_task_wdt_add(NULL); 
  NodeStateMsg currentState = {true, "---", "---", "---"};
  
  float filt_l = 0.0, filt_r = 0.0, filt_a = 0.0;
  unsigned long lastReadTime = 0;

  for(;;) {
    esp_task_wdt_reset(); 
    bool changed = false;

    if (millis() - lastReadTime >= 500) {
      lastReadTime = millis();

      // 1. Power Monitor
      bool pwrRead = (getMedianADC(PIN_VOLT_PSU) > 1800);
      if (currentState.power_ok != pwrRead) { currentState.power_ok = pwrRead; changed = true; }

      // 2. Read ACS712 Sensors with Individual Calibration Math
      float curr_l = abs((((getMedianADC(PIN_CURR_LEFT) / 4095.0) * ADC_REF) - ZERO_LEFT) / SENS_LEFT);
      float curr_r = abs((((getMedianADC(PIN_CURR_RGHT) / 4095.0) * ADC_REF) - ZERO_RGHT) / SENS_RGHT);
      float curr_a = abs((((getMedianADC(PIN_CURR_ALWY) / 4095.0) * ADC_REF) - ZERO_ALWY) / SENS_ALWY);
      
      filt_l = (curr_l < 0.06) ? 0 : (curr_l * ALPHA) + (filt_l * (1 - ALPHA));
      filt_r = (curr_r < 0.06) ? 0 : (curr_r * ALPHA) + (filt_r * (1 - ALPHA));
      filt_a = (curr_a < 0.06) ? 0 : (curr_a * ALPHA) + (filt_a * (1 - ALPHA));

      // 3. Apply 4-State Logic using DYNAMIC thresholds
      // Note: Always On is expected to always be true!
      const char* state_l = getDiscrepancyState(expectLeftOn, filt_l, dynamicThreshLeft);
      const char* state_r = getDiscrepancyState(expectRightOn, filt_r, dynamicThreshRight);
      const char* state_a = getDiscrepancyState(true, filt_a, THRESHOLD_ALWY);

      if (strcmp(currentState.state_left, state_l) != 0 || 
          strcmp(currentState.state_right, state_r) != 0 || 
          strcmp(currentState.state_alwy, state_a) != 0) {
        
        currentState.state_left = state_l;
        currentState.state_right = state_r;
        currentState.state_alwy = state_a;
        changed = true;
      }

      /* --- DYNAMIC BATTERY SAG COMPENSATION (TEMPORARILY DISABLED) ---
      float pinVoltage = (getMedianADC(PIN_VOLT_BATT) / 4095.0) * ADC_REF;
      float rawBattVoltage = pinVoltage * ((BATT_R1 + BATT_R2) / BATT_R2) * K_CALIBRATION;
      
      // Add compensation: total active I2C strips + 1 for the Always ON strip
      float compBattVoltage = rawBattVoltage + ((totalActiveStrips + 1) * SAG_PER_STRIP);
      
      int pct = 0;
      if (compBattVoltage >= 12.1) pct = 100;
      else if (compBattVoltage >= 11.5) pct = 50;
      else pct = 0;

      if (currentState.batt_pct != pct) {
        currentState.batt_pct = pct;
        changed = true;
      }
      */

      if (changed) xQueueOverwrite(sensorQueue, &currentState); 
    }
    vTaskDelay(pdMS_TO_TICKS(10)); 
  }
}


// ========================================================
// SETUP & MAIN LOOP
// ========================================================

void setup() {
  Serial.begin(115200);
  
  // Initialize I2C and MCP23017
  Wire.begin(I2C_SDA, I2C_SCL);
  if (!mcp.begin_I2C(0x20, &Wire)) {
    Serial.println("FATAL ERROR: MCP23017 not found!");
    while(1);
  }
  for (int i = 0; i < 16; i++) mcp.pinMode(i, OUTPUT);
  mcp.writeGPIOA(0x00); mcp.writeGPIOB(0x00);

  // Initialize Analog Pins
  pinMode(PIN_VOLT_PSU, INPUT); pinMode(PIN_VOLT_BATT, INPUT);
  pinMode(PIN_CURR_LEFT, INPUT); pinMode(PIN_CURR_RGHT, INPUT); pinMode(PIN_CURR_ALWY, INPUT);
  analogReadResolution(12); analogSetAttenuation(ADC_11db);

  // Networking Topic Generation
  sprintf(topic_cmd, "metro/signage/register/%d/value", ASSIGNED_REGISTER);
  sprintf(topic_status, "metro/signage/register/%d/status", ASSIGNED_REGISTER);
  sprintf(topic_power, "metro/signage/register/%d/power", ASSIGNED_REGISTER);
  sprintf(topic_curr_l, "metro/signage/register/%d/current1", ASSIGNED_REGISTER);
  sprintf(topic_curr_r, "metro/signage/register/%d/current2", ASSIGNED_REGISTER);
  sprintf(topic_curr_a, "metro/signage/register/%d/current3", ASSIGNED_REGISTER); // The 3rd load
  // sprintf(topic_batt, "metro/signage/register/%d/battery_pct", ASSIGNED_REGISTER); 

  // Initialize Ethernet
  WiFi.onEvent(eth_event_handler);
  ETH.begin(ETH_PHY_TYPE, ETH_PHY_ADDR, ETH_PHY_MDC, ETH_PHY_MDIO, ETH_PHY_POWER, ETH_CLK_MODE);
  ETH.config(local_IP, gateway, subnet, primaryDNS);
  client.setServer(mqtt_server_ip, mqtt_port);
  client.setCallback(callback);

  // Create the Mailbox for IPC
  sensorQueue = xQueueCreate(1, sizeof(NodeStateMsg));
  
  // Initialize Watchdog Timer
  esp_task_wdt_config_t wdt_config = { .timeout_ms = 15000, .idle_core_mask = (1<<portNUM_PROCESSORS)-1, .trigger_panic = true };
  esp_task_wdt_init(&wdt_config);
  esp_task_wdt_add(NULL); 

  // Spin up Core 0
  xTaskCreatePinnedToCore(SensorTask, "SensorTask", 10000, NULL, 1, NULL, 0);
}

void loop() {
  esp_task_wdt_reset();

  if (eth_connected) {
    if (!client.connected()) {
      static unsigned long lastReconnect = 0;
      if (millis() - lastReconnect > 5000) {
        lastReconnect = millis();
        char clientId[30]; snprintf(clientId, sizeof(clientId), "ESP32-%s", ETH.macAddress().c_str());
        
        // Connect with Last Will and Testament
        if (client.connect(clientId, topic_status, 1, true, "OFFLINE")) {
          client.subscribe(topic_cmd, 1);
          client.subscribe(topic_scan, 0);
          publish_state_msg(networkState);
        }
      }
    } else {
      client.loop(); 
      runAnimationStateMachine(); // Core 1 cleanly executes the LED sequence
      
      // Check the mailbox for new sensor updates from Core 0
      NodeStateMsg tempMsg;
      if (xQueueReceive(sensorQueue, &tempMsg, 0) == pdTRUE) {
        networkState = tempMsg;
        publish_state_msg(networkState);
      }
    }
  }
}

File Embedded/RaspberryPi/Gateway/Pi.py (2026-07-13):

import paho.mqtt.client as mqtt
from pymodbus.server import StartTcpServer
from pymodbus.datastore import ModbusSequentialDataBlock, ModbusSlaveContext, ModbusServerContext
from threading import Thread, Lock, Event
import time
import sys

# --- Configuration ---
MODBUS_PORT = 502
MQTT_BROKER_HOST = "0.0.0.0"
MQTT_PORT = 1883
MQTT_TOPIC_PREFIX = "metro/signage/register"
REGISTERS_TO_BRIDGE = 100 # Scaled for up to 100 ESP32 nodes on the fiber ring

# Dictionaries to store status
device_statuses = {}       # Stores ONLINE/OFFLINE
device_power_states = {}   # Stores Power Supply Status (OK/FAIL)
device_current1 = {}       # Stores LHS LED Status (ON/OFF/FAIL_OPEN/FAIL_SHORT)
device_current2 = {}       # Stores RHS LED Status (ON/OFF/FAIL_OPEN/FAIL_SHORT)
device_current3 = {}       # Stores Static LED Status (ON/OFF/FAIL_OPEN/FAIL_SHORT)
device_batt_pct = {}       # Stores Battery Percentage (100, 50, 0)

# Thread safety lock for the dictionaries
data_lock = Lock()
# Event to track MQTT connection status
mqtt_connected_event = Event()

# Helper to map ESP32 4-State strings to Modbus Integers for SCADA
def map_discrepancy_to_int(state_str):
    if state_str == "OFF": return 0
    if state_str == "ON": return 1
    if state_str == "FAIL_OPEN": return 2
    if state_str == "FAIL_SHORT": return 3
    return 99 # Unknown/Error state

def on_message(client, userdata, msg):
    """Callback for incoming MQTT messages"""
    try:
        topic_parts = msg.topic.split('/')
        if len(topic_parts) == 5:
            register_address = int(topic_parts[3])
            msg_type = topic_parts[4]
            payload = msg.payload.decode()

            with data_lock:
                if msg_type == "status":
                    device_statuses[register_address] = payload
                    if payload == "OFFLINE":
                        # Offline Scrubbing: Clear old data so SCADA doesn't read stale values
                        device_power_states[register_address] = "---"
                        device_current1[register_address] = "---"
                        device_current2[register_address] = "---"
                        device_current3[register_address] = "---"
                        device_batt_pct[register_address] = "---"
                
                elif msg_type == "power":
                    device_power_states[register_address] = payload
                
                elif msg_type == "current1":
                    device_current1[register_address] = payload
                
                elif msg_type == "current2":
                    device_current2[register_address] = payload
                    
                elif msg_type == "current3":
                    device_current3[register_address] = payload
                
                elif msg_type == "battery_pct":
                    device_batt_pct[register_address] = payload

    except Exception as e:
        pass # Silently drop malformed MQTT packets so the bridge doesn't crash

def on_connect(client, userdata, flags, rc):
    if rc == 0:
        client.subscribe(f"{MQTT_TOPIC_PREFIX}/+/status")
        client.subscribe(f"{MQTT_TOPIC_PREFIX}/+/power")
        client.subscribe(f"{MQTT_TOPIC_PREFIX}/+/current1")
        client.subscribe(f"{MQTT_TOPIC_PREFIX}/+/current2")
        client.subscribe(f"{MQTT_TOPIC_PREFIX}/+/current3")
        client.subscribe(f"{MQTT_TOPIC_PREFIX}/+/battery_pct")
        mqtt_connected_event.set()  # Signal successful connection

def perform_startup_cleanup(client):
    """Purges ghost messages from the broker on startup"""
    for i in range(REGISTERS_TO_BRIDGE):
        addr = 40001 + i
        client.publish(f"{MQTT_TOPIC_PREFIX}/{addr}/status", "OFFLINE", retain=True)
        client.publish(f"{MQTT_TOPIC_PREFIX}/{addr}/power", "---", retain=True)
        client.publish(f"{MQTT_TOPIC_PREFIX}/{addr}/current1", "---", retain=True)
        client.publish(f"{MQTT_TOPIC_PREFIX}/{addr}/current2", "---", retain=True)
        client.publish(f"{MQTT_TOPIC_PREFIX}/{addr}/current3", "---", retain=True)
        client.publish(f"{MQTT_TOPIC_PREFIX}/{addr}/battery_pct", "---", retain=True)
        
        with data_lock:
            device_statuses[addr] = "OFFLINE"
            device_power_states[addr] = "---"
            device_current1[addr] = "---"
            device_current2[addr] = "---"
            device_current3[addr] = "---"
            device_batt_pct[addr] = "---"
        
    client.publish("metro/signage/scan", "PING", retain=False)
    time.sleep(2)

def bridge_and_display_loop(modbus_context, mqtt_client):
    last_known_values = [None] * REGISTERS_TO_BRIDGE
    last_ping_time = time.time()

    # Clear the screen entirely just ONCE before the loop starts
    if sys.stdout.isatty():
        sys.stdout.write('\033[2J')

    while True:
        try:
            # --- ESP32 WATCHDOG PING ---
            if time.time() - last_ping_time > 60:
                mqtt_client.publish("metro/signage/scan", "PING", retain=False)
                last_ping_time = time.time()

            # --- MUX LOGIC (Hand/Off/Auto) ---
            # Read Control Flag (43001 -> Address 3000)
            mux_flag = modbus_context[0].getValues(3, 3000, count=1)[0]

            if mux_flag == 1:
                # Manual/HMI Mode: Copy 41001+ (Address 1000) to 40001+ (Address 0)
                hmi_values = modbus_context[0].getValues(3, 1000, count=REGISTERS_TO_BRIDGE)
                modbus_context[0].setValues(3, 0, hmi_values)
            else:
                # Auto/SCADA Mode: Copy 42001+ (Address 2000) to 40001+ (Address 0)
                scada_values = modbus_context[0].getValues(3, 2000, count=REGISTERS_TO_BRIDGE)
                modbus_context[0].setValues(3, 0, scada_values)
            # -----------------------------

            # Now read the ACTUAL output zone (40001+)
            current_values = modbus_context[0].getValues(3, 0, count=REGISTERS_TO_BRIDGE)
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

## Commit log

2026-05-06 Added version history for the ESP32 and the Raspberrypi codes along with the documentation in .md files
2026-05-06 Made a builds folder, for the currently working setup 1.Battery 2. V1 of the HMI 3. Pi without the ON/OFF fucntionality
2026-05-06 Uploaded the latest windows form application v1.3; Upload the latest documentation; Also uploaded the Customized Arduino code of the firmware - under development.
2026-06-03 Initial COmmit of the PCB Design files
    [5v_relay_module.kicad_pcb, 5v_relay_module.sch, ACS712.kicad_pcb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]
2026-06-07 Changes Part 1 for the PCB Files
    Most recent update for the PCB Design
    [5v_relay_module.kicad_sch, ACS712.kicad_pcb, ACS712.kicad_sch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]
2026-06-07 Updatign the files of the PCB folder
    - seld design modules completed, with the correct math
    - schematic for pcb v2 completed
    [PCB_V2.kicad_sch]
2026-06-08 Updated the documentation in the software Node Calibration
2026-06-10 Pushing most recent changes - 10/6/2026
    1. Finished the schematics of all the individual modules
    2. Made the changes to errors and the hierarchal issues for the MP1584
    3. Fixed the open connections for the OLIMEX ESP32 and the labeling for the same
    TO DO//
    1. Check the current warnings while running ERC (single label warnings and the no connect ones)
    2. The tracing and component placement needs to be finalised
    3. EMI/EMC placement for the modules needs to be kept in mind with a priority
    [MP1584ENCircuit.kicad_sch, PCB_V2.kicad_sch]
2026-06-11 Uploading the old plug and play PCB files into the PCB folder
    1. Added the old PCB files into the PCB folder
    2. Made minute changes to the original PCB
    [ACS712_module.step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]
2026-06-18 Created version history
    1. Version history for the ESP32
    2. Version history for the current pi code
    3. Added the animation code into testing and calibration
    Will add the new ESp32 and the Raspberrypi code next, so created a backup of current progress
2026-06-22 Pushing the boilerplate code for the new ESP32 and RaspberryPI codes
    1. This is the first set of the codes of the ESP32 and the RaspberryPi
    2. The proper merged code and documentation will be provided in the next commit. That will include boilerplate code + the communication fucntionality
    3. The rest of the thought process and the documentation is provided in the WA group, will add the Ipad notes, as running notes later on as well
    [PCB_V2.kicad_pcb]
2026-06-22 Updating the updated code for the ESP32 and the Raspberrypi
    Updated code with final functionality of the LED animation, communication updated here:
    1. The documentation is in the .md file of each pi and esp32
2026-06-26 Uploading the recent batch of files
    1. Schematic of the new PCB (ESP32 and LAN connections need to be made )
    2. Data sheets for the components
    3. Connection .md file
    [PCB_V3.kicad_pcb, PCB_V3.kicad_sch]
2026-06-27 Committing the Final schematic file along with the
    1. ESP32 connections made along with the LAN8720 module
    2. Footprints assigned for all the individual components
    3. Need to recheck and analyse the connections a 3rd and 4th time
    5. Need to figure out component placement, on the PCB and close the tracing
    [PCB_V3.kicad_sch]
2026-06-29 Uploading the JTAG files and updated the footprints for the resistors
    [PCB_V3_JTAG.kicad_pcb, PCB_V3_JTAG.kicad_sch]
2026-07-02 corrected a fe thing sin the schematic file
    1. Some of the MCP outputs were wrongly marked, so corrected that
    2. B0 and BO were incorrectly marked, corrected that
    3. Assigned the appropriate footprint for the JTAG pins
    4. changed the MCp from 2 induvidual pins for A0 B0, to a single 02x10 connector
    [PCB_V3_JTAG.kicad_sch]
2026-07-02 Updated the schematic and fixed the PCB viewer 3D models
    1. Schematic finalization
    2. PCB 3D models, berg stick removal
    [PCB_V3_JTAG.kicad_pcb, PCB_V3_JTAG.kicad_sch]
2026-07-06 PCB commit
    1. Pins need to be named
    2. There are courtyard errors that need to be looked into for the split connectors (2x0)
    3. Connections of the negative of the LEDs to the MOSFETs need to be made
    [ACS712.FCStd, AMS1117.stp, AMS1117_pin.stp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]
2026-07-09 Uploading the final iteration of the PCB design files
    [PCB_V3_Final.kicad_pcb, PCB_V3_Final.kicad_sch, PCB_V3_JTAG.kicad_pcb]
2026-07-13 Uploading the final PCB files
    1. Finished product
    2. Made the remaining connections
    3. Added the mounting holes for the PCB
    4. Final producct --> has to be reviewed in the meeting
    [PCB_V3_Final.kicad_pcb, PCB_V3_Final.kicad_sch]
2026-07-13 Created and finished coding the firmware_test.ino file
    1. Added a README file in the testing folder, that shows all the details of the hardware and software fucntionality
    2. Created a test code for testing hardware first
    3. Adding a testing criteria document for details of what is getting tested and how to test teh hardware using this code
    [PCB_V3_Final.kicad_pcb]
2026-07-14 Added the Pi_agent document and created version control
    1. pi_agent.md got added - the initial set up of the pi is done and this document holds all the information of the raspeberrypi
    2. Version control backups for the raspberrypi code and the hmi code current versions
2026-07-16 Final PCB Upload
    1. Made all the changes
    2. final PCB files and the gerber files uploaded
    [PCB_V3_Final-B_Cu.gbl, PCB_V3_Final-B_Mask.gbs, PCB_V3_Final-B_Paste.gbp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]

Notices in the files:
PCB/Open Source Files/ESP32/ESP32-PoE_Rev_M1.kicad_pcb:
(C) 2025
